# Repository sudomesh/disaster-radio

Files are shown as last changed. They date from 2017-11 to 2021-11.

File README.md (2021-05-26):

[disaster.radio](https://disaster.radio) is currently not actively developed and [seeks a new maintainer](https://github.com/sudomesh/disaster-radio/issues/110)

It is a work-in-progress long-range, low-bandwidth wireless disaster recovery mesh network powered by the sun. 

  

* [firmware/](./firmware) contains the main example code for ESP32 dev boards
* [src/](./src) contains the disaster radio library code used by the firmware and simulator
* [web/](./web) is the demo chat app served up by the disaster-radio
* [hardware/](./hardware) is the kicad board layout and schematic
* [enclosure/](./enclosure) are 3D models of the enclosure(s)
* [android app](https://github.com/beegee-tokyo/disaster-radio-android) source code for [DisasterRadio BLE Chatbox](https://play.google.com/store/apps/details?id=tk.giesecke.disaster_radio&hl=en_US) Android Application
* [mapping web app](https://github.com/sudomesh/disaster-radio-map) source code for mapping web-based appilcation

## Table of contents
- [Getting Started](#getting-started)
- [Layout and Flow](#layout-and-flow)
- [Hardware Connections](#hardware-connections)
- [Initial Setup with PlatformIO](#initial-setup-with-platformio)
    - [Building firmware](#building-firmware)
    - [Flashing firmware](#flashing-firmware)
        - [For dev boards](#for-dev-boards)
- [Building Web App](#building-web-app)
    - [Building and uploading SPIFFS image](#building-and-uploading-SPIFFS-image)
- [Testing Firmware](#testing-firmware) 
- [Adding Libraries](#adding-libraries)
- [Creating Binary for Release](#creating-binary-for-release)
- [License](#license)

# Getting Started
The quickest way to get started with disaster.radio is to buy a <a href="https://www.aliexpress.com/item/4000396836096.html" target="_blank">preinstalled device</a> or
* Download the [latest release](https://github.com/sudomesh/disaster-radio/releases)
* Unzip the `disaster-radio-0.X.X.zip` file
* Follow the included instructions for flashing it to your device

If you would rather test the latest, cutting-edge developments, you can compile the firmware yourself by cloning this repo and following the [initial setup](#initial-setup-with-platformio) instructions.

# Layout and Flow
The Disaster Radio firmware is made up of a single "server" and a number of "clients", as well as "middleware" that sits between the clients and server. These are a"server" and "clients" in the logical, software sense, not a literal, networking sense.
 
Here are the modules currently implemented with descriptions of their purpose:
- DisasterServer:  
    - DisasterRadio: the main "server" that takes messages from clients and sends them to other clients

- DisasterClient:  
    - LoRaClient: interfaces with LoRaLayer2  
    - WebSocketClient: WebSocket connections from the web app  
    - StreamClient: for Arduino Stream, currently used for serial console  
    - TCPClient: for a telnet-like server  
    - HistoryRecord: records messages to SD card (or bounded queue in memory)  
    - OLEDClient: displays messages on the screen (mostly for debugging purposes, but eventually I'd like to use this for a mobile Disaster Radio terminal of some kind)   
    - GPSClient: proof-of-concept, interfaces with a serial GPS module to beacon your current location periodically  

- DisasterMiddleware:  
    - WelcomeMessage: (very simple, in main.cpp) shows a welcome message to clients when they connect
    - HistoryReplay: shows history to clients when they connect
    - Console: implements a simple console with chat (similar to the web app) plus some /commands (I went with a more IRC-like syntax but you could easily implement a getopt version)
    
- DisasterHistory:
    - HistorySD: records history to SD card
    - HistoryMemory: records history to a bounded queue in memory (default limit 10 messages)

The server and clients communicate with each other using "datagrams" that include a destination address, a message type, and a message. Read more about the disaster radio networking stack on our wiki, https://github.com/sudomesh/disaster-radio/wiki/Layered-Model.

# Hardware Connections  

For supported development boards see the [Devices & Hardware](https://github.com/sudomesh/disaster-radio/wiki/Devices--&-Hardware) wiki page.  

The pinouts for supported boards can be found in [firmware/esp32/config.h](https://github.com/sudomesh/disaster-radio/blob/master/firmware/esp32/config.h).  

DIO0 sends an interrupt from the LoRa transceiver upon Tx/Rx Ready on the radio.   
Chip selects can be used to explicitly switch between the LoRa tranceiver and the SD card; however, the SD card should be enabled by default, as the LoRa interrupt appears to handle enabling the transceiver (note: this still needs to be thoroughly tested, what happens if you receive an interrupt while loading from the SD?).  

# Initial Setup with PlatformIO

```
pip install -U platformio
```

Edit `platformio.ini` to suit your needs. If you are flashing a ESP32 LILY TTGO board then you will probably not have to edit anything in `platformio.ini` but make sure `upload_port` is set to the correct device which may vary depending on your operating system and which other devices you have connected.

## Building firmware

To test that the firmware is compiling correctly without flashing it to a device, run
```
pio run
```

This will compile all libraries and main firmware files. The resulting binary is stored as `.pio/build/ttgo-lora32-v1/firmware.bin`

## Flashing firmware

### For dev boards

Connect your computer to the board using a usb cable,

In `platformio.ini` make sure `upload_port`, `upload_speed`, etc are correct for your device.

Then run:

```
pio run -t upload
```
 
By default, PlatformIO builds and flashes firmware for the LILY's ESP32 TTGO V2 dev board. If you would like to build for another supported board, select the corresponding build environment. For example to build and flash the firmware and file system for the ESP32 TTG0 V1 board, use the following, 

```
pio run -e ttgo-lora32-v1 -t upload -t uploadfs

```

## Developing firmware

Some useful hints for developing this firmware using platformio are included here,
* It may be a good idea to delete the libdeps folder prior to rebuilding, as old, out-dated libraries could case conflits. To do this, `rm -rf .pio/libdeps`.
* If you would like to make changes to a specific library, such as LoRaLayer2, you can clone the library into the `firmware/lib` folder that is created after running `pio run` and then comment it out or remove it from the `lib_deps` list in the `platformio.ini` file.

# Building Web App

First, build the web app using npm, instructions for can be found in [web/README.md](https://github.com/sudomesh/disaster-radio/tree/master/web#setup).

If you have trouble building the web app with npm, you can download a pre-built version of web app as part of the [latest release](https://github.com/sudomesh/disaster-radio/releases). Then, copy the files in `web/static/` from the zipped release to the `web/static/` directory in the cloned repo.

## Building and uploading SPIFFS image

Next, build the binary for the SPIFFS and upload it to your board.

To only build:

```
pio run -t buildfs
```

To build and upload:

```
pio run -t uploadfs
```

If using an SD card, copy the contents of `web/static/` to the root of a fat32 formatted SD card, then insert the SD card.

# Testing Firmware  
Once the firmware and SPIFFS image has been successfully flashed, you can test it by logging into the `disaster.radio <node-address>` wireless network and navigating to http://192.168.4.1 in a browser to access the demo chat app.  

You can also try connecting to the device via serial or telnet with commands like,  
```
pio device monitor
```
or
```
telnet 192.168.4.1
```

After pressing enter once, you should be greeted with a banner and presented with a prompt to enter a nick or send an anonymous message,
```
     ___              __                            ___    
 ___/ (_)__ ___ ____ / /____ ____      _______ ____/ (_)__ 
/ _  / (_-</ _ `(_-</ __/ -_) __/ _   / __/ _ `/ _  / / _ \
\_,_/_/___/\_,_/___/\__/\__/_/   (_) /_/  \_,_/\_,_/_/\___/
v1.0.0-rc.2
LoRa transceiver connected
Local address of your node is 1d69bd4c
Type '/join NICKNAME' to join the chat, or '/help' for more commands.
< > 
```

See [firmware/README.md](https://github.com/sudomesh/disaster-radio/tree/master/firmware) for more debugging information.

# Adding Libraries

If you're including new libraries in the firmware, for PlatformIO, you wil need to add them to `platformio.ini` under `lib_deps`.

# Creating Binary for Release

A full binary image can be created by reading the flash contents of a ESP32 that is flashed with the latest release of the firmware.
To do this, run the following command,
```
esptool.py -p /dev/ttyUSB0 -b 921600 read_flash 0 0x400000 esp_flash.bin
```

This can then be flashed to a new device like so,
```
esptool.py -p /dev/ttyUSB0 --baud 460800 write_flash 0x00000 esp_flash.bin
```

# License

* `firmware/`: Dual licensed under both GPLv3 and AGPLv3
* `web/`: AGPLv3

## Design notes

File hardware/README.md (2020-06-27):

# Hardware

The disaster.radio hardware is as open-as-possible. Currently, we have the schematic, BOM, and circuit board design for a development board that you can, theoretically, print yourself or order from a circuit board manufacturer of your choice. 

## Features
* ESP32-WROOM integrated WiFi + BLE microcontroller
* Dual LoRa modules
* Micro-SD card slot
* Micro-USB port for serial debugging
* Battery connection
* Battery charging module (currently using TPS6216)

## Developement
Our hardware was designed in KiCad, if you would like to edit the board deisgn or take a closer look at the schematics you can [download and install KiCad](https://kicad-pcb.org/download/) for your system.

After installing, open KiCad, choose `File > Open Project...`, navigate to where you cloned this repo, and select the file `hardware/board_esp32_v2/board_esp32_v2.pro`. You can now open and view the schematic and pcb design.

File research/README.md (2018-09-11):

research regarding disaster radio, lora modulation, and network stacks  

none of the material in this directory is licensed to sudomesh unless otherwise noted

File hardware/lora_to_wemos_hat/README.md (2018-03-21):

# lora-to-nodemcu-circuit

KiCad Circuit board for a Lora (RFM95) to the Wemo D1 Mini ESP8266 board connector for playing around with the two technologies. This board acts as a hat for the Wemo, and contains the lora chip, antenna and power circuits for powering the lora chip off of the 5v coming off of the Wemo's usb power.
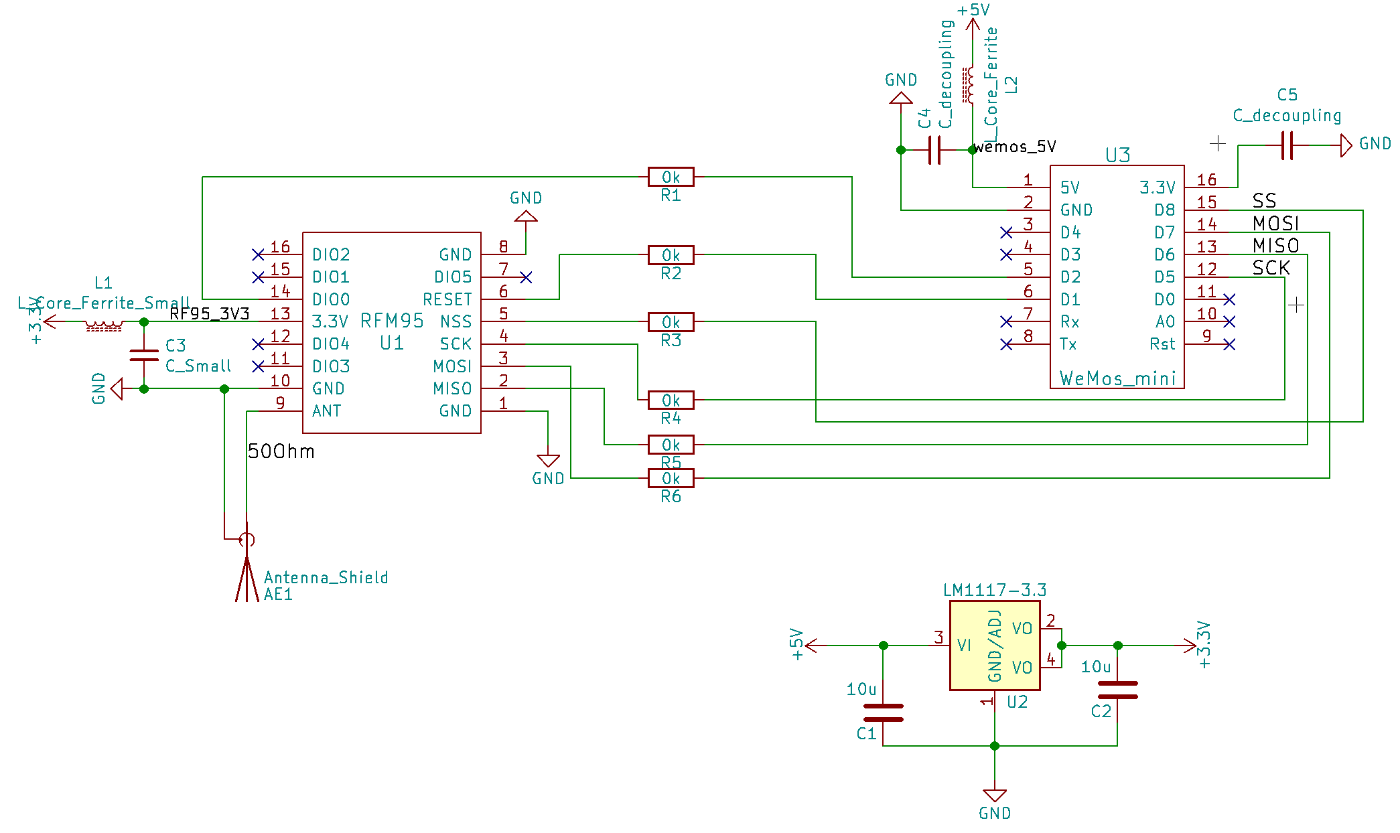
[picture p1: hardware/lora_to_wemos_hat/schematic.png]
schematic

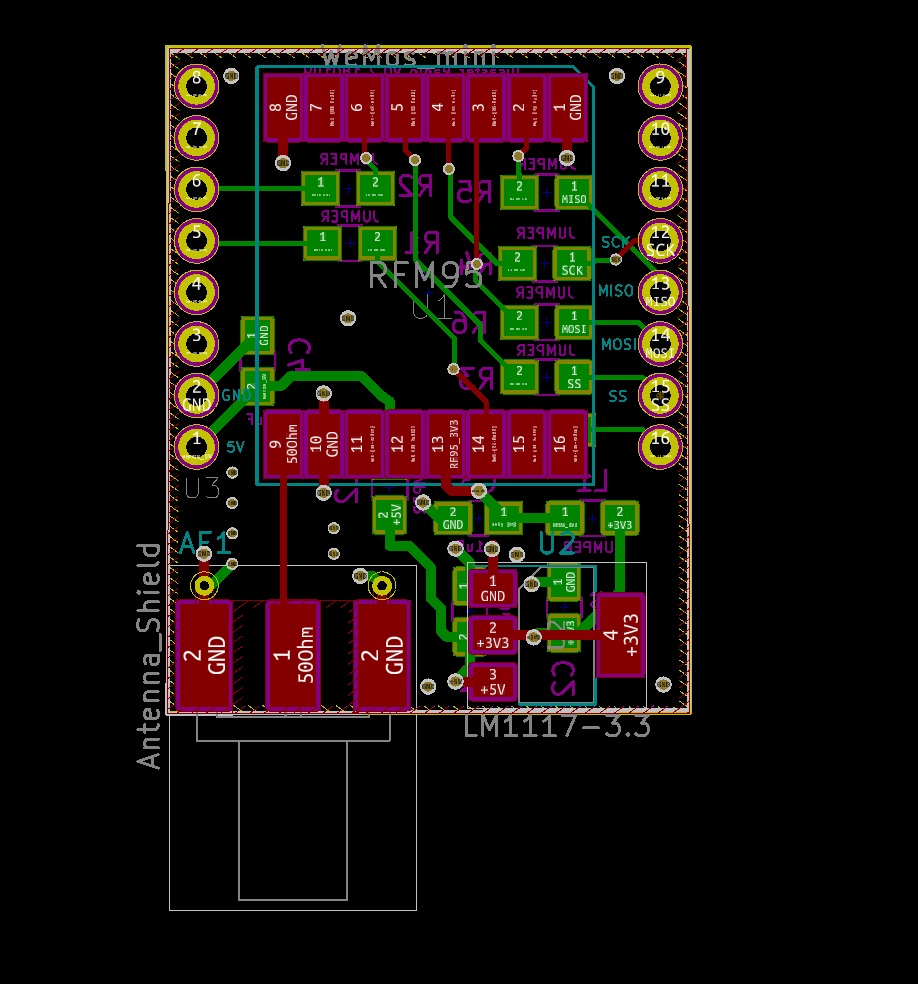
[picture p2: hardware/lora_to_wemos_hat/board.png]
board


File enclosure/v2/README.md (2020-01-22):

# Disaster Radio Enclosure v2

### The Challenge

We need a new design for the disaster radio enclosure. The main components that it needs to house/support are:

- a solar panel
- a PCB
- a battery
- an antenna

There is a nice video of the v0 enclosure on [this page](https://disaster.radio/updates/). Unfortunately, it had some problems:

- problem 1
- problem 2

We need two new designs:

1) one that can be produced in small quantities

2) one that can be mass-produced

### Budget

The project is mostly a labor of love, organized by volunteers, but we do have some budget. So far we've been paying two of our volunteers $35/hr to work on the firmware and PCB (i.e. well-below market rate).

### Photos

Photo of v0 enclosure

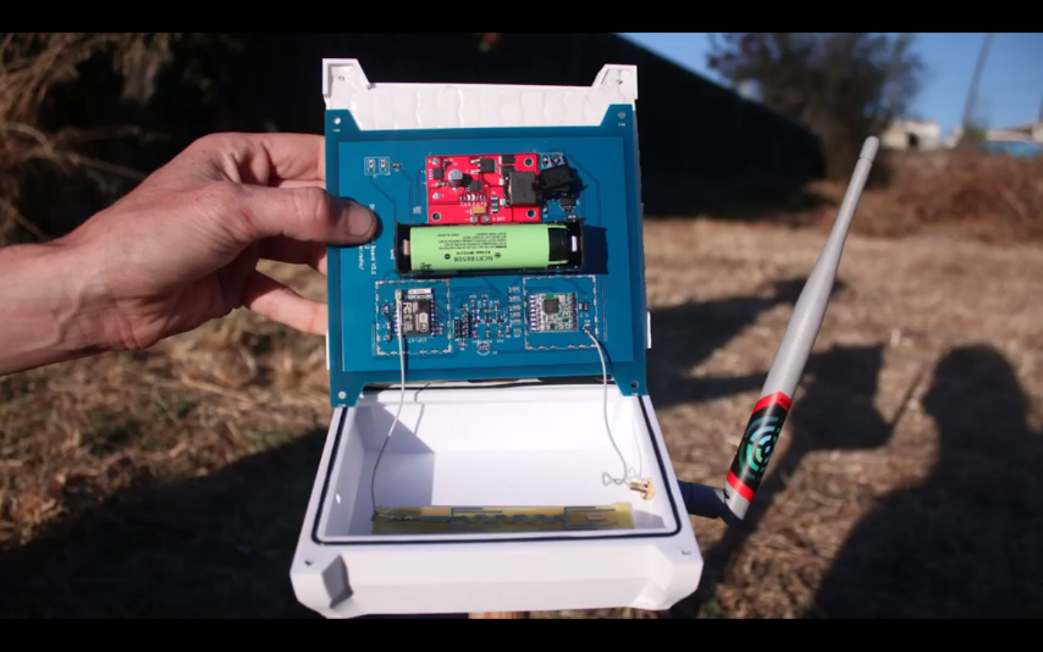
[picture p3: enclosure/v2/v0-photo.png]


Rendering of v0 enclosure

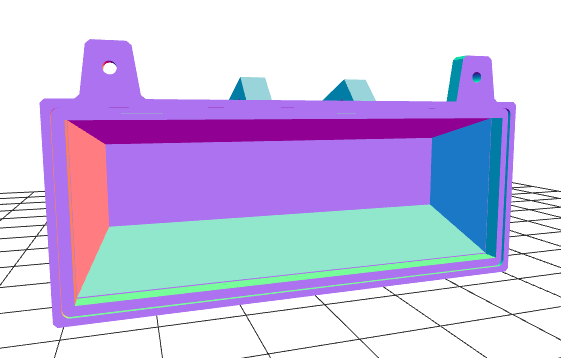
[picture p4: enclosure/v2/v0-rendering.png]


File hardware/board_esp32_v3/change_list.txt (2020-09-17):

@board_esp32_v32 changelist

--nothing yet

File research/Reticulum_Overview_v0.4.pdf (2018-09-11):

# Reticulum Overview

This paper will briefly describe the overall purpose and operating principles of Reticulum, a networking stack designed for reliable and secure communication over high-latency, low-bandwidth links. It should give you an overview of how the stack works, and an understanding of how to develop networked applications using Reticulum.

This document is not an exhaustive source of information on Reticulum, at least not yet. Currently, the best place to go for such information is the Python reference implementation of Reticulum. Both the reference implementation and this document may (and will) change rapidly in the current phase of development, but historical versions will always be available in the Git repositories.

After reading this document, you should be well-equipped to understand how a Reticulum network operates, what it can achieve, and how you can use it yourself. If you want to help out with the development, this is also the place to start, since it will also provide a pretty clear overview of the sentiments and the philosophy behind Reticulum.

## Motivation

The primary motivation for designing and implementing Reticulum has been the current lack of reliable, functional and secure minimal-infrastructure modes of digital communication. It is my belief that it is highly desirable to create a cheap and reliable way to set up a wide-range digital communication network that can securely allow exchange of information between people and machines, with no central point of authority, control, censorship or barrier to entry.

Almost all of the various networking stacks in wide use today share a common limitation, namely that they require large amounts of coordination to work. You can’t just plug in a bunch of ethernet cables to the same switch, or turn on a number of WiFi radios, and expect such a setup to provide a reliable platform for communication.

The designers of the Internet Protocol had the foresight to create a protocol that powers the modern Internet, and works brilliantly in world very different from when it was conceived. But networks using the traditional IP stack needs large amounts of coordination from the people involved, and without central actors in ultimate control of network segments, it is very easy for a single person to render the platform unusable for everyone else. These limitations are inherent to the design principles of IP, and during the design of IP, this was a very reasonable tradeoff indeed.

Reticulum aims to require as little coordination and trust as possible. In fact, the only “coordination” required is to know how to get connected to a Reticulum network. Since Reticulum is medium agnostic, this could be whatever is best suited to the situation. In some cases, this might be 1200 baud packet radio links over VHF frequencies, in other cases it might be a microwave network using off-the-shelf radios. At the time of release of this document, the recommended setup is using cheap LoRa radio modules with an open source firmware (see the chapter Reference System Setup), connected to a small computer like a Raspberry Pi. As an example, the default reference setup provides a channel capacity of 5.4 Kbps, and a usable direct node-to-node range of around 15 kilometers (indefinitely extendable by using multiple hops).

Reticulum Overview v0.3 - April 2018 | unsigned.io/reticulum | Page 1 of 13

## Goals

To be as widely usable and easy to implement as possible, the following goals have been used to guide the design of Reticulum:

- Fully useable as open source software stack
Reticulum must be implemented, and be able to run using only open source software. This is critical to ensuring availability, security and transparency of the system.
- Hardware layer agnosticism
Reticulum shall be fully hardware agnostic, and should be useable over a wide range physical networking layers, such as data radios, serial lines, modems, handheld transceivers, wired ethernet, wifi, or anything else that can carry a digital data stream. Hardware made for dedicated Reticulum use shall be as cheap as possible and use off-the-shelf components, so it can be easily replicated.
- Very low bandwidth requirements
Reticulum should be able to function reliably over links with a data capacity as low as 1,000 bps.
- Encryption by default
Reticulum must use encryption by default where possible and applicable.
- Unlicensed use
Reticulum shall be functional over physical communication mediums that do not require any form of license to use. Reticulum must be designed in a way, so it is usable over ISM radio frequency bands, and can provide functional long distance links in such conditions.
- Supplied software
Apart from the core networking stack and API, that allows any developer to build applications with Reticulum, a basic communication suite using Reticulum must be implemented and released at the same time as Reticulum itself. This shall serve both as a functional communication suite, and as an example and learning resource to others wishing to build applications with Reticulum.
- Ease of use
The reference implementation of Reticulum is written in Python, to make it very easy to use and understand. Any programmer with only basic experience should be able to use Reticulum in their own applications.
- Low cost
It shall be as cheap as possible to deploy a communication system based on Reticulum. This should be achieved by using cheap off-the-shelf hardware that potential users might already own. The cost of setting up a functioning node should be less than $100 even if all parts needs to be purchased.
Reticulum Overview v0.3 - April 2018 | unsigned.io/reticulum | Page 2 of 13

# Introduction & Basic Functionality

Reticulum is a networking stack suited for high-latency, low-bandwidth links. Reticulum is at it’s core message oriented, but can provide connection oriented sessions. It is suited for both local point-to-point or point-to-multipoint scenarios where alle nodes are within range of each other, as well as scenarios where packets need to be transported over multiple hops to reach the recipient.

Reticulum does away with the idea of addresses and ports known from IP, TCP and UDP. Instead Reticulum uses the singular concept of destinations. Any application using Reticulum as it’s networking stack will need to create one or more destinations to receive data, and know the destinations it needs to send data to.

Reticulum encrypts all data by default using public-key cryptography. Any message sent to a destination is encrypted with that destinations public key. Reticulum also offers symmetric key encryption for group-oriented communications, as well as unencrypted packets for broadcast purposes, or situations where you need the communication to be in plain text. The multi-hop transport, coordination, verification and reliability layers are fully autonomous and based on public key cryptography.

Reticulum can connect to a variety of interfaces such as radio modems, data radios and serial ports, and offers the possibility to easily tunnel Reticulum traffic over IP links such as the Internet or private IP networks.

## Destinations

To receive and send data with the Reticulum stack, an application needs to create one or more destinations. Reticulum uses three different basic destination types, and one special:

- Single
The single destination type defines a public-key encrypted destination. Any data sent to this destination will be encrypted with the destination’s public key, and will only be readable by the creator of the destination.
- Group
The group destination type defines a symmetrically encrypted destination. Data sent to this destination will be encrypted with a symmetric key, and will be readable by anyone in possession of the key. The group destination can be used just as well by only two peers, as it can by many.
- Plain
A plain destination type is unencrypted, and suited for traffic that should be broadcast to a number of users, or should be readable by anyone.
- Link
A link is a special destination type, that serves as an abstract channel between two single destinations, directly connected or over multiple hops. The link also offers reliability and more efficient encryption, and as such is useful even when nodes are directly connected.
Reticulum Overview v0.3 - April 2018 | unsigned.io/reticulum | Page 3 of 13

## Destination Naming

Destinations are created and named in an easy to understand dotted notation of aspects, and represented on the network as a hash of this value. The hash is a SHA-256 truncated to 80 bits. The top level aspect should always be the a unique identifier for the application using the destination. The next levels of aspects can be defined in any way by the creator of the application. For example, a destination for a messaging application could be made up of the application name and a username, and look like this:

name: simplemessenger.someuser hash: 2a7ddfab5213f916dea9

For the single destination, Reticulum will automatically append the associated public key as a destination aspect before hashing. This is done to ensure only the correct destination is reached, since anyone can listen to any destination name. Appending the public key ensures that a given packet is only directed at the destination that holds the corresponding private key to decrypt the packet. It is important to understand that anyone can use the destination name simplemessenger.myusername, but each person that does so will still have a different destination hash, because their public keys will differ. In actual use of single destination naming, it is advisable not to use any uniquely identifying features in aspect naming, though. In the simple messenger example, when using single destinations, we would instead use a destination naming scheme such as simplemessenger.user where appending the public key expands the destination into a uniquely identifying one.

To recap, the destination types should be used in the following situations:

- Single
When private communication between two endpoints is needed. Supports routing.
- Group
When private communication between two or more endpoints is needed. More efficient in data usage than single destinations. Supports routing indirectly, but must first be established through a single destination.
- Plain
When plain-text communication is desirable, for example when broadcasting information.

To communicate with a single destination, you need to know it’s public key. Any method for obtaining the public key is valid, but Reticulum includes a simple mechanism for making other nodes aware of your destinations public key, called the announce.

Note that this information could be shared and verified in many other ways, and that it is therefore not required to use the announce functionality, although it is by far the easiest, and should probably be used if you are not confident in how to verify public keys and signatures manually.

Reticulum Overview v0.3 - April 2018 | unsigned.io/reticulum | Page 4 of 13

## Public key announcements

An announce will send a special packet over any configured interfaces, containing all needed information about the destination hash and public key, and can also contain some additional, application specific data. The entire packet is signed by the sender to ensure authenticity. It is not required to use the announce functionality, but in many cases it will be the simplest way to share public keys on the network. As an example, an announce in a simple messenger application might contain the following information:

- The announcers destination hash
- The announcers public key
- Application specific data, in this case the users nickname and availability status
- A random blob, making each new announce unique
- A signature of the above information, verifying authenticity

With this information, any Reticulum node that receives it will be able to reconstruct an outgoing destination to securely communicate with that destination. You might have noticed that there is one piece of information lacking to reconstruct full knowledge of the announced destination, and that is the aspect names of the destination. These are intentionally left out to save bandwidth, since they will be implicit in almost all cases. If a destination name is not entirely implicit, information can be included in the application specific data part that will allow the receiver to infer the naming.

It is important to note that announcements will be forwarded throughout the network according to a certain pattern. This will be detailed later. Seeing how single destinations are always tied to a private/public key pair leads us to the next topic.

Reticulum Overview v0.3 - April 2018 | unsigned.io/reticulum | Page 5 of 13

## Identities

In Reticulum, an identity does not necessarily represent a personal identity, but is an abstraction that can represent any kind of verified entity. This could very well be a person, but it could also be the control interface of a machine, a program, robot, computer, sensor or something else entirely. In general, any kind of agent that can act, or be acted upon, or store or manipulate information, can be represented as an identity.

As we have seen, a single destination will always have an identity tied to it, but not plain or group destinations. Destinations and identities share a multilateral connection. You can create a destination, and if it is not connected to an identity upon creation, it will just create a new one to use automatically. This may be desirable in some situations, but often you will probably want to create the identity first, and then link it to created destinations.

Building upon the simple messenger example, we could use an identity to represent the user of the application. Destinations created will then be linked to this identity to allow communication to reach the user. In such a case it is of great importance to store the user’s identity securely and privately.

## Getting Further

The above functions and principles form the core of Reticulum, and would suffice to create functional networked applications in local clusters, for example over radio links where all interested nodes can hear each other. But to be truly useful, we need a way to go further. In the next chapter, two concepts that allow this will be introduced, paths and resources.

Reticulum Overview v0.3 - April 2018 | unsigned.io/reticulum | Page 6 of 13

# Transport

I have purposefully avoided the term routing until now, and will continue to do so, because the current methods of routing used in IP based networks are fundamentally incompatible for the link types that Reticulum was designed to handle. These routing methodologies assume trust at the physical layer. Since Reticulum is designed to run over open radio spectrum, no such trust exists. Furthermore, existing routing protocols like BGP or OSPF carry too much overhead to be practically useable over bandwidth-limited, high-latency links.

To overcome such challenges, Reticulum’s Transport system uses public-key cryptography to implement the concept of paths that allow discovery of how to get information to a certain destination, and resources that help alleviate congestion and make reliable communication more efficient and less bandwidth-hungry.

## Threading a Path

In networks with changing topology and trustless connectivity, nodes need a way to establish verified connectivity with each other. To do this, the following process is employed:

- First, the node that wishes to establish connectivity will send out a special packet, that traverses the network and locates the desired destination. Along the way, the nodes that forward the packet will take note of this link request.
- Second, if the destination accepts the link request, it will send back a packet that proves the authenticity of it’s identity (and the receipt of the link request) to the initiating node. All nodes that initially forwarded the packet will also be able to verify this proof, and thus accept the validity of the link throughout the network.
- When the validity of the link has been accepted by forwarding nodes, these nodes will remember the link, and it can subsequently be used by referring to a hash representing it.
- As a part of the link request, a key exchange takes place, that sets up an efficient symmetrically encrypted tunnel between the two nodes. As such, this mode of communication is preferred, even for situations when nodes can directly communicate, when the amount of data to be exchanged numbers in the tens of packets.
- When a link has been set up, it automatically provides message receipt functionality, so the sending node can obtain verified confirmation that the information reached the intended recipient.

In a moment, we will discuss the specifics of how this methodology is implemented, but let’s first recap what purposes this serves. We first ensure that the node answering our request is actually the one we want to communicate with, and not a malicious actor pretending to be so. At the same time we establish an efficient encrypted channel. The setup of this is relatively cheap in terms of bandwidth, so it can be used just for a short exchange, and then recreated as needed, which will also rotate encryption keys (keys can also be rotated over an existing path), but the link can also be kept

Reticulum Overview v0.3 - April 2018 | unsigned.io/reticulum | Page 7 of 13

alive for longer periods of time, if this is more suitable to the application. The amount of bandwidth used on keeping a link open is practically negligible. The procedure also inserts the link id, a hash calculated from the link request packet, into the memory of forwarding nodes, which means that the communicating nodes can thereafter reach each other simply by referring to this link id.

Step 1, pathfinding

The pathfinding method builds on the announce functionality discussed earlier. When an announce is sent out by a node, it will be forwarded by anyone node receiving it, but according to some specific rules:

- If this announce has already been received before, ignore it.
- Record into a table which node the announce was received from, and how many times in total it has been retransmitted to get here.
- If the announce has been retransmitted m+1 times, it will not be forwarded. By default, m is set to 18.
- The announce will be assigned a delay d = ch seconds, where c is a decay constant, by default 2, and h is the amount of times this packet has already been forwarded.
- The packet will be given a priority p = 1/d.
- If at least d seconds has passed since the announce was received, and no other packets with a priority higher than p are waiting in the queue (see Packet Prioritisation), and the channel is not utilized by other traffic, the announce will be forwarded.
- If no other nodes are heard retransmitting the announce with a greater hop count than when it left this node, transmitting it will be retried r times. By default, r is set to 2. Retries follow same rules as above, with the exception that it must wait for at least d = ch+1 + t seconds, ie., the amount of time it would take the next node to retransmit the packet. By default, t is set to 1.
- If a newer announce from the same destination arrives, while an identical one is already in the queue, the newest announce is discarded. If the newest announce contains different application specific data, it will replace the old announce, but will use d and p of the old announce.

Once an announce has reached a node in the network, any other node in direct contact with that node will be able to reach the destination the announce originated from, simply by sending a packet adressed to that destination. Any node with knowledge of the announce will be able to direct the packet towards the destination by looking up the next node with the shortest amount of hops to the destination. The specifics of this process is detailed in Path Calculation.

According to these rules and default constants, an announce will propagate throughout the network in a predictable way. In an example network utilising the default constants, and with an average link distance of Lavg = 15 kilometers, an announce will be able to propagate outwards to a radius of 180

Reticulum Overview v0.3 - April 2018 | unsigned.io/reticulum | Page 8 of 13

kilometers in 34 minutes, and a maximum announce radius of 270 kilometers in approximately 3 days. Methods for overcoming the distance limitation of m * Lavg will be introduced later in this chapter.

Step 2, link establishment

After seeing how the conditions for finding a path through the network are created, we will now explore how two nodes can establish reliable communications over multiple hops. The link in Reticulum terminology should not be viewed as a direct node-to-node link on the physical layer, but as an abstract channel, that can be open for any amount of time, and can span an arbitrary number of hops, where information will be exchanged between two nodes.

- When a node in the network wants to establish verified connectivity with another node, it will create a link request packet, and broadcast it.
- The link request packet contains the destination hash Hd, and an asymmetrically encrypted part containing the following data: The source hash Hs, a symmetric key Lk, a truncated hash of a random number Hr, and a signature S of the plaintext values of Hd, Hs, Lk and Hr.
- The broadcasted packet will be directed through the network according to the rules laid out previously.
- Any node that forwards the link request will store a link id in it’s link table, along with the amount of hops the packet had taken when received. The link id is a hash of the entire path request packet. If the path is not proven within some set amount of time, the entry will be dropped from the table again.
- When the destination receives the link request packet, it will decide whether to accept the request. If it is accepted, it will create a special packet called a proof. A proof is a simple construct, consisting of a truncated hash of the message that needs to be proven, and a signature (made by the destination’s private key) of this hash. This proof effectively verifies that the intended recipient got the packet, and also serves to verify the discovered path through the network. Since the proof hash matches the path id in the intermediary nodes’ path tables, the intermediary nodes can forward the proof all the way back to the source.
- When the source receives the proof, it will know unequivocally that a verified path has been established to the destination, and that information can now be exchanged reliably and securely.

It’s important to note that this methodology ensures that the source of the request does not need to reveal any identifying information. Only the intended destination will know “who called”, so to speak. This is a huge improvement to protocols like IP, where by design, you have to reveal your own address to communicate with anyone, unless you jump through a lot of hoops to hide it. Reticulum offers initiator anonymity by design.

When using links, Reticulum will automatically verify anything sent over the link, and also automates retransmissions if parts of a message was lost along the way. Due to the caching features

Reticulum Overview v0.3 - April 2018 | unsigned.io/reticulum | Page 9 of 13

of Reticulum, such a retransmission does not need to travel the entire length of an established path. If a packet is lost on the 8th hop of a 12 hop path, it can be fetched from the last hop that received it reliably.

## Crossing Continents

When a packet needs to travel farther than local network topology knowledge stretches, a system of geographical or topological hinting is used to direct the packet towards a network segment with direct knowledge of the intended destination. This functionality is currently left out of the protocol for simplicity of testing other parts, but will be activated in a near future release. For more information on when, refer to the roadmap on the website.

## Resourceful Memory

In traditional networks, large amounts of data is rapidly exchanged with very low latency. Links of several thousand kilometers will often only have round-trip latency in the tens of milliseconds, and as such, traditional protocols are often designed to not store any transmitted data at intermediary hops. If a transmission error occurs, the sending node will simply notice the lack of a packet acknowledgement, and retransmit the packet all the way, until it hears back from the receiver that it got the intended data.

In bandwidth-limited and high-latency conditions, such behaviour quickly causes congestion on the network, and communications that span many hops become exceedingly expensive in terms of bandwidth usage, due to the higher risk of some packets failing.

Reticulum alleviates this in part with it’s path discovery methodology, and in part by implementing resource caching at all nodes that can support it. Network operation can be made much more efficient by caching everything for a period of time, and given the availability of cheap memory and storage, this is a very welcome tradeoff. A gigabyte of memory can store millions of Reticulum packets, and since everything is encrypted by default, the storing poses very little privacy risk.

In a Reticulum network, any node that is able to do so, should cache as many packets as it’s
memory will allow for. When a packet is received, a timestamp and a hash of the packet is stored along with the full packet itself, and it will be kept in storage until the allocated cache storage is full, whereupon the packet that was last accessed in the cache will be deleted. If a packet is accessed from the cache, it’s timestamp will be updated to the current time, to ensure that packets that are used stay in the cache, and packets that are not used are dropped from memory.

Some packet types are stored in separate caching tables, that allow easier lookup for other nodes. For example, an announce is stored in a way, that allows other nodes to request the public key for a certain destination, and as such the network as a whole operates as a distributed key ledger.

For more details on how the caching works and is used, see the reference implementation source code.

Reticulum Overview v0.3 - April 2018 | unsigned.io/reticulum | Page 10 of 13

# Reference System Setup

This section will detail the recommended Reference System Setup for Reticulum. It is important to note that Reticulum is designed to be usable over more or less any medium that allows you to send and receive data in a digital form, and satisfies some very low minimum requirements. The communication channel must support at least half-duplex operation, and provide an average throughput of around 1000 bits per second, and supports a physical layer MTU of 500 bytes. The Reticulum software should be able to run on more or less any hardware that can provide a Python runtime environment.

That being said, the reference setup has been outlined to provide a common platform for anyone who wants to help in the development of Reticulum, and for everyone who wants to know a recommended setup to get started. A reference system consists of three parts:

- A channel access device
Or CAD, in short, provides access to the physical medium whereupon the communication takes place, for example a radio with an integrated modem. A setup with a separate modem connected to a radio would also be termed a “channel access device”.
- A host device
Some sort of computing device that can run the necessary software, communicates with the channel access device, and provides user interaction.
- A software stack
The software implementing the Reticulum protocol and applications using it.

The reference setup can be considered a relatively stable platform to develop on, and also to start building networks on. While details of the implementation might change at the current stage of development, it is the goal to maintain hardware compatibility for as long as entirely possible, and the current reference setup has been determined to provide a functional platform for many years into the future. The current Reference System Setup is as follows:

- Channel Access Device
A data radio consisting of a LoRa radio module, and a microcontroller with open source firmware, that can connect to host devices via USB. It operates in either the 430, 868 or 900 MHz frequency bands. More details on the exact parts and how to get/make one can be found on the website.
- Host device
Any computer device running Linux and Python. A Raspberry Pi with Raspbian is recommended.
- Software stack
The current Reference Implementation Release of Reticulum, running on a Debian based operating system.
Reticulum Overview v0.3 - April 2018 | unsigned.io/reticulum | Page 11 of 13

It is very important to note, that the reference channel access device does not use the LoRaWAN standard, but uses a custom MAC layer on top of the plain LoRa modulation! As such, you will need a plain LoRa radio module connected to an MCU with the correct Reticulum firmware. Full details on how to get or make such a device is available on the website.

With the current reference setup, it should be possible to get on a Reticulum network for around 70$ even if you have none of the hardware already.

Reticulum Overview v0.3 - April 2018 | unsigned.io/reticulum | Page 12 of 13

# Protocol Specifics

This chapter will detail protocol specific information that is essential to the implementation of Reticulum, but non critical in understanding how the protocol works on a general level. It should be treated more as a reference than as essential reading.

## Node Types

Currently Reticulum defines two node types, the Station and the Peer. A node is a station if it fixed in one place, and if it is intended to be kept online at all times. Otherwise the node is a peer. This distinction is made by the user configuring the node, and is used to determine what nodes on the network will help forward traffic, and what nodes rely on other nodes for connectivity.

## Packet Prioritisation

The packet prioritisation algorithms are subject to rapid change at the moment, and for now, they are not documented here. See the reference implementation for more info on how this functionality works.

## Path Calculation

The path calculation algorithms are subject to rapid change at the moment, and for now, they are not documented here. See the reference implementation for more info on how this functionality works.

## Binary Packet Format

The binary packet format is subject to rapid change at the moment, and for now, it is not documented here. See the reference implementation for the specific details on this topic.

Reticulum Overview v0.3 - April 2018 | unsigned.io/reticulum | Page 13 of 13

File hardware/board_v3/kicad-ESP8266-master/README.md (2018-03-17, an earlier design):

kicad-ESP8266 - a library for KiCAD
=====================================
This project has both schematic symbols, footprints, and 3d models for
ESP8266 based modules. It is a work-in-progress. Additions and
corrections are welcome. Enter a pull request or file an issue on
GitHub.

The present modules are:

  * ESP-01  - Note that there are two versions of this module available on
              open market. The schematic symbol is for the `v090` version
              which is probably the same as the `v080`. There is an older
              version that does not include any GPIO signals. The footprint
              is the same for all of the ESP-01 modules.

  * ESP-12  - This is includes an alias part, ESP-07v2, that is suitable
              for the 16 pin variant of the ESP-07. Note that there is a 14
              pin version of the ESP-07 that has different signals and
              pinout. The footprint for the ESP-12 (and ESP-07v2)
              elongated through-hole pads to match those modules.

  * ESP-201 - This is a 26 pin module with pins on 0.1 inch spacing. I
              could not find any official measurements for the pin
              locations so the footprint was created from empirical
              measurements on the unit I have.

  * ESP-12E - This is for the 22 pin variant of the ESP-12. ~~Though all the 
              esp-12 signals are in the same place on ESP-12E, pin numbers
              have changed.~~ As of 2016/12/06 the pin numbers on the
              ESP-12E have been changed to be compatible with the
              ESP-12. If you need the old pin numbers they are still
              available on the `oldNumbers` branch.

  * ESP-07v2 - ESP-07 that is pin compatible with the ESP-12.

  * ESP-13-WROOM-02

  * There is a footprint for the ESP-06, but no supporting
      schematic symbol.

There are 3d models for the ESP-07v2, ESP-13, ESP-12 and ESP-12E.

WARNINGS
---------
  1. The symbols, footprints, and 3d models have not been tested. They are
     based on published images and measurements on individual samples.

  2. The `.dcm` file contains HTML links to information on sites I used
     when creating this library, however I do not have any control over
     the sites themselves. Follow the links with caution.

  3. This library distributed in the hope that it will be useful,
     but __WITHOUT ANY WARRANTY; without even the implied warranty of__
     __MERCHANTABILITY or FITNESS FOR A PARTICULAR PURPOSE__.

Use
---
 1. Clone this archive to a convenient location on your computer. These are
    the commands I use on Linux to create a copy in
    `~/kicad/libraries/kicad-ESP8266`:

        mkdir -p ~/kicad/libraries/
        cd ~/kicad/libraries/
        git clone https://github.com/jdunmire/kicad-ESP8266

 2. Add `ESP8266.lib` to the Component Libraries:

        eeschema:Preferences->Component Libraries->Add

 3. Add `ESP8266.pretty` to the Footprint Libraries:

        pcbnew:Preferences->Footprint Libraries Wizard

 4. To make the 3d models usable, add the location from step #1 to list
    of configured paths as `ESPLIB`. Use a full path. Continuing with
    the example step #1:

        kicad:Preferences->Configure Paths->Add

            Name: ESPLIB
            Path: /home/<your_login_name>/kicad/libraries/kicad-ESP8266

3D Models
---------
The 3D models were built using [OpenSCAD](http://www.openscad.org/) and
then colored in [Wings3D](http://www.wings3d.com/) to produce the VRML
(`.wrl`) format for KiCAD. Wings3D requires a binary STEP format, but
OpenSCAD writes an ASCII version.
[meshconv](http://www.patrickmin.com/meshconv/) will convert the
ASCII format to a binary format.

Here is the workflow I used:

 1. Use OpenScad to build the model. Export the model as STL.
    * Build using F6
    * File->Export...->Export as STL...

 2. Use `meshconv` to translate the file to binary.

        $ meshconv -c stl <STL-FILE-FROM-OpenSCAD> -o <FILENAME>

 3. Now open Wings3d and import the the `FILENAME.stl` as a
 _StereoLithography Binary File (*.stl)_.

 4. Assign colors.

 5. Export as _VRML 2.0 File (*.wrl)_

 6. The 3D model probably needs to be scaled to match the footprint. Use
    the `kicad:Footprint Editor:Edit->Edit Properties->3D Settings`
    dialog. For the ESP-12, the `Shape Scale` X, Y, and Z values are
    0.393700.

This repository includes all the intermediate files:

  * `.scad` - OpenSCAD model
  * `.stl` - OpenSCAD STL
  * `_4wings.stl` - STL file converted by `meshconv`
  * `.wings` - Wings3D model
  * `.wrl` - VRML model for KiCAD

License
-------
Copyright 2015,2016 J.Dunmire

Contact: jedunmire PLUS kicad-ESP8266 AT gmail DOT com

This file is part of kicad-ESP8266. 

kicad-ESP8266 is licensed under the Creative Commons Attribution-ShareAlike
4.0 International License. To view a copy of this license visit
http://creativecommons.org/licenses/by-sa/4.0/.

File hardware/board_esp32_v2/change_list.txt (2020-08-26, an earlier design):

@board esp32_board HW changes

board_esp32 changes
flip around sd-card slot ***
increase usb and micro-sd bad length for hand soldering ***
find more common switch ***
maybe add atmega chip for optional development ???
fix lora (small) footprint ***
make E22-900M30S only connect to 3V3 or Vbatt NOT both! **
remove copper form underneath esp32 antenna ***
fix usb plus and minus reverse *** 

todo_200811

switching LORA1_DIO2 to IO26 and LORA1_RXEN to IO21 ****
connect LORAx_DIO1 pins instead of LORAx_DIO2 to ESP32 ***
	add solderbridge between the two LORAxDIO1 lines  ****
connect LORAx_DIO2 pins to LORAx_TXEN (for SetDio2AsRfSwitchCtrl)  ****
switch wroom module ****

-possible changes:
hook up SENSOR_VP/VN as inputs ***
remove or repurpose LORA leds, connect to dio2 and txen **

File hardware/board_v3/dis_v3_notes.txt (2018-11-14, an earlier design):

@disaster radio board v3 notes

@fixes

@todos

@notes

undervoltage lockout threshold is 3.1 to 4.4, minimum input voltage is 4.5V

mppt set voltage on CN3971 module, set by 
	Vmppt = 1.205 x (1 + R1 / R2) (according to module to silkscreen)
	note that (R3 is R1, R4 is R2) as specified in cn3791 datasheet
easy calculation with R2 = 10K
	R1 = ((Vmppt / 1.205) - 1) * 10K
	e.g for 6V,  Vmppt R1 = 39.8KOhms (closes common value is 39kohm)

current limit 
	Ich = 120mV / R5 (note R5 is Rcs in datasheet, it is the very big resistor)
	R5 = 0.04 Ohms
	Ich = 3A 
	this seems way, way to high

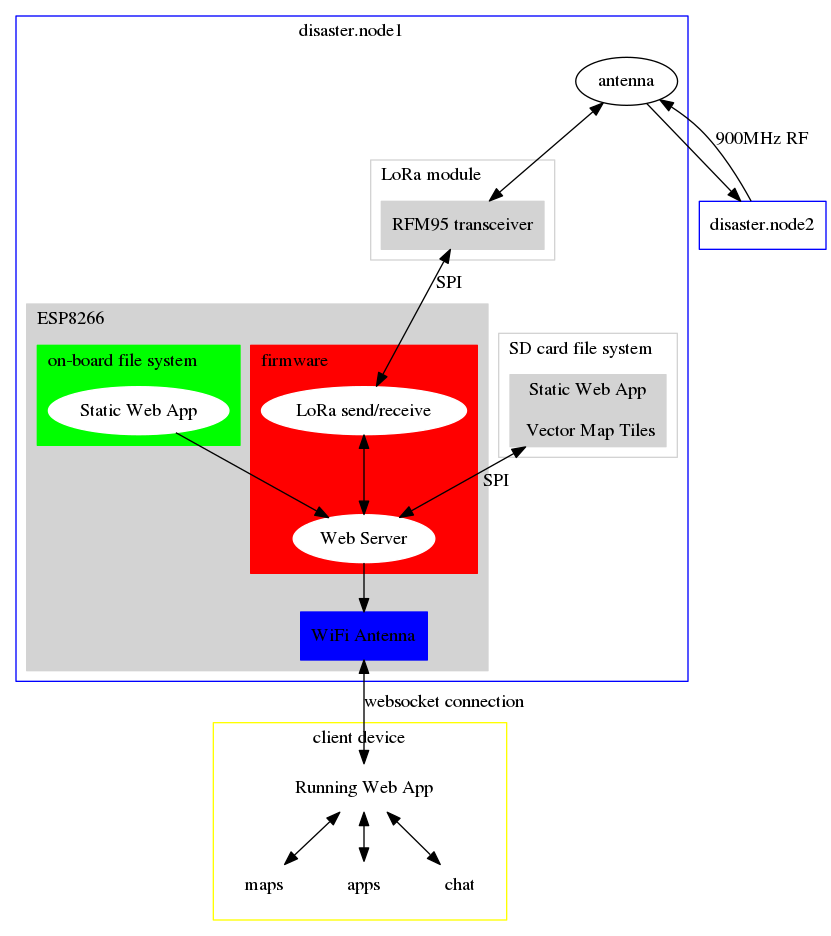
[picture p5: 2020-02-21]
diagram.png

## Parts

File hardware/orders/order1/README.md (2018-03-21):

This was a PCB only order from Seeed Fusion PCB.

The boards had a bug in the connections requiring manually adding wires to bypass the problem and had no decoupling capacitors for the voltage regulator.

Only visual inspection testing was requested and no impedance control was specified.

Total cost: ~$30 (including shipping)
Paid for by: juul

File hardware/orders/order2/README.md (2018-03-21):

This was a low volume PCB only order from OSH Park and due to what was probably an issue with KiCAD the mask was off by enough that soldering to some exposed pads caused them to be connected to the ground plane.

Total cost: ?
Paid for by: Fitz

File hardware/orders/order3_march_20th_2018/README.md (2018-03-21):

This was a PCB + assembly order from Seeed Fusion PCBA.

The `gerber` directory contains the gerbers exactly as ordered (other than the fact that they were zipped for upload) and the `.csv` is the BOM exactly as submitted.

The following parts were not assembled by Seeed:

* ESP8266
* RFM95
* SMA connector

It was ordered on March 20th 2018.

Only visual inspection testing was requested and no impedance control was specified.

Total cost: $207.21 (including shipping)
Paid for by: juul

PCBA Quantity - 50
PCB Dimensions - 33mm*26mm
Impedance Control - No
Surface Finish - HASL
Minimum Solder Mask Dam - 0.4mm↑
Copper Weight - 1oz.
Plated Half-holes / Castellated Holes - No
Minimum Drill Hole Size - 0.3mm
PCB Color - Blue
Base Material - FR-4 TG130
No. of Layers - 4 layers
PCB Quantity - 50
Blind or Buried Vias - No
PCB Thickness - 1.6
Trace Width / Spacing - 6/6 mil
No. of Different Designs - 1
Expedited Option - No

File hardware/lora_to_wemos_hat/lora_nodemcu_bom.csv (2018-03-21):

Id | Designator | Package | Quantity | Designation | Supplier and ref
1 | U3 | D1_mini_board | 1 | WeMos_mini
2 | C3,C5,C4 | C_0805_HandSoldering | 3 | 0.1uF
3 | L2,L1 | L_0805_HandSoldering | 2 | JUMPER
4 | AE1 | Molex_SMA_Jack_Edge_Mount | 1 | Antenna_Shield
5 | C1,C2 | C_0805_HandSoldering | 2 | 10uF
6 | R1,R2,R3,R4,R5,R6 | R_0805_HandSoldering | 6 | JUMPER
7 | U1 | RFM95 | 1 | RFM95
8 | U2 | SOT-223 | 1 | LM1117-3.3

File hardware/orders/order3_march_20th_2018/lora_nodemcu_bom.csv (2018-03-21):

Part/Designator | Manufacture Part Number/Seeed SKU | Quantity
C3,C5,C4 | 302010165 | 3 | 0.1uF
C1,C2 | 302010158 | 2 | 10uF
U2 | 310030097 | 1 | LM1117-3.3

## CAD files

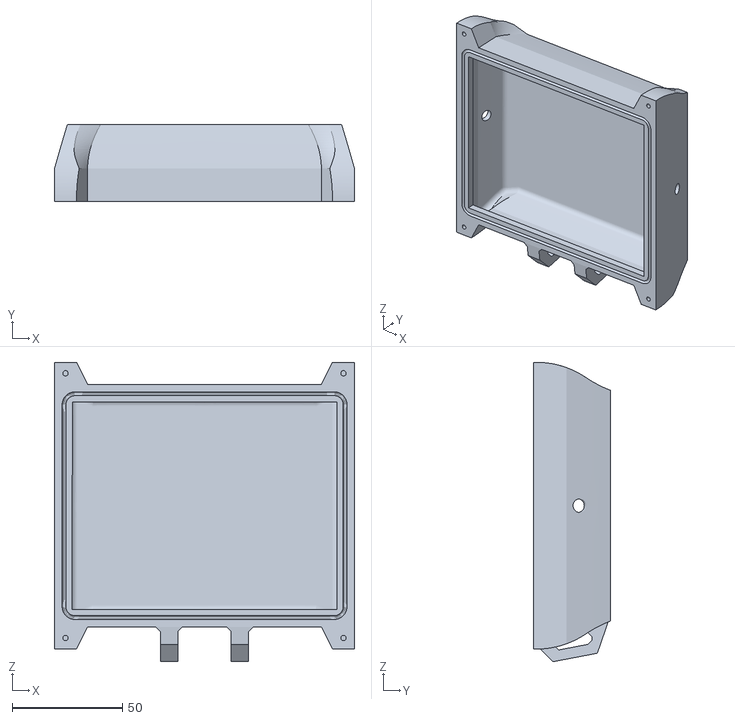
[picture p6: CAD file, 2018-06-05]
enclosure/d.r-a.stl
136.0 x 35.0 x 135.7

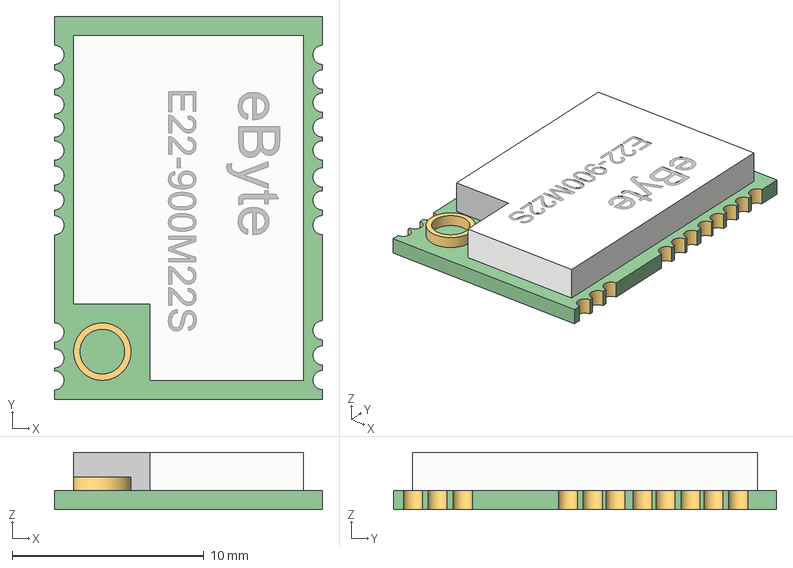
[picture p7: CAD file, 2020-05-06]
hardware/board_esp32_v3/3D/E22-900M22S v2.step
14.0 x 20.0 x 3.00 mm

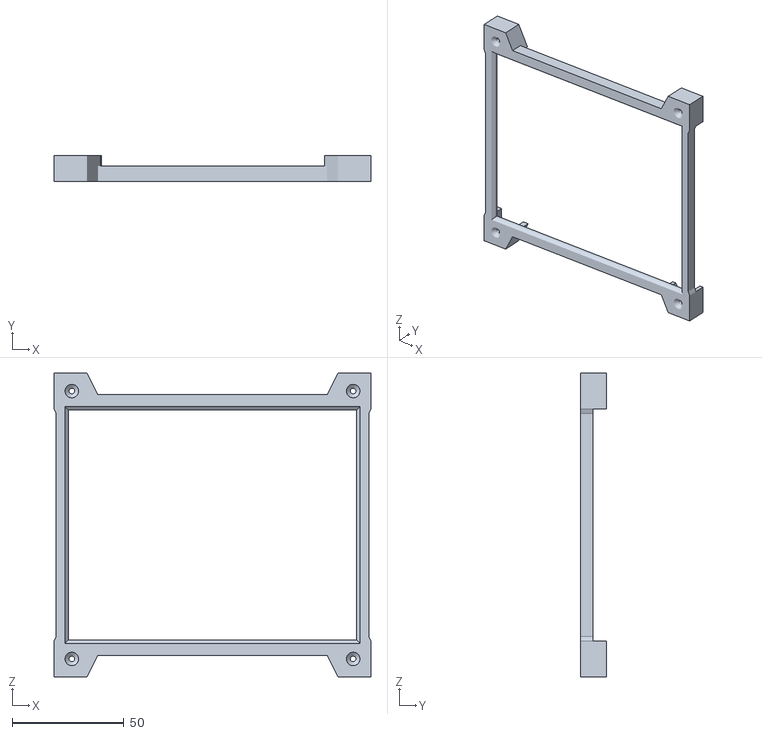
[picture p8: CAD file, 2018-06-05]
enclosure/d.r-b.stl
142.0 x 11.6 x 136.0

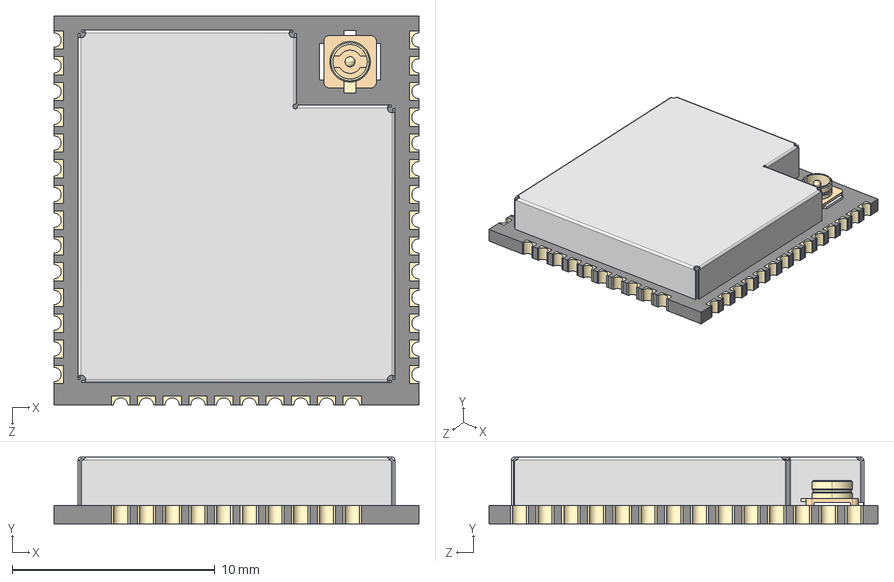
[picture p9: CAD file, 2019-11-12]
hardware/board_esp32_v3/3D/ESP32-WROOM-32U--3DModel-STEP-56544.STEP
18.0 x 3.30 x 19.2 mm

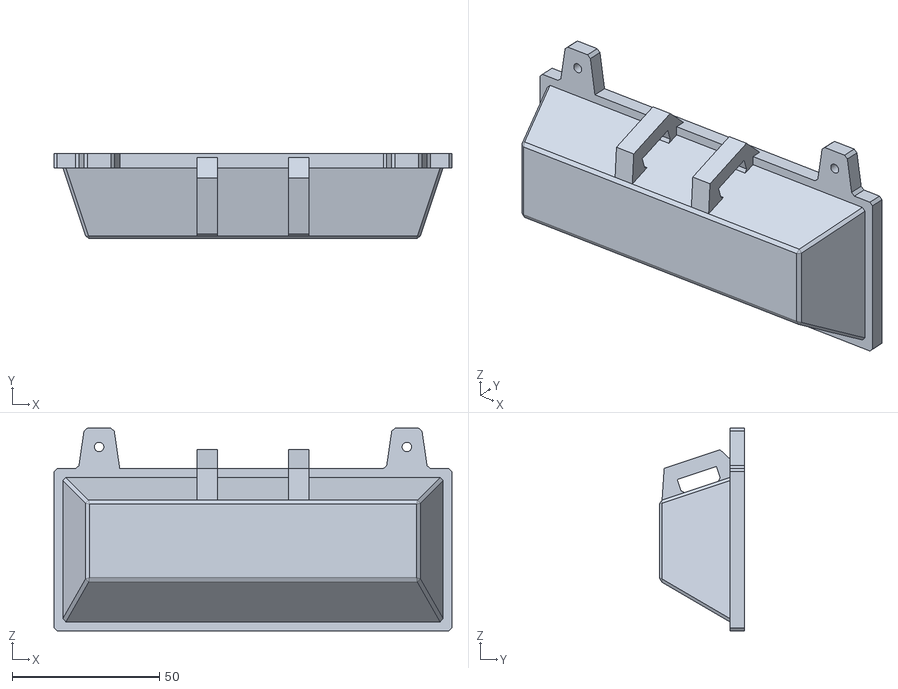
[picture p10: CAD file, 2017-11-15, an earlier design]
enclosure/old/disaster_radio_enclosure.stl
135.0 x 29.0 x 68.7

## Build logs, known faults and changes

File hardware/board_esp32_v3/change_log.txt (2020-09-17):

board_esp32 changelog

191216 - Fitz
 - Move components around layout
 
200505 - Fitz
 - Flipped SD Card
 - Switched LORA2_NSS from IO34 to IO33 (since IO34 input only), battery analog voltage detection is no IO34
 - increased pad length on USB and SD-CARD to make handsoldering easier
 - changed switch to more common part (I have a 1000 of em)
 - fixed E22-900M22S footprint
 - Defaulted E22-900M30S to 3v3 (previously it was connected to both Vbatt and 3v3 shorting both!)
 - removed copper from underneath ESP32 antenna
 - fixed USB+ and USB- data lines, they were reversed going into the FT231XS usb to serial IC
 - changed TPS62162 buck converter footprint to WSON, previous footprint was not in stock anywhere

200819 - Fitz
connect LORAx_DIO2 pin to LORAx_TXEN, and removed LORAx_TXEN connection to MCU
switched D5/D6 from LORAx_DIO1 to LORAx_DIO2
switching LORA1_DIO2 and LORA1_RXEN (IO26 and IO21)
connect LORAx_DIO1 pins instead of LORAx_DIO2 to ESP32 (IO17, IO26)
add non-connected solder bridge between LORAxDIO1s (as a GPIO conservation)
changed ESP32 from WROOM-32D to WROOM-32U (exernal antenna)
hook un-used ESP32 pins (including SENSOR_VP/VN) to test point

200831 - Fitz
Switch LORA2_DIO1 adn LORA1_RXEN (IO17 and IO27)
changed all test points to 1.0MM through holes
added pull down to Q2

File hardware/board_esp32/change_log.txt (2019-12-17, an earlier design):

board_esp32 changelog

191216
Fitz
 - Move components around layout

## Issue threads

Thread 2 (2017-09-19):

Breakout board breakout boards!

Juul, 2017-09-19:
We need a breakout board for our breakout board!

We're using the [Semtech SX1276](http://www.semtech.com/images/datasheet/sx1276_77_78_79.pdf) for LoRa, but using it directly requires a bunch of support components so we're instead using a module like:

* [DORJI DRF1276](http://www.dorji.com/docs/data/DRF1276G.pdf)
* [HopeRF RFM95(W)](http://www.hoperf.com/upload/rf/RFM95_96_97_98W.pdf): The W is only related to FCC/CE certification

They accomplish the same thing, are similarly priced and use the same footprint but the pinouts are unfortunately different. The RFM95 is the most popular module but the DORJI is a bit cheaper.

These modules have no antenna connector so we need to break them out further. Breaking out the antenna pins to an antenna connector requires impedance matching.  Here's [a really nice talk on doing impedance matching the easy way](https://www.youtube.com/watch?v=TnRn3Kn_aXg).

@nanomonkey is working on a breakout board that will include:

* Pads for soldering either RFM95(W) or DRF1276 LoRa module
* SMA edge connector with impedance matched connection to the LoRa module
* Pin header for mounting a ESP8266 WeMos d1 mini module
* 3.3v regulator capable of powering both ESP8266 and LoRa module from the WeMos USB port

We will order a bunch of them from Seeed Fusion as soon as the design is ready.

Juul, 2017-09-19:
[Here's a KiCAD project with an RFM95(W) breakout](https://github.com/FabLab-Luenen/RFM95W-Breakout). It's not exactly what we need (only two-layer, no impedance matching, wrong antenna connector), but we can copy the PCB footprint from this project.

Juul, 2017-10-24:
Fitz and nanomonkey finalized the design and ordered these on October 19th with express shipping.

Juul, 2018-03-21:
Version 2 has been ordered

Closed 2018-03-21.

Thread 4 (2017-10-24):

Test websocket send in LoRa onRecieve

paidforby, 2017-10-24:
Current firmware.ino has not been fully tested with hardware. If we have more prototypes, we need to see if the full LoRa send/receive exchange works with the websocket. The issue is on line 81 of [firmware.ino](https://github.com/sudomesh/disaster-radio/blob/master/firmware/firmware.ino) the `ws.binaryAll(incoming, incomingLength);` with the onRecieve callback may not be working correctly. The documentation for using this websocket server is fantastic, the answer should be in here somewhere, https://github.com/me-no-dev/ESPAsyncWebServer#methods-for-sending-data-to-a-socket-client

paidforby, 2017-11-15:
sendMessage function was written to take a string, but was being given a char array. Fixed in [recent commit](https://github.com/sudomesh/disaster-radio/commit/8690f6076b0b8a0d9fa5ed9566c9e940d3b80017). Still have not adequately tested websocket send triggered by LoRa recieve.  Message is being garbled on breadboarded prototype hardware, will retest with PCB prototype.

paidforby, 2018-01-23:
Other problems found with firmware's handling of messages. Web socket send and receive fulling working, fixed as of ccde3689baa7c08eb8a4e48aeda567ec0fbf8abb. Message garbling appears to be a hardware problem, opened separate issue (#6) to address this.

Closed 2018-01-23.

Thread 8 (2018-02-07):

Rotate WeMos (or move SMA connector)

morganrallen, 2018-02-07:
Presently, mounting inside any sort of enclosure is impractical due to the SMA connector and USB port being pointed in the same direction. This might also warrant a higher level discussion around antenna connectors. Maybe using u.FL is more flexible when considering enclosures?

samuk, 2020-02-13:
Is this resolved by plans for v5? https://github.com/sudomesh/disaster-radio/wiki/Board-v5-Plans

Can this ticket be closed?

morganrallen, 2020-02-13:
It's for the original board, so I'm going to guess it can.

Closed 2020-02-13.

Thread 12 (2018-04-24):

this is all hardware?

and09, 2018-04-24:
If I buy a powerbank and this
https://www.banggood.com/2Pcs-Wemos-TTGO-LORA-SX1278-ESP32-0_96-OLED-Module-16-Mt-Bytes-128-Mt-bit-433Mhz-For-Arduino-p-1270420.html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

This is all waht I need?
Is possible to connect esp to baofeng sound cable?

philippeowagner, 2018-09-04:
I ordered [this one](https://de.aliexpress.com/item/868-mhz-915-mhz-LoRa-ESP32-Oled-Wifi-SX1276-Modul-IOT-mit-Antenne-F-r-Arduino/32836246848.html) a few days ago. It was suggested suggested [on the mailing list](https://sudoroom.org/pipermail/disasterradio/2017-December/000032.html).

Juul, 2018-09-05:
We're porting the software to the ESP32 and the one Philippe linked is the
one I'm using for testing so it should work on it soon. Currently we're
still on the ESP8266 but we want to move to the ESP32 as soon as possible.

On Tue, Sep 4, 2018 at 1:28 PM, Philippe O. Wagner <notifications@github.com
> wrote:

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

philippeowagner, 2018-09-05:
The e-mail was a bit older... Lucky me that the model is still compatible.

samuk, 2019-11-16:
Grant has been making some progress with the code https://github.com/sudomesh/disaster-radio/pull/25#issuecomment-550434519

For these boards https://www.aliexpress.com/item/32915894264.html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,searchweb201602_7,searchweb201603_55

Closed 2020-02-13.

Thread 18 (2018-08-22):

Cannot exchange messages across two clients connected to same node

benhylau, 2018-08-22:
Got a pair of dev boards from dweb, but could not get them to talk to one another on the 192.16.8.1.4 chat. Build firmware and web app from `master` following the instructions here, got web app running again, but still cannot get two laptop clients connected to the chat to exchange messages. Each client sees their own view of the chat.

The software build toolchain is pretty solid though :)

paidforby, 2018-10-12:
Sorry, just noticed this issue. to clients on the same node do not see their eachother's messages because they are not getting pushed to the websocket. There does exist a hack to enable very similar functionality, if you enter `$' in the chat app after logging in, echoing will be toggled (or you can [flip this bit](https://github.com/sudomesh/disaster-radio/blob/master/firmware/firmware.ino#L63) in the firmware and recompile it). Then messages will be echo'd to the websocket, so the client who posts the message will appear to have sent two messages, but other clients on the node will only see the echo. Recent versions of firmware make this and other functionailty more visible by sending debugging output to the websocket, like [this](https://github.com/sudomesh/disaster-radio/blob/master/firmware/firmware.ino#L345), probably should add a line that tells you how to enable echo if it is off.

benhylau, 2018-10-13:
@stigtsp and I got two devices to talk to each other as of a week ago. They were behaving a little unpredictably at times, but they were also running different version of firmware. We will flash latest and try again. Thanks for the tip about echo.

paidforby, 2018-10-13:
Yes, I definitely recommend flashing off of latest, I'm sure there are still some bugs, currently working on a complete revamp of the firmware using our simulator, https://github.com/sudomesh/disaster-radio-simulator.

lewisxhe, 2019-12-03:
I also cannot exchange information between two nodes. I use esp32 as the node, as shown in the figure.
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

lewisxhe, 2019-12-03:
I have understood that I will try to adapt to TTGO Twatch

paidforby, 2019-12-04:
It looks like you are receiving the chat message. The debugging message "I am not the next hop, packet dropped" is a false alarm, the packet sent by the demo chat app is not a routed packet, it is a broadcast packet with a destination address of `FF:FF:FF:FF:FF:FF`. Since this doesn't match the receiving node's address and does not match any entry in it's routing table, from a routing perspective, it rightly drops the packet. As I write more of the routing logic for chat messages, I may change the handling of broadcast packets, but currently that is the way it works.

To debug the sending and receiving of chat messages, open the chat app of the receiving node and see if you are seeing the messages from the sending node. Based on your second comment, I'm guessing you figured that out.

samuk, 2020-02-13:
@lewisxhe did you get anywhere with the TTGO watch? Do you need further help or can this issue be closed?

lewisxhe, 2020-02-14:
I have no problem.@samuk

samuk, 2020-02-14:
OK thanks for letting me know. Did you get anywhere with the watch?

Would be good to add it to this page if you got it working https://github.com/sudomesh/disaster-radio/wiki/Devices--&-Hardware

lewisxhe, 2020-02-15:
Sorry, I did n’t finish this@samuk

Closed 2020-02-14.

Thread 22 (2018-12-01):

2 clients not talking

briangraphted, 2018-12-01:
Hi - Not sure this is the proper venue but here goes.

I have 2 huzzah esp8266's each with their own rfm95 lora running on the 915 frequency. I've been at this for a while (meaning trying to get these to talk) but have hit a dead end. Here's my bench top setup:
- 2 mac laptops, each with a usb/ftdi cord connecting directly to an esp8266 for power
- each esp8266 is connected (per the pin hook up guide) to the rfm95 lora
- each esp8266 is flashed (make flash and make flash_fs) with the firmware and the web app. NOTE: I do *not* have an SD card hooked up, nor a solar panel.
- on each laptop I open a serial terminal
- manually reset (push on board button) each esp8266 and watch the proper message in the serial monitor (example message below).
- on each laptop I connect to the appropriate esp8266 AP (2 laptops, 2 esp8266, 2 wifi access points). The access points read: disaster.radio 18fe34d45dd4 and disaster.radio 18fe34d40f15.
 - on each laptop I open http://disaster.local
 - on each laptop I put in a name (nick) like "node1" then "node2" (on the 2nd laptop)

Observations
The web app loads. The debug messages *say* the lora is initialized but I'm suspicious. I see the bootstrap routes being sent (i.e.: "Sending: 011018fe34d45dd4ffffffffffff2272) - meaning that ap one is broadcasting widely / to no specific address. But I never see a corresponding receive from "node2" either in the serial monitor nor the web app. I've tried to debug sendMessage on the websocket app but to no avail. ... I have this itch at the back of my mind that I'm missing something *super* basic like the proper URL in the browser or something.

Help would be appreciated!
-brian

<snip from serial monitor>
enabling SD card

Waiting for SD card to initialise...SD Card Not Found!
ok
The file exists!
Size=269
<!DOCTYPE html>
<html>
  <head>
    <title>Disaster Radio</title>
    <link rel="stylesheet" href="build/index.css">
  </head>
  <body>
    <h1>Disaster Radio</h1>
    
    <script src="build/bundle.js"></script>
  </body>
</html>

LoRa init succeeded.
local address: 18fe34d45dd4
add 1
aid 1
station: 44:2a:60:f3:45:96 join, AID = 1
transmitting routes

ttl: 1
length: 16
source: 18fe34d45dd4
destination: ffffffffffff
sequence: 00
type: r
data:
Sending: 011018fe34d45dd4ffffffffffff0072
routes transmittedtransmitting routes

paidforby, 2018-12-02:
Hi @briangraphted ! Cool you trying to get the disaster radio firmware working. I can't say I've tried running our firmware on the huzzah boards, how is the esp8266 is connected to the lora transceiver? On our hardware the pinouts are as follows,

NodeMCU/ESP8266 | LoRa Transceiver
----------------|--------
D1/GPIO5/OUT | RESET
D2/GPIO4/INT | DIO0
D5/GPIO14/SCK | SCK
D6/GPIO12/MISO | MISO
D7/GPIO13/MOSI | MOSI
D8/GPIO15/CS | NSS

My guess is that the DIO0 pin of the transceiver is wired to a different pin of the esp8266, this would allow lora to initialize, but prevent the onReceive interrupt from being triggered.

briangraphted, 2018-12-03:
Hi -
Thanks for the fast reply. No luck yet but still poking at it. I'll reply here when I've got it worked out.
thanks.

briangraphted, 2019-02-04:
Sorry for long delay. These pin connections work when hooking up a Wemos D1 Mini (esp8266) and a Adafruit RFM95W LoRa Radio Transceiver Breakout - 868 or 915 MHz

D1 - lora
GND - GND
3v3 - VIN
D8 - CS
D7 - MOSI
D6 - MISO
D5 - SCK
D1 - G0

Closed 2019-02-04.

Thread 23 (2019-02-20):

Help with gerber files & finding suppliers

krisradio, 2019-02-20:
o/ all,
I find this project a couple days ago and really want to put together my own disaster radio. Potentially bring the system to a few mutual aid organizations active in disaster response.

Honestly I'm pretty new to hardware so the gerber files alone are confusing me. If I want to buy some of the v4 boards, should I zip up all the files in hardware/board_v4? Or just the three files in /hardware/board_v4/gerber?

Second question, does anyone know a supplier that can ship all/most of the parts on the build list? Every link is to a different source. I've been trying to find one storefront with everything to save on shipping/complexity, but no luck so far. Would love to hear where y'all got your parts.

Thanks for reading,
Kris with a K

(p.s. sorry if an issue is the wrong way to ask this, but I couldn't find any general/personal contact details)

krisradio, 2019-02-22:
Hi all,
trying to put together a shopping list and I had a couple questions about the power supply.
The build list links to a pair of UltraFire 3.7V 3600mAh batteries (for $4, not sure where you'll ever find them at that price), but it seems to me that AA batteries would be harder to connect to the board than wired battery packs, like these [2500mAh](https://www.adafruit.com/product/328) or [4400 mAh](https://www.adafruit.com/product/354) packs from AdaFruit.
My question is, do either 2500 or 4400 mAh packs work for disaster.radio (with some tinkering presumably)?

Or do I need to get AA batteries, along with some spares & chargers [from amazon](https://www.amazon.com/6000mAh-Battery-Rechargeable-Batteries-Flashlight/dp/B07F29JZMR/)? If so, I need an AA battery enclosure too, right?

For the antenna it looks like [AdaFruit has a compatible option](https://www.adafruit.com/product/3340).

For the WeMos D1, looks like the same supplier linked for the LoRa chip has a [slightly older version](https://www.aliexpress.com/store/product/Mini-D1-Mini-NodeMcu-Lua-WIFI-ESP8266-based-on-the-ESP-12F-module-development-board/1795152_32817642418.html). Pinout looks the exact same so I think/hope that one will work.

For the solar panel, I'll probably just go with the [linked one](https://www.ebay.com/i/121104191012?chn=ps&dispItem=1), but if anyone knows how reliable that supplier is lmk (I can see some damage in these pics).

Also, I still have no idea what to do with these gerber files. For reference I'm an electrical engineering student now, but more of a computer science background. I'm just getting into this world of soldering, power supplies, etc etc. and would really appreciate a helping hand. I'm also an active volunteer in disaster response and really want to bring this project to a few organizations I work with.

In solidarity, Kris with a K

krisradio, 2019-02-23:
Hello again, just ran the numbers on ordering these custom .pcb's through seeed according to the order placed [March 20th, 2018](https://github.com/sudomesh/disaster-radio/tree/master/hardware/orders/order3_march_20th_2018). Unfortunately the cost for the minimum order size might be breaking my bank at $102.24. Honestly that's so far off from the $5 estimate that I'm a little annoyed this is billed as a $40 project.

On another note I was looking at options for the panel/batteries and saw this [adafruit guide](https://learn.adafruit.com/usb-dc-and-solar-lipoly-charger). Although that too would raise the price, the article says their lineup eliminates the need for a buck converter, so that would take one item off the list. Plus, the adafruit solar panels look a little more reliable/beefy than the ones linked in the build guide. Thoughts?

krisradio, 2019-03-22:
Been doing some more research into gerber files and comparing the march 20th order to the v4 files. Gerber is a thick format but I'm pretty sure the march20th order, with absolute drill coordinates plotted over (-6, -3) inches away from the origin, would be wildly off the 33x26mm size of the board.

Meanwhile, the v4 files have two drill layers but only one copper layer. So, both of these files are very confusing to me, and I'm not surprised PCB Way said they couldn't print them. Would love some guidance on this issue.

samuk, 2020-02-13:
Do you still need support with this? Or would one of these dev boards meet your needs?

https://github.com/sudomesh/disaster-radio/wiki/Devices--&-Hardware

samuk, 2020-02-28:
No response to this old issue

Closed 2020-02-28.

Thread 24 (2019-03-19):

Can I help organize a "v4" todo list?

seanomlor, 2019-03-19:
Hi, I just found this project and I'm super interested in setting this up in my community (currently Asheville, NC).

I noticed under [disaster.radio/build](https://disaster.radio/build):
> Our first prototypes had a few bugs and we're currently working on a fixed design.

And via the mailing list from [November 2018](https://sudoroom.org/pipermail/disasterradio/2018-November/000103.html):
> The new board is located in the repo here (https://github.com/sudomesh/disaster-radio/tree/master/hardware/board_v4)

Would it help to have an organized public todo list of all remaining tasks needed to get from wherever things are at now to a goal of, say:
  - New, fully-tested and functional ES32-based "v4" design
  - Updated [GitHub wiki](https://github.com/sudomesh/disaster-radio/wiki)
  - Updated [Learn/Build sections of website](https://github.com/sudomesh/disaster-radio-website)

If so, please let me know if I can help organize and/or maintain something like this.

krisradio, 2019-03-20:
Hey Somlor, good to see some interest in the project, I've been trying to build my own box but haven't gotten any feedback from the devteam so far. Keep us updated on your progress. I hope to have some prototypes within the next three months and I'm happy to help with documentation/todo any way I can.

samuk, 2019-06-18:
I'd love to see this project continue.

It looks like there has been some work done on the Esp32 branch
https://github.com/sudomesh/disaster-radio/tree/esp32

This looks like promising hardware with on-board SD
https://www.aliexpress.com/item/TTGO-LoRa32-V2-1-1-6-version-868-915Mhz-ESP32-LoRa-OLED-0-96-Inch-SD/32872537745.html

I'm waiting for a board, but can't currently get the Esp32 branch to compile.

krisradio, 2019-06-23:
That's an interesting piece of hardware @samuk. Seems like utilizing it over the WeMos dev board and current LoRa chipset would require almost completely refactoring the hardware at least, potentially software too. But it looks like a pretty nimble piece of hardware, if it could replace both those and reduce the construction time/cost, it could be worth it.

I'm still really intrigued by this project as well. Right now I am still confused by the lora_nodemcu.drl file in the [march 20th order](https://github.com/sudomesh/disaster-radio/tree/master/hardware/orders/order3_march_20th_2018). The drill holes are not aligned to the pins, the board, anything.

I am switching gears towards trying my hand at running [althea firmware](https://github.com/althea-net/althea-firmware) on commodity routers. If I can get a little experience with that I might be able to install althea on disaster radio by the time of the next release. Then I could spin up a mesh net with fully decentralized, p2p, real-world incentives. A lofty goal but I'm not the only one dreaming of it.

samuk, 2019-06-23:
I'm very interested in getting the software adapted for this off the shelf hardware. I think if people can just order a $17 device off Aliexpress it's going to appeal to a greater number of people.

 I lack the skills to do it personally, but I can try and get other people excited about the idea.

krisradio, 2019-06-26:
Yeah it has the LoRa, battery, and storage, but does it have a processor architecture/speed compatible with disaster.radio or another mesh networking protocol? That's the question I can't find an answer to on the store listing.

paidforby, 2019-11-05:
FYI https://github.com/sudomesh/disaster-radio/pull/25
I'm revisiting parts of this project. I can't speak much to the hardware development. I am mostly interested in getting firmware and routing protocol working on the ESP32 TTGO board suggested by @samuk so that other people can possibly work on hardware prototypes and real-world deployments.

I will create check list on the [Github wiki homepage](https://github.com/sudomesh/disaster-radio/wiki) so y'all can keep track of my progress, or others can add their goals/progress.

Closed 2020-02-13.

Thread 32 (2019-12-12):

Compilation issues

matthewrwright, 2019-12-12:
Not sure whether to raise this as a disaster-radio issue or a LoRaLayer2 issue - apologies if I've pushed it in the wrong place.

On make:

`In file included from ./firmware/esp32_ttgo/console.cpp:2:0:
./libs/LoRaLayer2/src/LoRaLayer2.h: In member function 'void consoleClass::lr(char (*)[8])':
./libs/LoRaLayer2/src/LoRaLayer2.h:74:10: error: 'void LL2Class::printRoutingTable()' is private
     void printRoutingTable();
          ^
./firmware/esp32_ttgo/console.cpp:21:31: error: within this context
         LL2.printRoutingTable();
                               ^
make: *** [Makefile:262: /tmp/mkESP/main_ttgo-lora32-v1/console.cpp.o] Error 1
`

Resolved by moving the definition in libs/LoRaLayer2/src/LoRaLayer2.h from private to public.

paidforby, 2019-12-24:
Good catch! This really an issue with [LoRaLayer2](https://github.com/sudomesh/LoRaLayer2), this is an OK place to inquire about it though. Looks like I made some local changes that library that I never pushed to the repo. I pushed those changes [here](https://github.com/sudomesh/LoRaLayer2/commit/5b59547f400cdeccef7acacc9833f2f4502b8d46) and updated `fetch_deps` to checkout the latest. Make sure you always pull the latest LoRaLayer2, since I'm actively making changes to that repo. Likewise, I'll make sure to always push any necessary updates to the libraries being used.

Closed 2019-12-24.

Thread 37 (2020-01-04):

Support for legacy esp8266 WeMos dev boards

dwhall, 2020-01-04:
firmware/esp8266_wemos/routing.cpp:631
packet_received() returns a pointer to a local variable.

dwhall, 2020-01-04:
Sorry for the noise.

paidforby, 2020-01-05:
No noise. This actually brings up an important issue. The esp8266 code needs to be synced with the latest developments. I haven't touched that code in almost a year and have switched to developing on the esp32. We should either get that esp8266 code actually working, or we should stop claiming to support it. Thanks for bringing this up. I'm going to rename and reopen this issue.

samuk, 2020-05-13:
@paidforby Is this still on your to-do? Does it make sense to spend energy on it? Suggest just dropping support for esp8266 unless there's a compelling reason?

paidforby, 2020-05-13:
It does not. Pretty much everyone has appeared to move on to the ESP32. I'm considering ways to restructure the firmware folder in a more sensible way. When I do that, I'll remove the stale ESP8266 folder to avoid confusion.

Closed 2020-05-13.

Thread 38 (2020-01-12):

Routing table error after long uptime or 3+ nodes

2E0PGS, 2020-01-12:
Great firmware, I just successfully range tested two modules with impressive results on the 868MHz band.

A few improvement ideas

* Can we get some kind of status page. I wasn't sure if the other node was connected or in range. The only was I knew was getting a friend to ping me messages back and forth on the web chat while I walked around outside.
* Can we drive OLED display that's present on most premade compatible boards from China. Even if it's some simple status and IP address to show it's working.

Cheers

samuk, 2020-01-12:
Yes both good ideas, the status has been discussed below

https://github.com/sudomesh/disaster-radio/issues/35

Writing scrolling last-sent messages to the OLED has been mentioned on the mailing list.

paidforby, 2020-01-14:
@samuk is correct, both of these issues have been on my mind.

For what it is worth, the latest firmware (which I will release as 0.1.1 soon) includes a console interface accessed through serial that allows you to print the routing table by typing `lr -r`, see the [testing firmware section](https://github.com/sudomesh/disaster-radio/#testing-firmware) of the readme, to see the current abilities of the console interface. The routing table will show "connected" nodes along with the "quality" of the connection in the form the metric.

I'm planning on figuring out a way to display the routing table in the web app.

paidforby, 2020-01-16:
@2E0PGS checkout new "Active Nodes" list feature mentioned in the related issue, https://github.com/sudomesh/disaster-radio/issues/35#issuecomment-574992472

Should be working if you build (both the firmware and the web app) from latest, or I will be compiling a pre-built binary for 0.1.1 soon.

No progress on utilizing the OLED screen yet.

2E0PGS, 2020-01-19:
ok cool thanks!

2E0PGS, 2020-01-25:
Sorry it took me a while to try v0.1.1 just flashed it on my two boards. Working great!
I can now see the hops and metric.

I presume node `000000000000` is the local node's address? hops 00 and metric 00

2E0PGS, 2020-01-26:
It looks like there maybe a bug with the beacon length when the device is left on for a long time.

## 2020-01-25 17:20:31
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

## 2020-01-26 00:46:40
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

I didn't change any settings in GQRX.

The only changes I can think of maybe room temperature, laptop warming up, LoRa warming up, and HackRF warming up.

Version 0.1.1 from the binary release.

I had two nodes running there. Oddly enough unplugging and replugging didn't reset it.

However back this morning with a cold room and cold devices (switch off over night) they're back to how it was in the first screenshot.

2E0PGS, 2020-01-26:
I will try and replicate it by artificially heating up my board. Or leaving one on and one off and compare after hours.

2E0PGS, 2020-01-26:
No sudden changes from artificially heating my SDR or my LoRa board. I am using TTGO.

I will try leaving one running for now. Then I can turn the other on later and compare.

2E0PGS, 2020-01-26:
The only code references I see are these two: https://github.com/search?q=org%3Asudomesh+beaconInterval&type=Code

2E0PGS, 2020-01-26:
Or the glitch relates to the route message getting longer. Android phone on the WiFi slowing it down?

2E0PGS, 2020-01-26:
# I did some testing today. Here are the results.

During all of this testing GQRX was not modified settings wise. I am running two v0.1.1 firmware on TTGO boards from prebuilt binaries.

Ignore the extra harmonics this is due to one board being powered via a grounded mains to 5v PSU and the second via battery power bank. The second lagging signal is the power bank TTGO we shall call this node 2.

## 2020-01-26 17:28:28 "Receiver Options"
This is the beginning of the test and I show a few setting windows.
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

## 2020-01-26 17:28:38 "FFT Settings"
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

## 2020-01-26 17:28:42 "Input controls"
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

## 2020-01-26 22:03:16
Several hours into testing I notice a increase in the signal TX length.
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

## 2020-01-26 22:33:48
I take power cycle one of the boards to see if this changes it's TX length. It makes no change.
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

## 2020-01-26 22:35:50
I decide to try power cycle both boards to see if the issue is related to packets exchanged between the two, maybe routing information. This resolves the problem.
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

2E0PGS, 2020-01-27:
Running one node on it's own for hours with no neighbours didn't have this behavior. This makes me think it's route message related.

samuk, 2020-01-27:
Interesting stuff, wonder if it's worth testing with the latest code? Realise not that much has changed, but might be worth verifying it's still an issue?

paidforby, 2020-01-28:
Highly likely that there may be an unknown error with the routing message logic that only appears after a long uptime. My guess is that a byte gets shifted somewhere and starts filling the routing table with false routes. This would explain why it doesn't go away after only one node is restarted, because the node that was kept on immediately shares those false routes with the rebooted node. However, when both are rebooted, their routing tables are reset and their little network "forgets" about the false routes.

Note: this is just my theory, I would need to do some actual testing and write some debugging code to demonstrate that this is happening.

tlrobinson, 2020-01-28:
I don’t know if this is related, but I was seeing an issue where the
routing table exploded (dozens of new entries per minute) if I had 3+ nodes
running. I’ll try to reproduce it.

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

2E0PGS, 2020-02-13:
Ref the hypothesis, this sounds about right to me. I suspect it's filling up and this causes a knock on effect of a longer TX length as the message is longer.

samuk, 2020-05-13:
Would you be up for trying to replicate your error with the latest routing? Hoping this bug has just gone away: https://github.com/sudomesh/disaster-radio/issues/57#issuecomment-628040381

paidforby, 2020-05-14:
Yes, it would be good to test if this bug is resolved on the [1.0.0-rc.2](https://github.com/sudomesh/disaster-radio/tree/1.0.0-rc.2 ) branch, which is using the latest updates to LoRaLayer2, which has switched to a more dynamic source routing (DSR) style and no longer requires that sharing of routing tables via routing table packets.

paidforby, 2020-09-21:
Closing this issue and merging it with #81 since there is more activity on that thread and these seem closely (if not directly) related issues.

Closed 2020-09-21.

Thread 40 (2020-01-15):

heltec_wifi_lora_32_V2 support

matthewrwright, 2020-01-15:
Hi - trying to compile for the heltec_wifi_lora_32_V2 board using platformio - compilation succeeds but I'm getting a lot of warnings about pins being overridden in code.

```

In file included from .pio/libdeps/heltec_wifi_lora_32_V2/LoRaLayer2/src/Layer1_LoRa.cpp:2:0:
.pio/libdeps/heltec_wifi_lora_32_V2/LoRaLayer2/src/Layer1.h:25:0: warning: "LORA_DEFAULT_RESET_PIN" redefined
 #define LORA_DEFAULT_RESET_PIN     23
 ^
In file included from .pio/libdeps/heltec_wifi_lora_32_V2/LoRaLayer2/src/Layer1_LoRa.cpp:1:0:
.pio/libdeps/heltec_wifi_lora_32_V2/LoRa_ID1167/src/LoRa.h:20:0: note: this is the location of the previous definition
 #define LORA_DEFAULT_RESET_PIN     9
 ^

```
Unsure if this is the source of my problem, but I get a warning that my LoRa radio isn't connected when I launch the serial console.

```
v0.1.0
WARNING: LoRa tranceiver not found!
Local address of your node is a4cf1202ad5c

Sending: 0110a4cf1202ad5cffffffffffff0172
```

Any clues gratefully accepted!

paidforby, 2020-01-15:
Interesting. It looks like there is an unintentional conflict between a constants in the LoRaLayer2 and LoRa libraries. I haven't seen this issue when compiling with makeEspArduino for the LILY TTGO dev board. I'll change the names of the constants so there is no conflict.

However, I'm not sure that is your issue. I haven't been developing with the Heltec dev board, so I'm not sure what pins it has connected to its LoRa transceiver. Maybe there are examples or documentation the would provide hints. Once you figure out what pins it uses, you can manually set the pins by adding the following line in the `setup()` function of `main.ino` before calling `Layer1.init()`,
```
Layer1.setPins(int cs, int reset, int dio);
```
Good luck! Let me know what pins work for that board so we can document it somewhere.

paidforby, 2020-01-15:
Didn't mean to close issue. But I did update LoRaLayer2 with a partial fix. I renamed the pin constants, so there should no longer be a conflict if you pull the latest commit of LL2. I'll update platformio config to pull the latest.

matthewrwright, 2020-01-15:
Thanks! Pulled the latest commit and set the pins as-per the pinout diagram but no joy

https://github.com/Heltec-Aaron-Lee/WiFi_Kit_series/blob/master/PinoutDiagram/WIFI_LoRa_32_V2.pdf

I'll keep plugging away and see if I can get it running.

paidforby, 2020-01-16:
Hmmm, I know there's some unreliable documentation out there for ESP32 pinouts. Maybe that diagram doesn't show the correct pinout? Or it could be disguising something, like maybe the OLED chip select needs to be pulled low? Wish I could be of more help.

I did find that Heltec has a whole repository of [source code and example code](https://github.com/HelTecAutomation/Heltec_ESP32). It actually looks like they have their own port of sandeep's arduino-LoRa,

https://github.com/HelTecAutomation/Heltec_ESP32/blob/master/src/lora/LoRa.h#L7

It's not clear what the difference is outside of a simplified header file. Perhaps there are some clues in that directory that will solve your problem. At the very least, you could try flashing some of their [LoRa code examples](https://github.com/HelTecAutomation/Heltec_ESP32/tree/master/examples/LoRa) to confirm that your board is working.

matthewrwright, 2020-01-19:
Thanks for the pointer - their sample OLED_LoRa_Sender works when compiled with Arduino, so now to find the differences!

matthewrwright, 2020-01-20:
I'm at a bit of a loss as to what's happening - I've even tried changing the code to use the Heltec version of the library. I haven't checked the code for pin reuse - I'm wondering if the calls to initialise the SDCard which this board doesn't have are setting a pin. Will look into it more over the next couple of days.
I know you have a lot to look into, so appreciate your time on this.

matthewrwright, 2020-01-24:
Happy to report that the code from PR #44 works with additions to platformio.ini

```
[env:heltec]
platform = espressif32
board = heltec_wifi_lora_32_V2
framework = arduino
upload_port = /dev/ttyUSB0
monitor_port = /dev/ttyUSB0
monitor_speed = 115200
build_flags =
        -DHELTEC

```
and config.h

```
#ifdef HELTEC
#define LORA_IRQ DIO0
#define LORA_IO1 DIO1
#define LORA_IO2 DIO2
#define LORA_SCK SCK
#define LORA_MISO MISO
#define LORA_MOSI MOSI
#define LORA_RST RST_LoRa
#define LORA_CS SS
#define OLED_SDA SDA_OLED
#define OLED_SCL SCL_OLED
#define OLED_RST RST_OLED
#define OLED_WIDTH 128
#define OLED_HEIGHT 64
#endif
```

As it looks like #44 is going to be merged can we add a definition for Heltec boards to config.h afterwards? Happy to make a PR for changes afterwards or for you to make the changes after the refactor.

paidforby, 2020-01-24:
Very nice. That is great to hear. I can just add the lines you provided after merging the refactor, if that is OK with you. I have a few other boards to test, so I'd like to think about the best way to include all of them.

matthewrwright, 2020-01-24:
Perfect - thanks! Those pin definitions came from the paxcounter repo mentioned in the thread of #44 so certainly worth a look there for experimental support for various boards which can be confirmed as/when people test them.

matthewrwright, 2020-01-29:
Now #44 is merged, it looks like my changes to platformio.ini and config.h both work fine for the heltec. Now to get some range testing in!

paidforby, 2020-01-30:
Added your suggestions in this commit https://github.com/sudomesh/disaster-radio/commit/be1d6ff6c41a050ff14465e169ac644bb99e8a32 you'll have to confirm that I copied everything correctly and that it still works for you. (p.s. I also changed the name of the firmware directory to be more general since we now support more that just TTGO boards!)

Closed 2020-01-30.

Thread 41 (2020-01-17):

Clock speed/ Sleep Mode

samuk, 2020-01-17:
I'm looking to put up some 'infrastructure' nodes in high places. These nodes will be solar and so power is important.

On the TTGO boards I measure around 160mW to peaks of 250mW.

It seems that these 'infrastructure' nodes do not need all the functionality of the webserver and Wifi.

So we could create a branch that;

* Does not use Wifi
* Does not include a webserver
* Runs at a [lower clock speed](https://github.com/espressif/arduino-esp32/blob/master/cores/esp32/esp32-hal-cpu.h#L38)?

Juul, 2020-01-17:
Do the TTGO boards connect the receive interrupt pin from the LoRa module? If so, you could get even lower by putting the ESP32 into a sleep mode and only waking up when a packet is received.

I've been working on getting very low power on an Atmega chip recently and would be interested in playing around with this.

You might also want to run the ESP32 at lower voltage, though I'm not sure it can go that low.

matthewrwright, 2020-01-17:
Interesting idea - I live in a valley almost, so it would certainly be worthwhile to mount a couple up high on the hills to extend coverage. Having something with a reasonable battery life would cut the need for a large solar panel and could report it's voltage to the mesh when it got low and someone could change the battery out.

samuk, 2020-01-24:
Edited the title as Wifi/ Bluetooth being discussed on this ticket herehttps://github.com/sudomesh/disaster-radio/issues/45

samuk, 2020-02-08:
I had a play with the clock speed, reducing to 80Mhz seems to have no adverse effects. I tested in BT mode. This reduces the power consumption to ~70mA, with peaks of ~120mA on broadcast.

I just added
```
setCpuFrequencyMhz(80); //Set CPU clock to 80MHz fo example
getCpuFrequencyMhz(); //Get CPU clock
```
To line 424 of main.ino

samuk, 2020-02-12:
https://github.com/sudomesh/disaster-radio/pull/54#pullrequestreview-356251424

Closed 2020-02-12.

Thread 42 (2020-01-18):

Support FCC/ CE marked board

samuk, 2020-01-18:
I'm looking to get a few nodes placed on buildings. It may be helpful if the boards proposed have CE markings in Europe.

This board is based on ESP32 and has an SX1276 so getting it working may not be too difficult?

https://pycom.io/product/lopy4/

It also appears to have a LoRa interrupt on [Pin23 ](https://docs.pycom.io/gitbook/assets/specsheets/Pycom_002_Specsheets_LoPy_v2.pdf) So the Powersaving referenced [here ](https://github.com/sudomesh/disaster-radio/issues/41#issuecomment-575591440)may be possible

paidforby, 2020-01-18:
Nice find. It's a little expensive, especially when you add all the additional pieces. Looks like a nice board. I ordered one. I will try to get it working once it arrives.

samuk, 2020-01-18:
Great! I spotted the Paxcounter project supports a bunch of boards. Not sure if the pin definitions are useful: https://github.com/cyberman54/ESP32-Paxcounter/tree/master/src/hal

Could these files just be copied over to support the same range of boards?

paidforby, 2020-01-19:
Hmmm, that's cool, they have some sort of HAL (hardware abstraction layer) design. I don't think it would be as simple as copying and pasting these header files, because it's not clear to me how the pin definitions are being used and I do not think they are using the arduino-LoRa library, which has some built-in HAL that might conflict with their code. It does look it will be helpful while investigating other boards. Thanks!

samuk, 2020-01-19:
I thought it might not be as simple as that..

Did you get the GPS addon shield? https://pycom.io/product/pytrack/

samuk, 2020-01-21:
These look interesting too: https://pycom.io/product/pygo1/

I mentioned Disaster radio on the Pycom forum and their [developer seemed interested](https://forum.pycom.io/topic/5605/would-this-mesh-network-run-on-lopy/3)

paidforby, 2020-03-07:
So I have successfully flashed our firmware to a LoPy4. It took a little bit of doing because the LoPy4 does not have an on-board circuit that switches it in to bootloader mode. I found some useful instructions on how to program it [here](https://www.thethingsnetwork.org/labs/story/program-your-lopy-from-the-arduino-ide-using-lmic). Since I didn't have the expansion board and the Pysense board doesn't provide breakouts for the pins, I ended programing it with a a USB-to-UART adapter, I'd recommend following the USB UART Adapter wiring guide shown on [this page](https://docs.pycom.io/gettingstarted/connection/lopy4/).

I still need to figure out the proper pinout for the LoRa transceiver. It should work by default because the pins are defined in the arduino-esp32 library [here](https://github.com/espressif/arduino-esp32/blob/master/variants/lopy4/pins_arduino.h), but it doesn't seem to be working. I'll post to this issue once I sort out pin definitions.

samuk, 2020-05-13:
@paidforby Any progress on this one?

paidforby, 2020-05-13:
Negative, the LoPy4 has been sitting in my closet for months. I think I've been discouraged because of the complicated flashing process, idk why they didn't just put a flashing circuit on their board like everyone else. I'll take another crack at it before June 1.

paidforby, 2020-05-14:
I'm having some trouble getting this working even with a very simple example. I opened an issue here https://github.com/sandeepmistry/arduino-LoRa/issues/364. Maybe someone else has had success, or maybe there's a reason it won't work.

samuk, 2020-05-14:
Annoying. I'll cross post into the Pycom forum if that's OK.. I'll need CE certified hardware for my installs which is why I'm keen on it..

paidforby, 2020-05-14:
I got it working! They were able to solve my issue. I just need to add `SPI.begin(LORA_SCK, LORA_MISO, LORA_MOSI, LORA_CS);` before calling `LoRa.begin()`. I've got it working with our firmware as well, just need to do a little testing.

Weird that we haven't come across this problem before with other boards, but I guess, they default SPI settings for the LoPy4 are not set to the LORA SPI pins?

I'll push a commint to resolve this issue soon.

paidforby, 2020-05-14:
Interestingly, I had to make `SPI.begin` only be called on LoPy4 as it appears to break the transmitting of packets on the TTGO.

Anyway, the LoPy4 (an FCC and CE marked board) will be supported as of version 1.0.0-rc.2. If you come across other FCC/CE boards that you would like supported, open a new issue.

samuk, 2020-05-14:
Great news :) Thanks..

samuk, 2020-05-14:
If you have a multimeter and spare USB cable lying around I'd be interested in the real-world power consumption of this board running Disaster Radio in Bluetooth mode..

paidforby, 2020-05-15:
Can do. I'll take a look at the power consumption when I get a chance, might not happen for a week or two.

h-c-c, 2021-11-19:
Great work folks.  Did you ever use the LoPy4 with the Pycom expansion board?  I can't seem to get the SD card to mount.

samuk, 2021-11-22:
Afraid I haven't. It may be worth digging in https://github.com/cyberman54/ESP32-Paxcounter code, I think Disaster Radio reused their HAL layer & they support the SD.

Closed 2020-05-14.

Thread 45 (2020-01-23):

Support for Bluetooth LE

samuk, 2020-01-23:
It would be interesting to me to have an Android app that could communicate with Disaster Radio nodes using Bluetooth LE and could:

* Send and receive messages using an interface similar to the current chat interface
* Switch Wifi on and off via Bluetooth

This App.apk could be distributed locally from the SD card over the Wifi

In the future when the OLED works to read messages, it might be interesting to use a [mini bluetooth keyboard](https://shop.pimoroni.com/products/mini-bluetooth-keyboard-black) to enter messages [directly to the device](https://gist.github.com/sabas1080/93115fb66e09c9b40e5857a19f3e7787) with no phone involved. I don't know if this is feasible, or should influence design decisions now, but I thought I'd mention it.

Presumably, you could only have one Bluetooth 'mode' working at any one time?

beegee-tokyo, 2020-01-24:
I just had a look into the current active branch and into the pull request https://github.com/sudomesh/disaster-radio/pull/44

In the current active branch it will be difficult to add the BLE functionality as everything is somehow mixed into the main code. But with the pull request #44 it should be straight forward to write a BleClient module and use it instead of the Telnet/Websocket client.

Regarding BLE and WiFi active at the same time, that will most likely not work. I got both working (with some additional functionality) only on a ESP32 Wrover module with additional 4MB PSRAM. A ESP32 Wroom modules do not have enough RAM to run both + the main application.

Therefor dynamically switching between BLE and WiFi will be not an easy task.

For the start I would make the selection of BLE or WiFi static (compiler option ???) to be able to implement a BLE client module and test it.

Once it works the next step would be to select the client with a **```setupClient(uint8_t clientType)```** function. The clientType could be stored in a configuration file (or ESP32 Preferences).

Basically replace
```cpp
  setupWiFi();
  setupMDNS();
  setupSD();
  setupSPIFFS();
  setupHTTPSever();

  setupTelnet();
  setupWebSocket();
```

With a function like
```cpp
#define WiFiClient 0
#define BleClient 1

  Preferences preferences;
  preferences.begin("Settings", false);
  uint8_t clientType = preferences.getShort("c_type", 0); // defaults to WiFi if preference is not set

  setupClient(clientType);
```
And then initialize the requested client within setupClient().

samuk, 2020-01-24:
>For the start I would make the selection of BLE or WiFi static (compiler option ???)

Thanks for your thoughts and input on this, it seems like a sensible approach.

If I understand correctly, It could be possible to switch the Wifi off/ BlueTooth on from within the Wifi/web interface. And to witch the Bluetooth off/ wifi on from the Android/BlueTooth interface. Either action would trigger a reboot?

I can see that some kind of credential/ password system would be nice for changing the mode, otherwise, my carefully calibrated Bluetooth solar node could be turned to Wifi by a third party and battery run down.

beegee-tokyo, 2020-02-04:
@samuk @paidforby

Good news.
I have setup 2 LoRa nodes. One is a Sparkfun 1ch gateway with a RFM95 module using the BLE client and the second one is a custom ESP32 Wrover board with an Semtech SX1262 transceiver using the WebSocket client.
BLE client is implemented and working. I am using BLE UART at the moment, so I can test easily from an Android BLE Terminal program.

I am seeing all messages sent from one node to the other node on the BLE terminal and I can send messages to the other node as well with e.g. **`00c|Hello from BLE`**.

Before I dig into the Android application, a few questions:
**1)** (Most important) Is there a better specification for the data packages than [Websocket](https://github.com/sudomesh/disaster-radio#websocket)? I cannot find a clear explanation of how the packages (beside of the chat and map messages) are looking like? I see binary data arriving, which I guess is the mesh information, but I have no idea about the format. To show Mesh information in the Android app and maybe users that have joined, I need to know the exact format of all packages.
**2)** On the web application running on the ESP32, I can see messages, join the network and send messages, but the **`Active Nodes | Hops | Metric`** is never updated. Is that the current status or am I doing something wrong?
**3)** On the Android app I will as a first step implement something similar to the web application. Just a list box with the messages, an input box for sending messages and a list of **`Active Nodes | Hops | Metric`**. Would that be a good start? When sending messages, it seems the messages go to all connected nodes right now. How is a specific recipient selected?

rhodey, 2020-02-04:
hi all, I have been watching this project from afar for awhile now and I am not sure that bluetooth is the correct frequency to use for a "disaster". also if this is only a radio for disaster it wouldn't make sense to try and use it for other things. when disaster comes the first people on the scene are "first responders" but I like to think of them as lifeguards sometimes.

the Earth is different all over, I don't believe one single frequency will ever cover the entire planet, and I worry that it is a bad idea to attempt this.

I have a handful of ideas about which frequencies would be best for lifeguard.fm and additionally which protocols & modulation scheme but I believe the topic requires further study. I'd be happy to compare notes some time :)

rhodey, 2020-02-04:
think about the sharks in the ocean, they use the electromagnetic spectrum, if you muddy up their senses you might get bit!

beegee-tokyo, 2020-02-04:
@rhodey
You are misunderstanding what this issue is about.

This is not an approach to replace the LoRa for the communication between nodes.

It is an approach to have an alternative to the WiFi connection between the LoRa node and the phone (where you type your messages) by using a BLE connection. BLE is using way less energy, so the batteries of the phone and the LoRa node can last longer.

rhodey, 2020-02-04:
I don’t claim to know any of the knitty gritty details, but I do see that you’re trying to make use of the electromagnetic spectrum & y’all seem to be moving too fast to be honest.

the animals did not split up the audio spectrum in one day or one year, slowly over time everyone found a place for themselves.

Humans have no idea where they belong in the electromagnetic spectrum because often we think we got here first. false.

I have thought carefully about this for a number of years and I still do not have all the answers, but they continue to reveal themselves in time.

take care,
— rhodey

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

paidforby, 2020-02-05:
@beegee-tokyo sounds like you are making good progress! To address your questions,
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
samuk, 2020-02-10:
Great stuff! Exciting to hear about progress with a map.

A further feature request would be to add some (optional) notification sounds, so If I lose BT connection I get a beep, if someone @mentions my nick I get a beep. No idea how hard that is to do?

beegee-tokyo, 2020-02-11:
Sounds are no big problem I think. It's just some effort to make them user-configurable, but for a start I can stick to the default notification sound of the Android system (which is different on each phone/manufacturer).

beegee-tokyo, 2020-02-11:
Done.

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

The coordinates are sent every 1 minute if the node is connected to the Android phone via BLE.
The WiFi node you see in the picture is a fake location.
Switching between chat window and map window is done by a button. While viewing the map, the chat window is still updated with incoming messages.
For the moment there is an additional button to share the location, but that might not be necessary in the future.

Sounds are done as well. If someone sends a message with @<YOUR_NICK_NAME>, a notification sound will be played.
If the BLE connection to the node is broken, an alarm sound is played.
The sounds used are the default notification and alarm sounds setup on your phone.

Need to do some clean-up and then I will update the repo and release a new version on Google Play.

beegee-tokyo, 2020-02-11:
Oh, and there are more thing I need to add.
I am using [MapBox](mapbox.com), same as the [disaster-radio-map](https://github.com/sudomesh/disaster-radio-map) web app I think..
Mapbox is free for a limited number of map updates per day only, after that they charge me. So I cannot just spread my access token with the app. The user needs to get his own access token and enter it in the app.
On top of that, I need to add the option to download maps to be able to use the map without internet connection.

samuk, 2020-02-11:
Might be interesting to use this map base layer at some point. https://wiki.openstreetmap.org/wiki/Humanitarian_map_style

beegee-tokyo, 2020-02-11:
Good idea, I forgot about OpenStreetMap.

Will check tomorrow.

beegee-tokyo, 2020-02-15:
Rolled out new version with map functionality and sound notification.

The sound notification uses the default notification sound of the phone for messages that start with **`@>>myName<<`** where **`>>myName<<`** is the name you joined the channel with.
If the BLE connection to the LoRa node is lost the default alarm sound of the phone is played.
**`TODO`** add settings to make the sounds user configurable.

The map functionality works only with nodes that use the BLE client at the moment as the GPSClient is not implemented yet. As the location message format is not finally defined yet I assumed it is as
**`04m|<user>{"pos":[48.75608,2.302038]}`**

The maps view is based on [OpenStreetMap osmdroid API](https://github.com/osmdroid/osmdroid). By default the app will load the required maps online based on usage. To use an offline map, you have to create a map that is compatible with OSM. You can use e.g. [Mobile Atlas Creator (MOBAC)](https://mobac.sourceforge.io/) and create a map covering the region you need. At the moment only one map is supported. Read the [osmdroid Wiki](https://github.com/osmdroid/osmdroid/wiki/Offline-Map-Tiles) which map formats are supported, how to create a map and where to store it on your phone. The Wiki says to put the maps into **`/sdcard/osmdroid/`**. If you have a phone without SD card just put it into **`/osmdroid`** into the phone folder you see when opening the phone on your PC. On my Samsung Galaxy J2 Core the Windows path looks like
**`Computer\SM-J260Y\Phone\osmdroid.`**
On my Huawei M5 tablet the path looks like
**`Computer\ThisIsMine\Internal storage\osmdroid.`**
A sample map for Philippines, Metro Manila, Sucat road can be found in the maps folder. As DisasterRadio is designed to communicate in cases where none of the usual communication means are available, it is recommended that you create a map of your region in advance and save it on your phone.

samuk, 2020-02-15:
Nice, love the new map stuff, very cool.

Using the latest from Play store I did get an error when first trying to connect to the node which crashed the app. It was resolved once I installed the OSMdroid app and saved a map to the /storage/emulated path.

beegee-tokyo, 2020-02-15:
@samuk, good finding. I need to check this. The app should not depend on OSMdroid installed.

samuk, 2020-02-22:
@beegee-tokyo The latest version works for me. Thanks for your work on this, I'll close this ticket now as it's been merged into master.

The switching function between BT/ Wifi would be nice to have at some point, but I think this feature request is complete.

Closed 2020-02-22.

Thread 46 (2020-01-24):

Make the Pins to Connect to LoRa Variables

candrist, 2020-01-24:
In order to support multiple boards and versions, can we make the pins assigned to the LoRa variables that we can assign?

I am looking at ESP32 Boards.

paidforby, 2020-01-25:
Yes, this has been supported since this pull request to LoRaLayer2, https://github.com/sudomesh/LoRaLayer2/pull/1

Just call, `Layer1.setPins(int cs, int reset, int dio);` before `Layer1.initi();`.

We are currently working on expanding support for a number of boards by adapting Paxcounter's HAL (Hardware Abstraction Layer), https://github.com/cyberman54/ESP32-Paxcounter/tree/master/src/hal

If you see your board in that list, then it should be supported soon. Keep an eye out for an 0.1.2 release which may include that expanded support.

candrist, 2020-01-25:
Where would I set MISO, MOSI, and SCK?

paidforby, 2020-01-25:
I have never had to specific MISP, MOSI, and SCK. Perhaps I've always used a board for which the defaults work. Someone else had luck with the syntax like this,

```
#define LORA_SCK SCK
#define LORA_MISO MISO
#define LORA_MOSI MOSI
```
However, they were using the refactored code that is located in PR https://github.com/sudomesh/disaster-radio/pull/44

See https://github.com/sudomesh/disaster-radio/issues/40#issuecomment-578245399 for their complete solution.

morganrallen, 2020-01-25:
I haven't looked at this code in a a while but if the underlying LoRa class object is exposed you should be able to call `setSPI`
See https://github.com/sandeepmistry/arduino-LoRa/blob/master/API.md#set-spi-interface

paidforby, 2020-01-25:
Thanks @morganrallen `LoRa.setSPI()` should be accessible. Just make sure you call it before `Layer1.init()` is called (since that calls `LoRa.begin()`) I'm not sure what you will need to pass into `setSPI` for your board, but it should be of the type `SPIClass`.

candrist, 2020-01-29:
Thanks. I was able to get it flashed and working.

Closed 2020-01-29.

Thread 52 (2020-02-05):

10% duty cycle for EU

samuk, 2020-02-05:
It looks like if we set 869.4-869.65 MHz  we get 10% Duty cycle and 500mW (the best option)

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

Image from page 11 of this document https://www.ofcom.org.uk/__data/assets/pdf_file/0025/38095/final_report.pdf

Would it be feasible to implement a 10% duty cycle? Some kind of buffer that broadcasts messages after a few seconds delay?

Assuming a message takes 1 second. Where a node received two messages within ten seconds, one would be routed immediately and the second after a ten-second delay?

This may be a useful reference: https://www.thethingsnetwork.org/docs/lorawan/duty-cycle.html

tlrobinson, 2020-02-05:
Yeah, this would be good. I think `LoRaLayer2` should enforce the duty cycle, since it also sends routing messages the `disaster-radio` code doesn’t know about.

We’d want a way for “clients” to receive an ack from `LoRaLayer2` (`WebSocketClient` currently immediately sends returns an ack without feedback from LoRa) so we can show that the message is delayed, and also probably avoid broadcasting to other local clients until it’s ack’d (or at least display that it’s pending transmission)

samuk, 2020-02-06:
Thanks, if we did end up with some kind of buffer system it might be interesting to add some logic;

Only broadcast message if at least x entries in the routing table.

It would add some rudimentary store and forward capability, eventually, you'd run out of memory and have to drop messages but might be interesting.

X could be user-configurable and maybe default to two connected nodes?

matthewrwright, 2020-02-06:
My only concern here would be if you're in a situation where you have simplex communication. It may be that I'm running a better antenna or higher effective TX power and the other side can hear me, but I can't hear them possibly?

dmth, 2020-03-18:
Just for reference: This document describes the legal situation in Germany, 10% Duty Cycle seems to be ok for 869.4-869.65 MHz.

https://www.bundesnetzagentur.de/SharedDocs/Downloads/DE/Sachgebiete/Telekommunikation/Unternehmen_Institutionen/Frequenzen/Allgemeinzuteilungen/2018_05_SRD_pdf

paidforby, 2020-04-10:
I'm looking at working on this.

My thinking is,

Add a duty cycle setting to LoRaLayer2. Initially, for simplicity, I will assume a transmit time of 1s for every packet. Then given a desired duty cycle, LL2 would calculate an interval and only transmit a message once that interval has expired. So at a 10% duty cycle, you could transmit every 10s for a total of 6s on air per 60s.

Eventually, we would want LL2 to actually calculate the airtime for the packet (or there may be an easy way to detect airtime with sandeep's arduino-LoRa?). This would complicate the interval calculation and I would need to think more about how to actually use the airtime information.

I already have a buffer in the LL2 code, so I code just expand that (I also think it needs to be rewritten as a FIFO buffer) and perhaps `LL2.sendToLayer2()` could return your messages place in the buffer?

Alternatively, there is @tlrobinson suggestion that the buffering could happen in the Layer3 LoRaClient code. This would possibly make more sense if we implement the actual airtime calculation instead of just using the interval workaround. Then a node could keep track of how long it has been on air for the last 60s (or 30s or 10s?) and once it exceeds the specified duty cycle, start returning a wait error to the Layer3 code.

However, I would be concerned that this solution would result in a node transmitting in "one blast" everything in its buffer and then having to wait for some timeout to transmit again.

>We’d want a way for “clients” to receive an ack from LoRaLayer2 (WebSocketClient currently >immediately sends returns an ack without feedback from LoRa)

I do agree with @tlrobinson that this ack'ing needs to be refactored. I will looking into passing an ack from Layer1 up to the Layer3 clients, should be relatively straightforward. It may be useful to have a standard for Layer3 clients sending acks to each other?

>My only concern here would be if you're in a situation where you have simplex communication. It >may be that I'm running a better antenna or higher effective TX power and the other side can hear >me, but I can't hear them possibly?

@matthewrwright this is a valid concern and there is no good way to account for it. The "acking" that we are talking about is internal to the firmware. There is no plan to implement acking within the LoRaLayer2 protocol, specifically because of duty cycle concerns and the simplex situation you identified. Obviously, someone could implement acking at a higher layer, if they wanted to deal with the duty cycle and simplex possibility.

Juul, 2020-04-10:
In case you all hadn't seen here is the airtime calculation algorithm [implemented in a google spreadsheet](https://docs.google.com/spreadsheets/d/1voGAtQAjC1qBmaVuP1ApNKs1ekgUjavHuVQIXyYSvNc/edit#gid=0).

paidforby, 2020-04-15:
@Juul thanks for the reminder about that spreadsheet, I've implemented these same calculation in C with this commit, https://github.com/sudomesh/LoRaLayer2/commit/e41dd1a8c366e1fa8731f95ebfe8624811ec2f65.

I was thinking more about how to use this calculation. I think it makes sense to calculate this once a packet is transmitted and then use it as the basis for the next interval.

For example, given default radio settings, a duty cycle of 10%, and a payload of 17 bytes. You would calculate airtime to be 114.688ms. Then calculate the time until you can transmit another packet like so, 114.688/.1 = 1146.88ms or 1.4688s. The interval would then be set to 1147ms. Then another packet of any size could be sent. i believe this will always keep the instantaneous airtime to the required 10% (or whatever set the duty cycle to). The bigger the packet the longer you wait to send the next packet and so on.

This has the draw back that it is more difficult (would have to inspect the entire buffer) for a Layer3 client to find out how long before it's message is sent. The easiest option is for the client to know what place in the buffer it has. Additionally, I need to work out how to return the necessary variables from `Layer.transmit()` because I need the length of the transmitted packet and the sequence number of the transmitted packet (or some identifier so Layer3 can know that it's packet has been sent).

@geeksville is working on a merge that will introduce async Layer1 functions, see https://github.com/sudomesh/LoRaLayer2/issues/10#issuecomment-613650821 so I may wait until that work is complete to return to figure out some of these issues.

paidforby, 2020-04-15:
I have successfully implemented a duty cycle option in LoRaLayer2. There are still something outstanding TODOs and considerations.

* How to deal with the routing interval? What if you choose a short routing interval and a low duty cycle (long duty interval). Then the transmit buffer would eventually be filled with just routing packets. Maybe the routing interval should be a function of the duty cycle?

* How to deal with a full transmit buffer? Currently all the fifo buffers hold 16 packet. If I try transmitting 17 messages at the same time, what happens to that 17th packet? Should Layer1 produce an error? Should Layer2 handle the retry? Should it be held in the L3toL2 buffer? Should the error propagate all the way to Layer3? If so, what does Layer3 do with that error message?

* I need expose duty cycle as an option in the console and add it to the `settings.cpp`. And allow for the ability to turn of the duty cycle?

geeksville, 2020-04-16:
btw: One way of solving the routing interval is to move to the other dominant mesh algorithm.  It seems like disaster.radio is based (inspired?) by AODV?  Which is a bit more optimal in lots of ways.  But you might want to look into DSR algorithm?  They are not as optimal, but a) no need to share routing tables.

paidforby, 2020-04-17:
disaster.radio's routing protocol was largely inspired by the babel routing protocol, which I suppose was inspired by both DSDV and AODV. That just what I was most familiar with at the time I began writing LL2. I'm going to look into the DSR alogrithm, I hadn't really consider it.

samuk, 2020-05-21:
> Then the transmit buffer would eventually be filled with just routing packets.

Is this duty cycle stuff affected by the change to reactive routing https://github.com/sudomesh/disaster-radio/issues/57#issuecomment-628040381

paidforby, 2020-05-21:
No, the duty cycle still applies. The way I wrote the duty cycle, it just cares about the length of any transmission, not the contents of the transmission. Of course, not sending routing table packets will help avoid using up airtime and therefore make the duty cycle easier to observe. I think, once I expose the duty cycle in config.h and/or the console interface, we can close this issue. The other outstanding todos are more or less outside the scope of this issue.

Closed 2020-08-21.

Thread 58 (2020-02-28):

Tidy up hardware support

samuk, 2020-02-28:
It would be good to tidy up
https://github.com/sudomesh/disaster-radio/blob/master/firmware/esp32/config.h

To properly support  at least the boards listed here:
https://github.com/sudomesh/disaster-radio/wiki/Devices--&-Hardware

I think the pin definitions needed can be found in these files:
https://github.com/cyberman54/ESP32-Paxcounter/tree/master/src/hal

paulo060507, 2020-02-28:
Good

paidforby, 2020-03-06:
As mentioned in #33 I have tested with the TTGO T-Beam V07 and I would consider that board to now be fully-supported. There's still some work to be done on actual implementation of the GPS client.

I believe that the T-Beam referenced in the `config.h` file is the V10, not V07 because it has pins for the OLED screen which is only on V10. I'm also unsure why the LoRa pin definitions are commented out. We should make a point of differentiating between the V07 and V10.

I have a LoPy4 that I am hoping to test soon. After that, I only know of anecdotal claims for the Heltec V2, Sparkfun 1 channel, and TTGO V1. I'm not sure the status of development on the latest DisasterRadio board.

paulo060507, 2020-03-10:
ok i'm new here but i will be following and i find this question of the oled display very interesting i believe that really only in the last version

marcidy, 2020-06-27:
FYI, #74 included an update to config.h for heltec-v2.

https://github.com/sudomesh/disaster-radio/blob/78dac9bc4edb161b691666e628e756f4a3710925/firmware/config.h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

Not clear if that closes this issue.

paidforby, 2020-06-27:
I just made some edits to the wiki that bring it up to date. I think we can close this issue unless @samuk has an objection.

It should also be noted here that most of the pin definitions needed for LoRa and OLED related stuff are defined here https://github.com/espressif/arduino-esp32/tree/master/variants. Which is why the T-Beam pins are commented out and the TTGO-v2 pins are not included in our config.h.

samuk, 2020-06-30:
Great. This ticket was for someone who volunteered to do some hardware support stuff. They never materialised to do any work, so happy to close now.

marcidy, 2020-06-30:
If you've got more hardware issues, I can take a look.
I can also offer to test on the heltec-v2 boards when mine aren't occupied
with work.
I attempted to launch SSB using Patchwork but the AppImage doesn't work for
me and promptly decided to do something else than deal with it.  If that's
the best place to keep abreast of discussion I'll figure it out.  If you
post more tickets tagged with help-wanted and/or hardware I'll look at
those directly.

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

paidforby, 2020-07-01:
Cool, that's good to know. This is probably the best place to stay in the loop on firmware related stuff. I'm not that active on SSB, though I've also been meaning to get back into it. (I always run into problems like that with SSB too and get discouraged quickly).

Closed 2020-06-27.

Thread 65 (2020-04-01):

Remove Serial.prints from Console.cpp

paidforby, 2020-04-01:
After progress in https://github.com/sudomesh/disaster-radio/issues/48#issuecomment-607319579, there are still some outstanding TODOs in `middleware/Console.cpp`. Most notably, the use of Serial.print statements (except in the `DEBUG_OUT` conditions?) need to be removed and replaced with the Console `print` function. This way the console will not be specific to the Arduino serial interface and could use any Stream.

Part of the challenge is that LoRaLayer2 has some print functions built-in for convenience sake. So we need to decide on a good way of adapting these functions.

paidforby, 2020-04-01:
@beegee-tokyo made a good suggestion on how to refactor the routing table print out here, https://github.com/sudomesh/disaster-radio/issues/48#issuecomment-591276758, might just need to be synced with the updates to the console.

paidforby, 2020-04-01:
Also, there is a closely related issue with the telnet client. Whenever a `%s` is included in a `sprintf()` that is then sent to the telnet client, a CR-LF (carriage return, line feed) is printed at the end of the string. For example, once a username is entered, the `printPrompt` function returns,
```
<username
>
```
 This only happens in the telnet client, not the serial client. I have yet to find a solution.

Perhaps it makes sense to write our own `printf` style function for the Console printing? There is a decent example of generally how to do this here, https://arduino.stackexchange.com/questions/176/how-do-i-print-multiple-variables-in-a-string.

paidforby, 2020-04-08:
I've removed the remaining non-debug Serial.printf statements in two ways.
1. I added a utility function that converts byte arrays into hexidecimal char arrays to print, see [utils.cpp](https://github.com/sudomesh/disaster-radio/blob/1.0.0-rc.1/firmware/esp32/utils/utils.cpp)
2. I created a `getRoutingTable` function in LoRaLayer2 that writes to a char array what was previously just printed to Serial, see [here](https://github.com/sudomesh/LoRaLayer2/blob/master/src/LoRaLayer2.cpp#L219)

It's possible that I will adjust the `getRoutingTable` to write the table to a char array of some standard format, such as JSON. This will depend heavily on how I refactor the websocket client to parse for and display the routing table.

I'm going to considered this issue solved, an further revisions to the console can be discussed in a new issue.

paidforby, 2020-04-08:
Also, regarding the username printing over telnet, I discovered that the issue was trailing CR-LFs that were being added upon entering the username through telnet. To deal with this at added a string tokenization right when the console receives the username [here](https://github.com/sudomesh/disaster-radio/blob/1.0.0-rc.1/firmware/esp32/middleware/Console.cpp#L95), which removes those trialing CR-LFs. The console now works well both through serial and telnet.

Closed 2020-04-08.

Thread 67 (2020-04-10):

Better documentation for solar node and hardware

jooray, 2020-04-10:
Being a software guy that does not understand hardware very well yet, I would like a written set of recommendations for building a solar node (I believe dev board is covered by https://www.aliexpress.com/item/4000396836096.html ).

I would like to suggest an enhancement to https://github.com/sudomesh/disaster-radio/wiki/Devices--&-Hardware section Complete Solar nodes.

I would like a description of each component and how it relates to other components. What parameters to look for and what are the alternatives.

The wishlist from Aliexpress is nice, but it misses a type and quantities.

For example:
 - Waterproof box: https://www.aliexpress.com/item/4000429348282.html?spm=0.8937489.0.0.47902e0e5UYCHn - no longer available. I found https://www.aliexpress.com/item/4000442364567.html as an alternative. Will it be large enough? 4-8mm or 9-12mm? (I guess 4-8mm should be enough given the size of the cable, but what about the antenna?)

 - Cable: https://www.aliexpress.com/item/33053500652.html?spm=0.8937489.0.0.67042e0esfbOd8 - 2 cores? 3 cores? 4 cores?

 - Solar panel: https://www.aliexpress.com/item/4000031921317.html?spm=0.8937489.0.0.19bd2e0emPN0dl - the description mentions 20W, but the store does not ship this to my country. What parameters and  connectors are needed? For example, would this work as an alternative? https://www.aliexpress.com/item/32847502994.html Parameters seem to be similar, but I don't know about the connectors (I am fine with soldering, but I don't know what are the standard connectors or if I should solder).

- Batteries - https://www.aliexpress.com/item/32693860069.html?spm=0.8937489.0.0.67042e0euw6kKt I need four pieces, right?

- Controller - https://www.tindie.com/products/xorbit/lifepo4weredsolar1/ - default charge - what should I use? Thermistor - yes or no?

What I suggest is describing each component, how many pieces and people could submit alternatives (stores) available locally.

People could also send component kits, I would happily pay for that.

(I am a part of local city community that would like to deploy this city-wide and play with the project. There are a few 3D printing gurus, more than a few software developers, but we would really like some guidance in the hardware part).

samuk, 2020-04-10:
Hi Juraj that page is largely my fault

> I would like a description of each component and how it relates to other components. What
> parameters to look for and what are the alternatives.

Yeah fair enough, i'll try an improve that page. There's a bit more here:
https://hackaday.io/project/170069-disaster-radio-lora-mesh

> * Waterproof box:

I've just re-added a box that's in stock. The 8mm gland should work.

> * Cable: https://www.aliexpress.com/item/33053500652.html?spm=0.8937489.0.0.67042e0esfbOd8 - 2
> cores?

2 core, you just get a positive and a negative from a solar panel.

> * Solar panel: https://www.aliexpress.com/item/4000031921317.html?spm=0.8937489.0.0.19bd2e0emPN0dl
> - the description mentions 20W, but the store does not ship this to my country. What parameters and
> connectors are needed? For example, would this work as an alternative?

You just need two bare ends of wire, to attach to the screw terminals on the solar controller. (Assuming you ask for the screw terminals pre-soldered by Xorbit, he charges a couple of dollars for this)

> https://www.aliexpress.com/item/32847502994.html Parameters seem to be similar, but I don't know
> about the connectors (I am fine with soldering, but I don't know what are the standard connectors
> or if I should solder).

That will work for a bit, the plastic covering degrades fairly rapidly on those flexible panels which is why I specified the glass panel which _should_ last a bit longer before it fails.

> * Batteries - https://www.aliexpress.com/item/32693860069.html?spm=0.8937489.0.0.67042e0euw6kKt I
> need four pieces, right?

Probably. If you live on the equator one or two may work. In the Arctic you may need 10+.

I've specced this for 1hour of sunlight/ day which is what we get in January in midwinter in the UK.

> * Controller - https://www.tindie.com/products/xorbit/lifepo4weredsolar1 - default charge - what
> should I use?

It depends what panel you add, if you use the 20w then the 2.1A will be fine. If you use a 10w panel you should get away with the 0.5A

>Thermistor - yes or no?

Yes, get the one he recommends

> What I suggest is describing each component, how many pieces and people could submit alternatives
> (stores) available locally.

Yeah fair enough. It needs more work and testing.

Thanks

Sam

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

samuk, 2020-04-10:
I've made some changes to this page https://github.com/sudomesh/disaster-radio/wiki/Devices--&-Hardware

And the Aliexpress wishlist, which I think addresses these concerns, please re-open the ticket if not.

jooray, 2020-04-12:
Thank you, this description is amazing.

Closed 2020-04-10.

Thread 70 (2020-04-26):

LoStik + Linux application?

paidforby, 2020-04-26:
While the updating the simulator i got the idea that it might be worth it to write a real linux application that could interface with a real disaster radio network, not just a simulated network.

As it stands, I've ported almost the entire disaster radio firmware to generic C++. You can see that the [simulator firmware](https://github.com/sudomesh/disaster-radio-simulator/tree/master/routers),  is now very similar to the [esp32 firmware](https://github.com/sudomesh/disaster-radio/tree/master/firmware/esp32). They are so similar that I may eventually merge the two.

So the main challenge would be to find a LoRa transceiver that has good Linux support and to write another Layer1 interface for it.

I came across the LoStik, https://www.crowdsupply.com/ronoth/lostik and was curious if anyone has experience with it or has other recommendations for a LoRa-to-USB device, such as this one, https://www.tindie.com/products/allankliu/low-cost-lora-usb-dongle-with-stm32/.

samuk, 2020-04-27:
I'm sure @tlrobinson got a Lostik working? I can't find the ticket now though?

Bovril1a, 2020-04-29:
Re the Lostik it "relatively" easily allows for setting up TCP/IP connectivity via PPP

https://github.com/jgoerzen/lorapipe/blob/master/doc/lorapipe.1.md

I managed after some support from jgoerzen to set two Raspberry Pi's (3B+ and 4) up and ran (dial up speed) SSH and even opened an *incredibly* slow VNC session between them.. 8-) Even robust enough to run a short WireGuard VPN session between the two.

If we can set up the same sort of USB, plug and play (ish) functionality in the LORA32's and T-Beams, could add substantially to ease of porting messaging and other functionality

samuk, 2020-05-06:
@paidforby Here's the config @tlrobinson used: https://github.com/sudomesh/disaster-radio/issues/50

paidforby, 2020-05-06:
Good catch. Some how that issue escaped my awareness. I should be able to adapt the example in that issue, or at least use its documentation, to get the LoStik working with the simulator code as an initial step toward a Linux application. Thanks.

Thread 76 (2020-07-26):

Two devices can not be synchronized message

LuckyFishGeek, 2020-07-26:
I was a rookie, according to the contents inside the readme, I built two devices, but after wifi connection respectively, the two devices can synchronize messages, help me
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

LuckyFishGeek, 2020-07-26:
It has been resolved

Closed 2020-07-26.

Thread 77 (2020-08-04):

device restart when input any command from serial port

yuchangyuan, 2020-08-04:
Device will restart after input any command.

firmware revision: 44cf2dfc75a68d6309bbc8a20345a3e2ef2dee47
hardware: TTGOv2

below is log for  `platformio device monitor` with `/help` command:

```
--- Available filters and text transformations: colorize, debug, default, direct, esp32_exception_decoder, hexlify, log2file, nocontrol, printable, send_on_enter, time
--- More details at http://bit.ly/pio-monitor-filters
--- Miniterm on /dev/ttyUSB0  115200,8,N,1 ---
--- Quit: Ctrl+C | Menu: Ctrl+T | Help: Ctrl+T followed by Ctrl+H ---

     ___              __                            ___
 ___/ (_)__ ___ ____ / /____ ____      _______ ____/ (_)__
/ _  / (_-</ _ `(_-</ __/ -_) __/ _   / __/ _ `/ _  / / _ \
\_,_/_/___/\_,_/___/\__/\__/_/   (_) /_/  \_,_/\_,_/_/\___/
v1.0.0-rc.2
Local address of your node is ���?h��?8xV��V�����?4␒��␐
Type '/join NICKNAME' to join the chat, or '/help' for more commands.
< > /help
Commands: /help /join /nick /raw /lora /set /restart

Stack smashing protect failure!

abort() was called at PC 0x400f8d93 on core 1

Backtrace: 0x400929ec:0x3ffd1e50 0x40092c1d:0x3ffd1e70 0x400f8d93:0x3ffd1e90 0x400d659a:0x3ffd1eb0 0x400d65cb:0x3ffd2100 0x400d65fb:0x3ffd2120 0x400d4062:0x3ffd2240 0x402106d3:0x3ffd2480 0x402106d3:0x3ffd24a0 0x402106d3:0x3ffd24c0 0x400d670a:0x3ffd24e0 0x400d32c9:0x3ffd2500 0x400f5141:0x3ffd2520 0x4008f101:0x3ffd2540

Rebooting...
ets Jun  8 2016 00:22:57

rst:0xc (SW_CPU_RESET),boot:0x13 (SPI_FAST_FLASH_BOOT)
configsip: 188777542, SPIWP:0xee
clk_drv:0x00,q_drv:0x00,d_drv:0x00,cs0_drv:0x00,hd_drv:0x00,wp_drv:0x00
mode:DIO, clock div:2
load:0x3fff0018,len:4
load:0x3fff001c,len:1044
load:0x40078000,len:8896
load:0x40080400,len:5828
entry 0x400806ac
Got username n2
Got IF setting BLE
* Initializing SD card...
[E][sd_diskio.cpp:739] sdcard_mount(): f_mount failed 0x(3)
 --> SD card not found
* Initializing SPIFFS...
E (547) SPIFFS: mount failed, -10025
[E][SPIFFS.cpp:72] begin(): Mounting SPIFFS failed! Error: -1
-* Initializing serial...
* Initializing BLE...
* Initializing LoRa...
 --> Layer1 init succeeded
 --> LL2 init succeeded
 --> LL2 node address: 918c1b8c
* Initializing display...
WelcomeMessage username: >n2<

00c|Welcome to DISASTER RADIO >n2<< >
00c|WARNING: SD card not found, functionality may be limited< >
```

paidforby, 2020-08-07:
Weird, I thought I tested this. I may have introduced a bug in 9d137b4f5f8d88131f2c0b4dd2e638cf73cfec5a. Or in another commit when I was making changes to make the console shared between the dev board and the simulator. I'll look into this when I get a chance.

deafboy, 2020-08-10:
I had to revert even further, to commit fbf2187da4e0e6828c11929be720f3ab243bdd40, to avoid this problem.

paidforby, 2020-08-11:
Hmm, maybe it's more likely that this commit https://github.com/sudomesh/disaster-radio/commit/43075131149f1456c2364c3cf8fbb5121cefae65 which updated LoRaLayer2 caused this bug? Or maybe try updating to the latest commit of LoRaLayer2 (https://github.com/sudomesh/LoRaLayer2/commit/b071e53ceb6d2530fa2de28019165fd7534a378f), not sure where I left off there, but it's possible I neglected to update the commit in platformio.ini.

rawesomeawesome, 2020-08-14:
I've managed to compile the platform myself, having to remove tinygps to make it work for whatever reason, but i'm now facing this issue. The only reason i was unable to use the precompiled bin which didn't do this, is that the frequency was set wrong for my boards, which are cheaper 433mhz models

paidforby, 2020-08-16:
I found the cause of this bug. The culprit is the following line in [src/middleware/Console.cpp](https://github.com/sudomesh/disaster-radio/blob/master/firmware/src/middleware/Console.cpp#L51),

```
memset(response.message, 0, DATAGRAM_MESSAGE);
```

Looks like I forgot to update the `DATAGRAM_MESSAGE` constant to match with the updates to LoRaLayer2. This was causing a buffer overflow during this memset and triggering a stack smashing failure. The quick solution is to update `DATAGRAM_MESSAGE` to be the correct number (i.e. 238). The right solution is to move this constant in to `LoRaLayer2.h` and use that instead, since that is where all routing protocol related changes are made.

Sorry about this problem, I've previously struggled with how to architecture this project. That `DATAGRAM_MESSAGE` constant is a leftover from when I defined the datagram struct in the Disaster Radio code and not in LoRaLayer2.

I'll push a commit shortly that will make the quick fix. I still need to test the right solution of moving DATAGRAM_MESSAGE to LoRaLayer2.h to make sure it doesn't have any unintended side effects.

paidforby, 2020-08-16:
I should also point out that I was only memsetting the `message` portion of the `response` datagram, which is wrong and would cause a buffer overflow, because the `DATAGRAM_MESSAGE` constant represents the total length of the datagram (i.e. header+message). Anyway, I'll fix that also, by memsetting the whole datagram.

Closed 2020-08-16.

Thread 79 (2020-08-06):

build firmware for ttgo-lora32-v2 failed on guix 1.1.0

wxie2017, 2020-08-06:
wxie@guix ~/work/disaster-radio/firmware$ ~/.local/bin/pio run --verbose
Processing ttgo-lora32-v2 (board: ttgo-lora32-v1; build_flags: -DTTGO_LORA_V2, -DARDUINO_LORA, -DHAS_OLED, -I./src; platform: https://github.com/platformio/platform-espressif32.git; framework: arduino; upload_port: /dev/ttyUSB0; monitor_port: /dev/ttyUSB0; monitor_speed: 115200; board_build.partitions: custompart.csv; lib_deps: AsyncTCP, ESP Async WebServer@1.2.3, LoRa@0.7.2, https://github.com/jgromes/RadioLib#3682c6c9215891e3afb7672f1235fde1c3bd75fd, https://github.com/sudomesh/LoRaLayer2#1e2204ebaa7f81b8d06853fedb92ab0ddc9b9414, https://github.com/paidforby/AsyncSDServer#13375c6be978cb34180378ecf4042a3a4a1f5eab, ESP8266 and ESP32 OLED driver for SSD1306 displays, TinyGPSPlus@1.0.2, ArduinoJson)
--------------------------------------------------------------------------------------------------------------------------------------------
CONFIGURATION: https://docs.platformio.org/page/boards/espressif32/ttgo-lora32-v1.html
PLATFORM: Espressif 32 1.12.4 #08ef4bf (git+https://github.com/platformio/platform-espressif32.git) > TTGO LoRa32-OLED V1
HARDWARE: ESP32 240MHz, 320KB RAM, 4MB Flash
DEBUG: Current (esp-prog) External (esp-prog, iot-bus-jtag, jlink, minimodule, olimex-arm-usb-ocd, olimex-arm-usb-ocd-h, olimex-arm-usb-tiny-h, olimex-jtag-tiny, tumpa)
PACKAGES:
 - framework-arduinoespressif32 3.10004.200129 (1.0.4)
 - tool-esptoolpy 1.20600.0 (2.6.0)
 - toolchain-xtensa32 2.50200.80 (5.2.0)
xtensa-esp32-elf-g++ -o "/home/wxie/work/disaster-radio/firmware/main.ino.cpp" -x c++ -fpreprocessed -dD -E "/tmp/tmpr09_spwu"
sh: /home/wxie/.platformio/packages/toolchain-xtensa32/bin/xtensa-esp32-elf-g++: Datei oder Verzeichnis nicht gefunden
*** Error 127
AssertionError: :
  File "/home/wxie/.local/lib/python3.8/site-packages/platformio/builder/main.py", line 168:
    env.SConscript("$BUILD_SCRIPT")
  File "/home/wxie/.platformio/packages/tool-scons/script/../engine/SCons/Script/SConscript.py", line 597:
    return _SConscript(self.fs, *files, **subst_kw)
  File "/home/wxie/.platformio/packages/tool-scons/script/../engine/SCons/Script/SConscript.py", line 286:
    exec(compile(scriptdata, scriptname, 'exec'), call_stack[-1].globals)
  File "/home/wxie/.platformio/platforms/espressif32/builder/main.py", line 223:
    target_elf = env.BuildProgram()
  File "/home/wxie/.platformio/packages/tool-scons/script/../engine/SCons/Environment.py", line 219:
    return self.method(*nargs, **kwargs)
  File "/home/wxie/.local/lib/python3.8/site-packages/platformio/builder/tools/platformio.py", line 61:
    env.ProcessProgramDeps()
  File "/home/wxie/.platformio/packages/tool-scons/script/../engine/SCons/Environment.py", line 219:
    return self.method(*nargs, **kwargs)
  File "/home/wxie/.local/lib/python3.8/site-packages/platformio/builder/tools/platformio.py", line 118:
    env.BuildFrameworks(env.get("PIOFRAMEWORK"))
  File "/home/wxie/.platformio/packages/tool-scons/script/../engine/SCons/Environment.py", line 219:
    return self.method(*nargs, **kwargs)
  File "/home/wxie/.local/lib/python3.8/site-packages/platformio/builder/tools/platformio.py", line 327:
    env.ConvertInoToCpp()
  File "/home/wxie/.platformio/packages/tool-scons/script/../engine/SCons/Environment.py", line 219:
    return self.method(*nargs, **kwargs)
  File "/home/wxie/.local/lib/python3.8/site-packages/platformio/builder/tools/piomisc.py", line 240:
    out_file = c.convert(ino_nodes)
  File "/home/wxie/.local/lib/python3.8/site-packages/platformio/builder/tools/piomisc.py", line 94:
    return self.process(contents)
  File "/home/wxie/.local/lib/python3.8/site-packages/platformio/builder/tools/piomisc.py", line 115:
    assert self._gcc_preprocess(contents, out_file)
======================================================== [FAILED] Took 0.66 seconds ========================================================

Environment        Status    Duration
-----------------  --------  ------------
ttgo-lora32-v1     IGNORED
ttgo-lora32-v2     FAILED    00:00:00.661
ttgo-lora32-tbeam  IGNORED
heltec-v2          IGNORED
sparkfun-lora      IGNORED
lopy4              IGNORED
================================================== 1 failed, 0 succeeded in 00:00:00.661 ==================================================

What's the problem?

paidforby, 2020-08-07:
I'm now sure what the error is here, looks like it's not finding the file `/home/wxie/.platformio/packages/toolchain-xtensa32/bin/xtensa-esp32-elf-g++`? This must be a problem with your build environment because my tests in travisCI pass, https://travis-ci.org/github/sudomesh/disaster-radio. Maybe make sure platformio is up to date (or maybe downgrade it)? I am using `PlatformIO, version 4.3.5a1`, you can find this by running `pio --version`.

Maybe try using the stable version of espressif32 by changing line 23 in platformio.ini to,
```
platform = espressif32
```

If this doesn't work, maybe figure out how to install the xtensa toolchain manually. This should be done automatically by platformio, but it seems like yours is not being installed properly (or it is installed in the wrong location?),

wxie2017, 2020-08-09:
Thanks.
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
paidforby, 2020-08-16:
@wxie2017 you are on older version of platformio (PlatformIO, version 4.3.4). Would you mind updating to the dev branch by running the following,
```
pio upgrade --dev
pio update
```
And see if that makes a difference. Everything else about your environment looks that same. You could also try @rawesomeawesome suggestion of removing all references to TinyGPS.

paidforby, 2020-08-16:
@rawesomeawesome you are not pulling tagged version of TinyGPS, which means you are mostly likely using the latest commit, that is probably why it isn't working. Try pulling the version `1.0.2` (https://github.com/mikalhart/TinyGPSPlus/releases/tag/v1.0.2) by putting `@1.0.2` after the library, like in my [platformio.ini](https://github.com/sudomesh/disaster-radio/blob/master/firmware/platformio.ini#L40).

paidforby, 2020-08-16:
@wxie2017 I downgraded my platformio to 4.3.4 and had no problems compiling. Is there anyway you can try compiling in a clean environment (like a VM)? I've never used guix, I'm mostly on Ubuntu 18.04.

wxie2017, 2020-08-18:
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

The upgrade failed:

wxie@guix ~/work/disaster-radio/firmware$ ~/.local/bin/pio upgrade --dev
Please wait while upgrading PlatformIO ...
Error: ['/gnu/store/11l2qmzfgsp7k345mv6x1vn64q8330kw-python-wrapper-3.8.2/bin/python', '-m', 'pip', '--no-cache-dir', 'install', '--upgrade', '/home/wxie/.platformio/.cache/piocoredevelop.zip']

Traceback (most recent call last):
  File "/gnu/store/09a5iq080g9b641jyl363dr5jkkvnhcn-python-3.8.2/lib/python3.8/runpy.py", line 193, in _run_module_as_main
    return _run_code(code, main_globals, None,
  File "/gnu/store/09a5iq080g9b641jyl363dr5jkkvnhcn-python-3.8.2/lib/python3.8/runpy.py", line 86, in _run_code
    exec(code, run_globals)
  File "/home/wxie/.guix-profile/lib/python3.8/site-packages/pip/__main__.py", line 16, in <module>
    from pip._internal import main as _main  # isort:skip # noqa
  File "/home/wxie/.guix-profile/lib/python3.8/site-packages/pip/_internal/__init__.py", line 40, in <module>
    from pip._internal.cli.autocompletion import autocomplete
  File "/home/wxie/.guix-profile/lib/python3.8/site-packages/pip/_internal/cli/autocompletion.py", line 8, in <module>
    from pip._internal.cli.main_parser import create_main_parser
  File "/home/wxie/.guix-profile/lib/python3.8/site-packages/pip/_internal/cli/main_parser.py", line 11, in <module>
    from pip._internal.commands import (
  File "/home/wxie/.guix-profile/lib/python3.8/site-packages/pip/_internal/commands/__init__.py", line 6, in <module>
    from pip._internal.commands.completion import CompletionCommand
  File "/home/wxie/.guix-profile/lib/python3.8/site-packages/pip/_internal/commands/completion.py", line 6, in <module>
    from pip._internal.cli.base_command import Command
  File "/home/wxie/.guix-profile/lib/python3.8/site-packages/pip/_internal/cli/base_command.py", line 26, in <module>
    from pip._internal.index import PackageFinder
ImportError: cannot import name 'PackageFinder' from 'pip._internal.index' (/home/wxie/.guix-profile/lib/python3.8/site-packages/pip/_internal/index/__init__.py)

* Upgrade using `pip install -U platformio`
* Try different installation/upgrading steps:
  https://docs.platformio.org/page/installation.html

wxie2017, 2020-08-18:
> @wxie2017 I downgraded my platformio to 4.3.4 and had no problems compiling. Is there anyway you can try compiling in a clean environment (like a VM)? I've never used guix, I'm mostly on Ubuntu 18.04.

That's sad news.

I will try from Debian GNU.

wxie2017, 2020-08-27:
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

firmware build on Debian Buster is ok.
Building .pio/build/ttgo-lora32-v2/firmware.bin
Advanced Memory Usage is available via "PlatformIO Home > Project Inspect"
RAM:   [==        ]  20.5% (used 67156 bytes from 327680 bytes)
Flash: [========= ]  86.4% (used 1755417 bytes from 2031616 bytes)
esptool.py v2.6
========================== [SUCCESS] Took 192.09 seconds ==========================

Environment        Status    Duration
-----------------  --------  ------------
ttgo-lora32-v1     IGNORED
ttgo-lora32-v2     SUCCESS   00:03:12.088
ttgo-lora32-tbeam  IGNORED
heltec-v2          IGNORED
sparkfun-lora      IGNORED
lopy4              IGNORED
=========================== 1 succeeded in 00:03:12.088 ===========================

paidforby, 2020-08-28:
Cool stuff. That's good to know it can be built on Debian. i was pretty sure I used to build it on debian, but that was a few years ago, so it's good to have that confirmed.

I'm gonna close this issue and label it as "wontfix". Unless you plan on revisiting the guix build sometime soon?

Closed 2020-08-28.

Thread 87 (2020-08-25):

beacon period does not survive reboot

deafboy, 2020-08-25:
beacon period setting is not persistent.

paidforby, 2020-08-26:
Hmmm, this is a very odd problem. Everything looks right in the code,

What board are you using? I'm using a TTGO-Tbeam v7. The setting seems to be persisting for me, though the GPS antenna is a little unreliable (especially after I pull power, but less so after `/restart` or pressing the reset button). My guess is that you are seeing a "false negative", that is, if the GPS does not successfully retrieve a lat-long value, then nothing is ever printed to the console, so it would look like the beaconPeriod setting did not persist (if say you changed it from 0 to 10000).

I'll add some more printing to the console that should help debug your setup. (And soon will also add a setting to toggle GPS debug printing to the console)

Let me know is your issue persists :p after I make my commit

deafboy, 2020-08-26:
ttgo-lora32-v1 and ttgo-lora32-v2. Both without GPS capability. Maybe I misunderstood and it's not supposed to work without GPS ? :)
d1601d9 did not help

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

paidforby, 2020-08-26:
Oh, you are talking about the routing table message broadcast/beacon interval, not the GPS becaon period. Very confusing. I knew I should have made those commands more distinct. Yes, that should definitely work without GPS. It looks like it is being stored in the memory, see line after reboot that reads, `Got interval setting 60000`. Maybe it isn't getting passed to the LL2 client correctly, or maybe the `/get config` print out is just wrong. Have you confirmed that two nodes do not automatically get routes to one another after `/set interval VAL` and `/restart`? Use `/lora` to check the routing table.

I'll take a closer look at this tonight.`

paidforby, 2020-08-27:
Found the problem, a stray default config in LoRaClient.cpp that was always resetting the interval right after it was set in main.ino. Sorry about that.

Also, be on the watch for a name change to that "interval" command so we can avoid future confusion with other intervals. (probably will change it to something like "routing" or "ll2" so it's more specific and could be expanded to accept other LL2 setting.)

Closed 2020-08-27.

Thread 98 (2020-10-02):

Wifi client fails to connect

grisu48, 2020-10-02:
Hey there, I really love this project :-)

I was playing around with my LILY TTGO v2 development board, which connects to my home WiFi. For that I created a `firmware/secrets.h` file according to [this old commit](https://github.com/sudomesh/disaster-radio/blob/d0f8319c65a614a6425ec29401cd43f7e6818a5b/firmware/esp32/secrets.h)

    #define WIFI_SSID "MyAwesomeHomeWifi"
    #define WIFI_PASSWORD "NotGonnaTellYou"

In almost all cases when booting the node, it fails to connect to the Wifi. However after hitting the reset button if connects. This happened in all observed cases, and always after a power-cut.
I had to let the node boot (where it failed to connect to the Wifi) and hit the reset button. Only after that it connected successfully. Before it was in all observed cases entering the AP mode, because the connection failed.

grisu48, 2020-10-11:
Fixed in PR #97

Closed 2020-10-11.

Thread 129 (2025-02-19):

Hardware list on Ali Express

mattcallaway, 2025-02-19:
Hello, I am writing to ask for the list of parts from the https://disaster.radio/learn/hardware/ site. I get an error from Ali Express: "It looks like the name of your wish list contains some sensitive language, e.g. a swear word. Please change it." Please address this, we need community-powered, distributed networking now more than ever. I, and I'm sure many other people, want to get involved and this is a road bump that may discourage some folks. I'm sure I can find hardware, but maybe some will not look any further.

samuk, 2025-02-19:
Firstly: Disaster Radio is no longer actively maintained. The advise
is to look at https://meshtastic.org/

I set the Aliexpress list up

https://www.aliexpress.com/p/wish-manage/share.html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

Many of the parts on it are discontinued now, but you could get an
idea of the solar setup. I used LifPO4 as it gets below 0c where I am,
if this is not the case for you Lipo would be cheaper

I was using https://www.tindie.com/products/silicognition/lifepo4weredsolar1/

Using NRF52 rather than ESP32 would mean you need a much smaller solar setup.

I like these for repeaters:
https://store.rakwireless.com/products/wisblock-meshtastic-starter-kit

And these for portable:
https://www.seeedstudio.com/SenseCAP-Card-Tracker-T1000-E-for-Meshtastic-p-5913.html

Thanks

Sam

Quoting Matt Callaway ***@***.***>:

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

Juul, 2025-02-19:
Hi! I just wanted to chime in and mention that I think the spiritual descendant of this project is maybe [tinySSB](https://github.com/ssbc/tinySSB) rather than meshtastic. I would also put out a small warning to anyone looking at meshtastic to learn about the organization(s) behind it and what's currently going on with trademark ownership and planned enforcement.

mattcallaway, 2025-02-19:
Thank you so much for getting back to me. I will check out this new project
immediately! Have a fantastic day and week.

*Matthew Callaway*
<http://matthewcallaway.com>707.335.6262

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

greghall-au, 2025-02-19:
You might also look at https://github.com/markqvist
'The cryptography-based networking stack for building unstoppable networks
with LoRa, Packet Radio, WiFi and everything in between.'
A very elegant system. Not quite as Plug'nPlay as Meshtastic, but more
versatile and unlikely to suffer the scalability problem of <100 nodes.
-

On Thu, 20 Feb 2025 at 08:31, Matt Callaway ***@***.***>
wrote:

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

--
Greg Hall
VK2GTH
0265 504 481
0428 850 144
-

mattcallaway, 2025-02-21:
Thanks, I'll check it out!  I'm really impressed that you all are so
responsive. I am going to weigh the options and embark on a project with my
sister-in-law who lives 800 miles away. It will be a coding/hardware
project we're going to do with my niece who's only 5 years old! Start them
young. I'm hoping there are stations between us so we can keep in touch
over radio. You're helping a family be closer and helping a young techie
get a taste for this tech. You all rock!

*Matthew Callaway*
<http://matthewcallaway.com>707.335.6262

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

samuk, 2025-02-21:
I think it's very unlikely that there will be existing stations all the way across that distance.

You'll have to deploy your own solar powered repeaters along the route. You might (or might not) find there are Meshtastic relays along the way to help you. I
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

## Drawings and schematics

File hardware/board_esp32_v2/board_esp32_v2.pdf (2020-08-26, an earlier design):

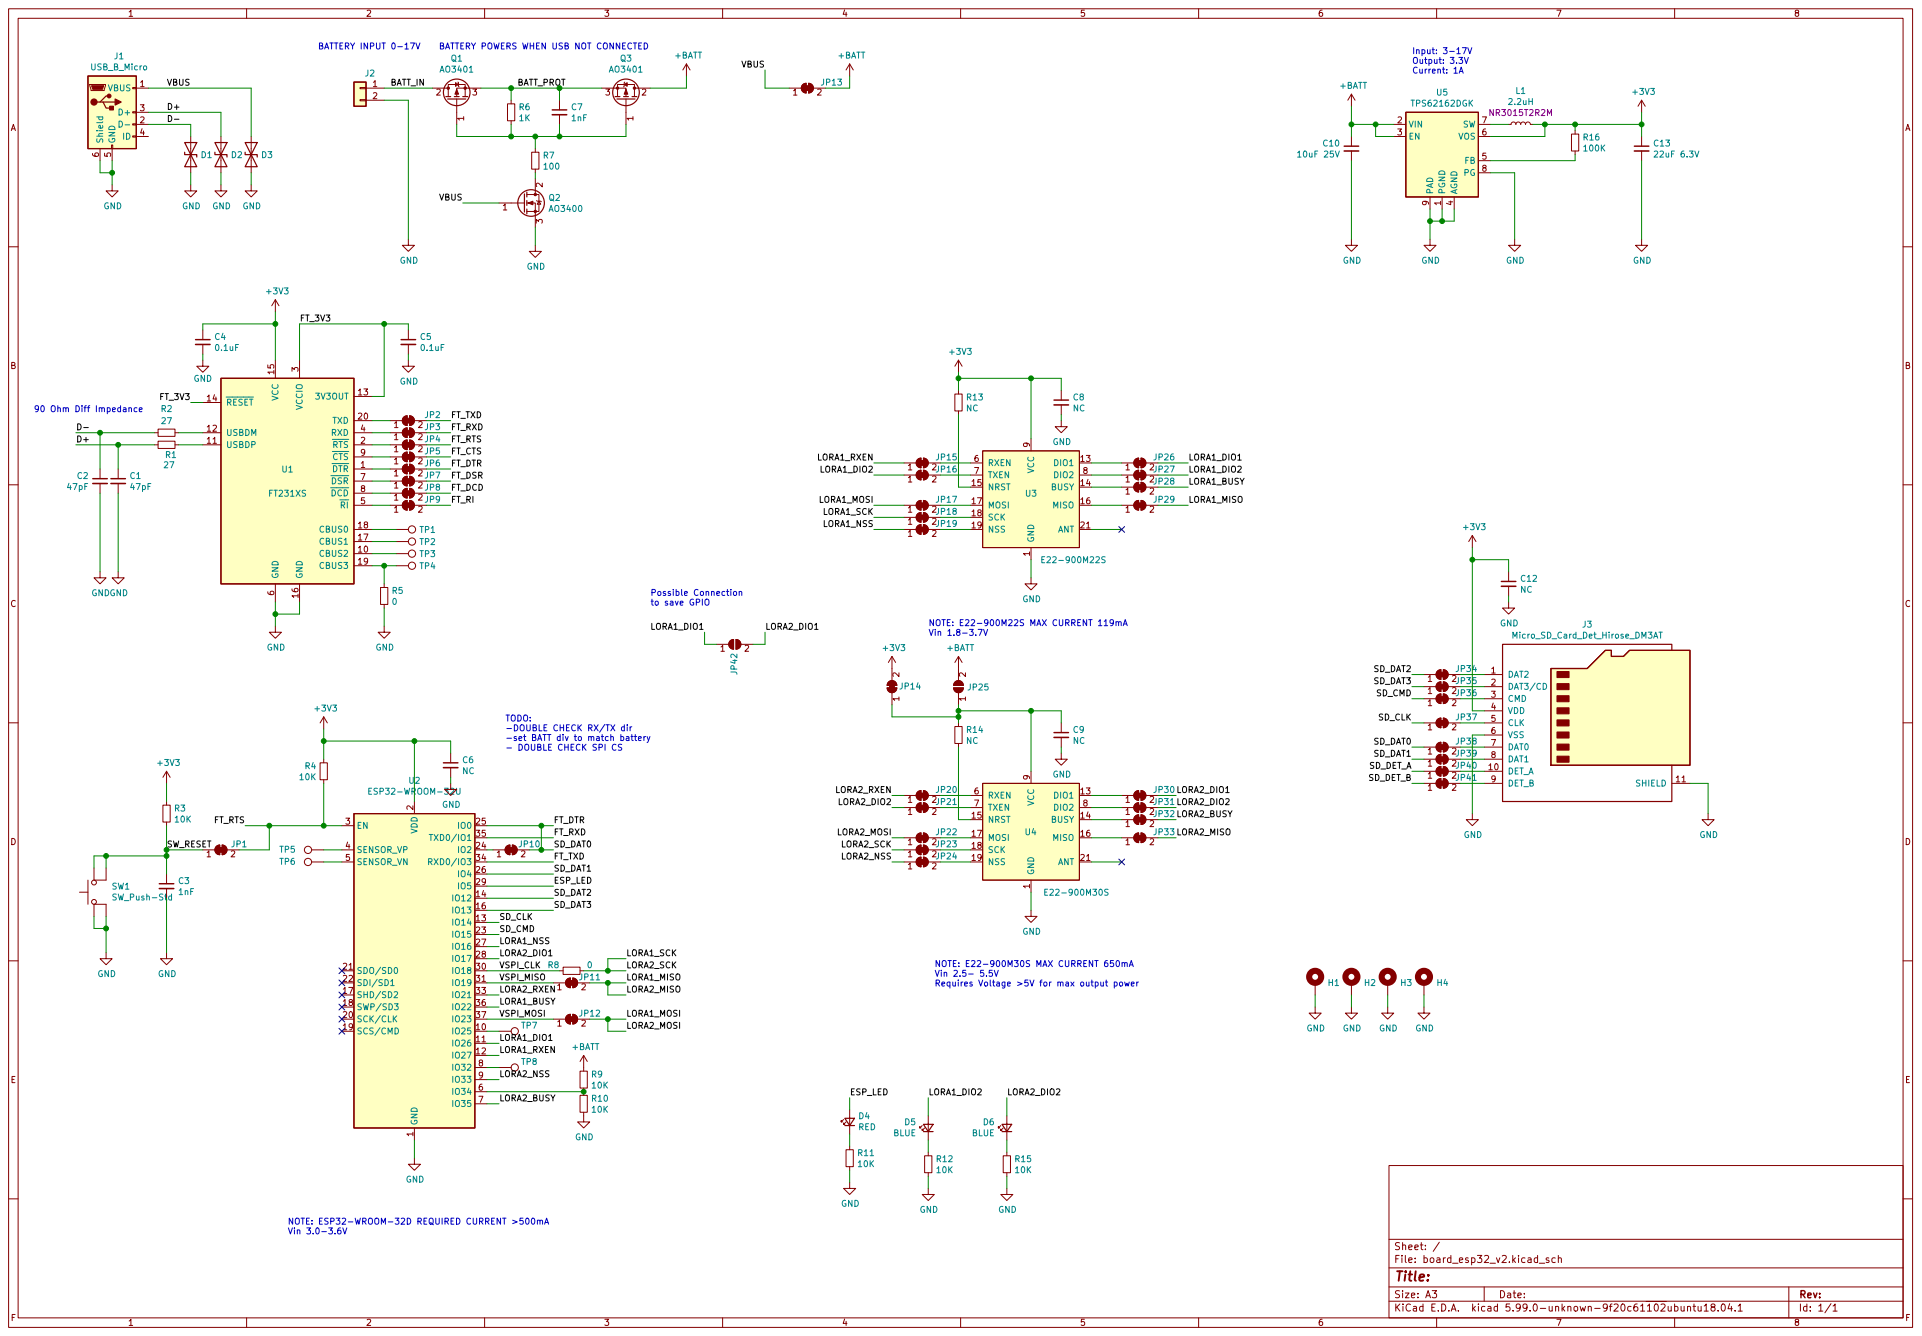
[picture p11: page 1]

BATT_PROT BATTERY POWERS WHEN USB NOT CONNECTED

4 FB 5 VOS 6 SW 7 PG 8 PAD

6 DSR 7 DCD 8 CTS 9 U1 FT231XS C8 NC

1 DIO1 13 BUSY 14 NRST 15 MISO 16 MOSI 17 SCK 18 NSS 19 ANT 21 RXEN 6 TXEN 7 DIO2 VCC 8

JP35
JP36

Vin 2.5- 5.5V Requires Voltage >5V for max output power TODO: -DOUBLE CHECK RX/TX dir

- DOUBLE CHECK SPI CS NOTE: ESP32-WROOM-32D REQUIRED CURRENT >500mA

-set BATT div to match battery

JP40
JP41

2 SCK/CLK 20 SDO/SD0 21 SDI/SD1 22

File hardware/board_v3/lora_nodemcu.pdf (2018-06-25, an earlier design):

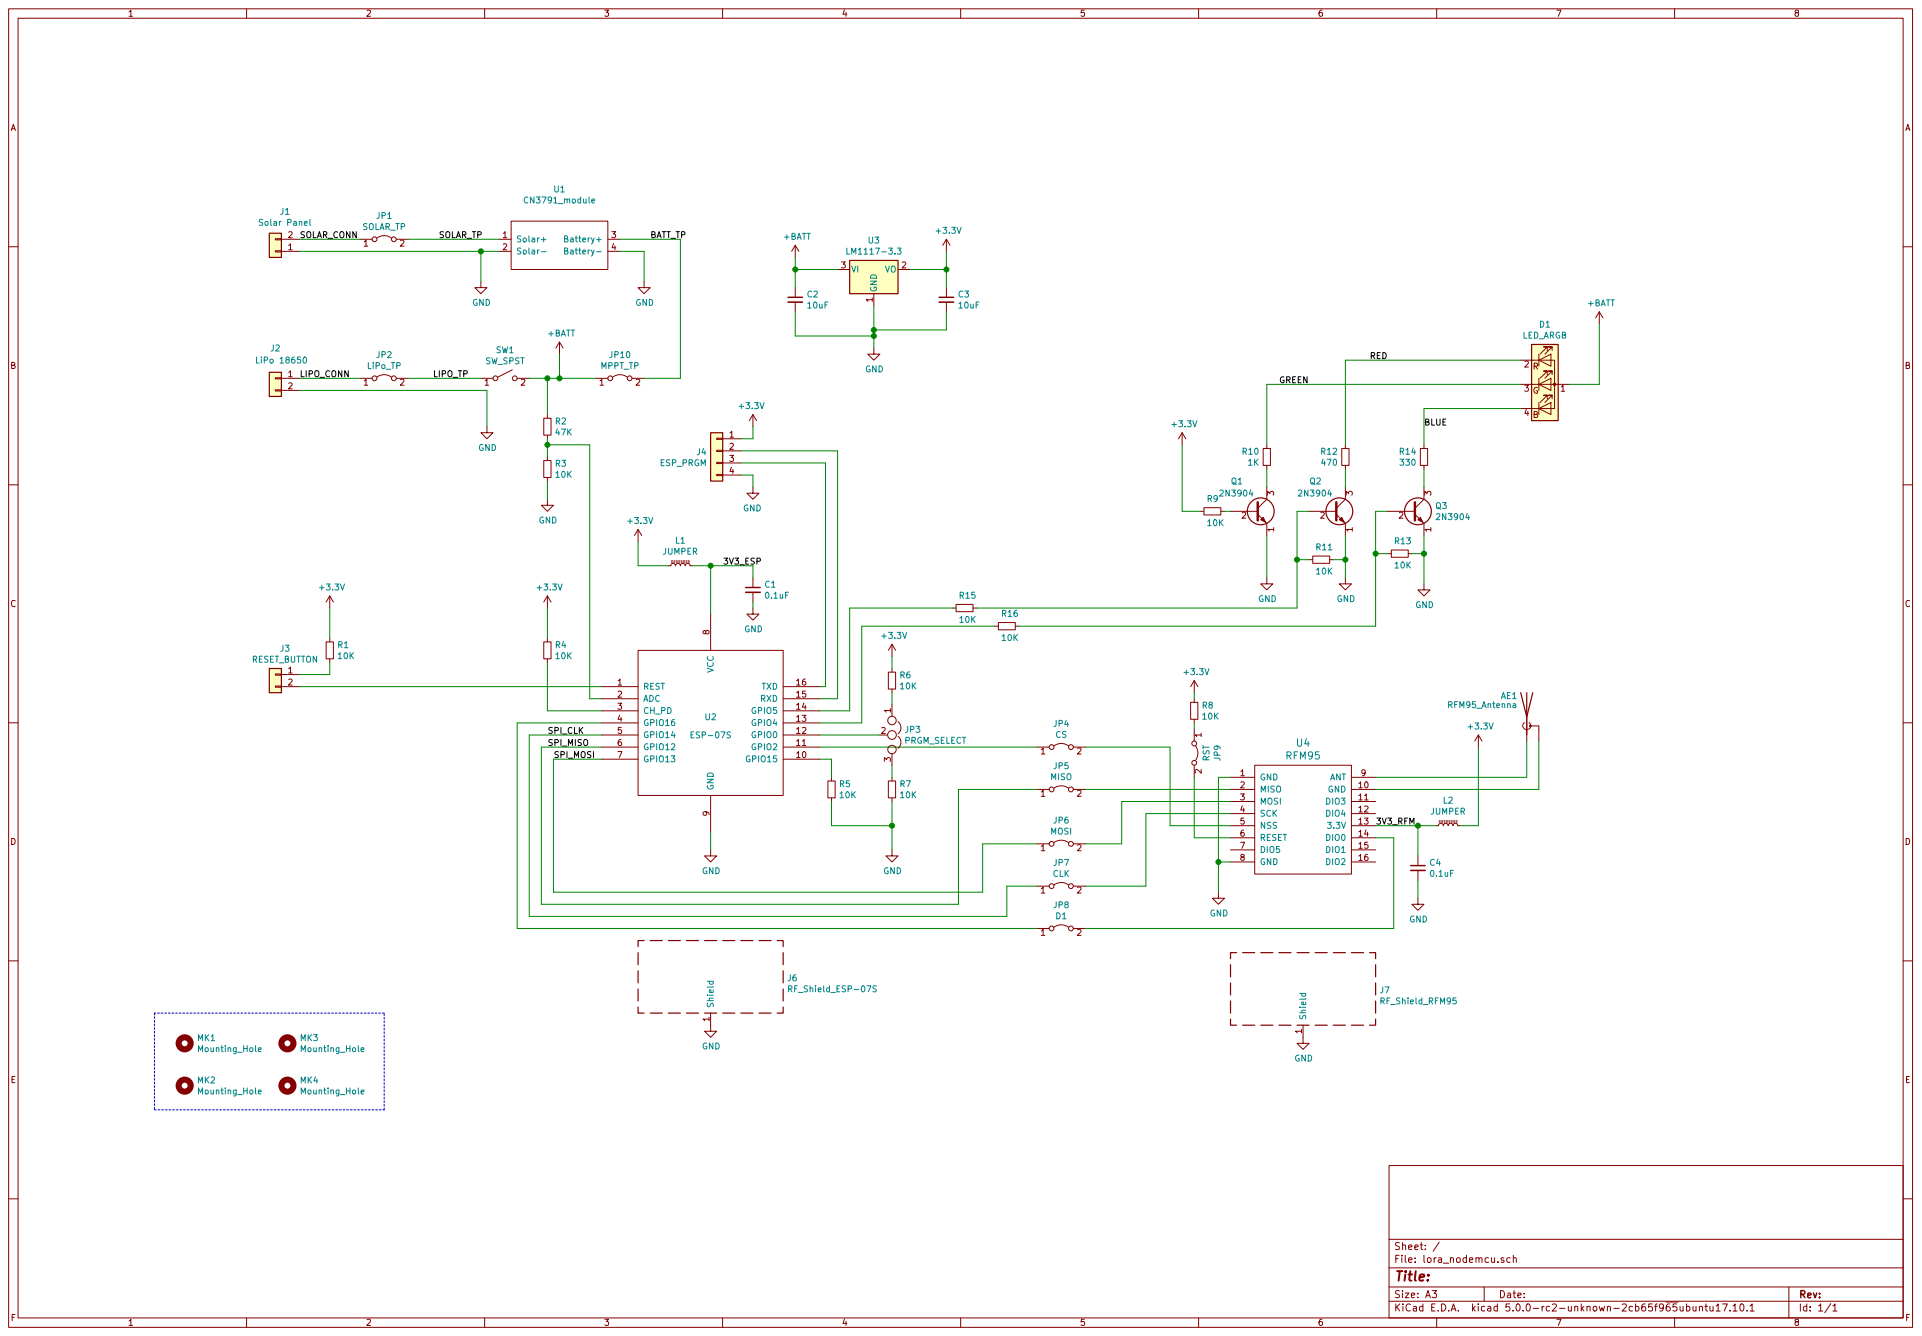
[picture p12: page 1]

9 GPIO15 10 GPIO2 11 GPIO0 12 GPIO4 13 GPIO5 14 RXD 15 TXD 16 U2 ESP-07S Shield

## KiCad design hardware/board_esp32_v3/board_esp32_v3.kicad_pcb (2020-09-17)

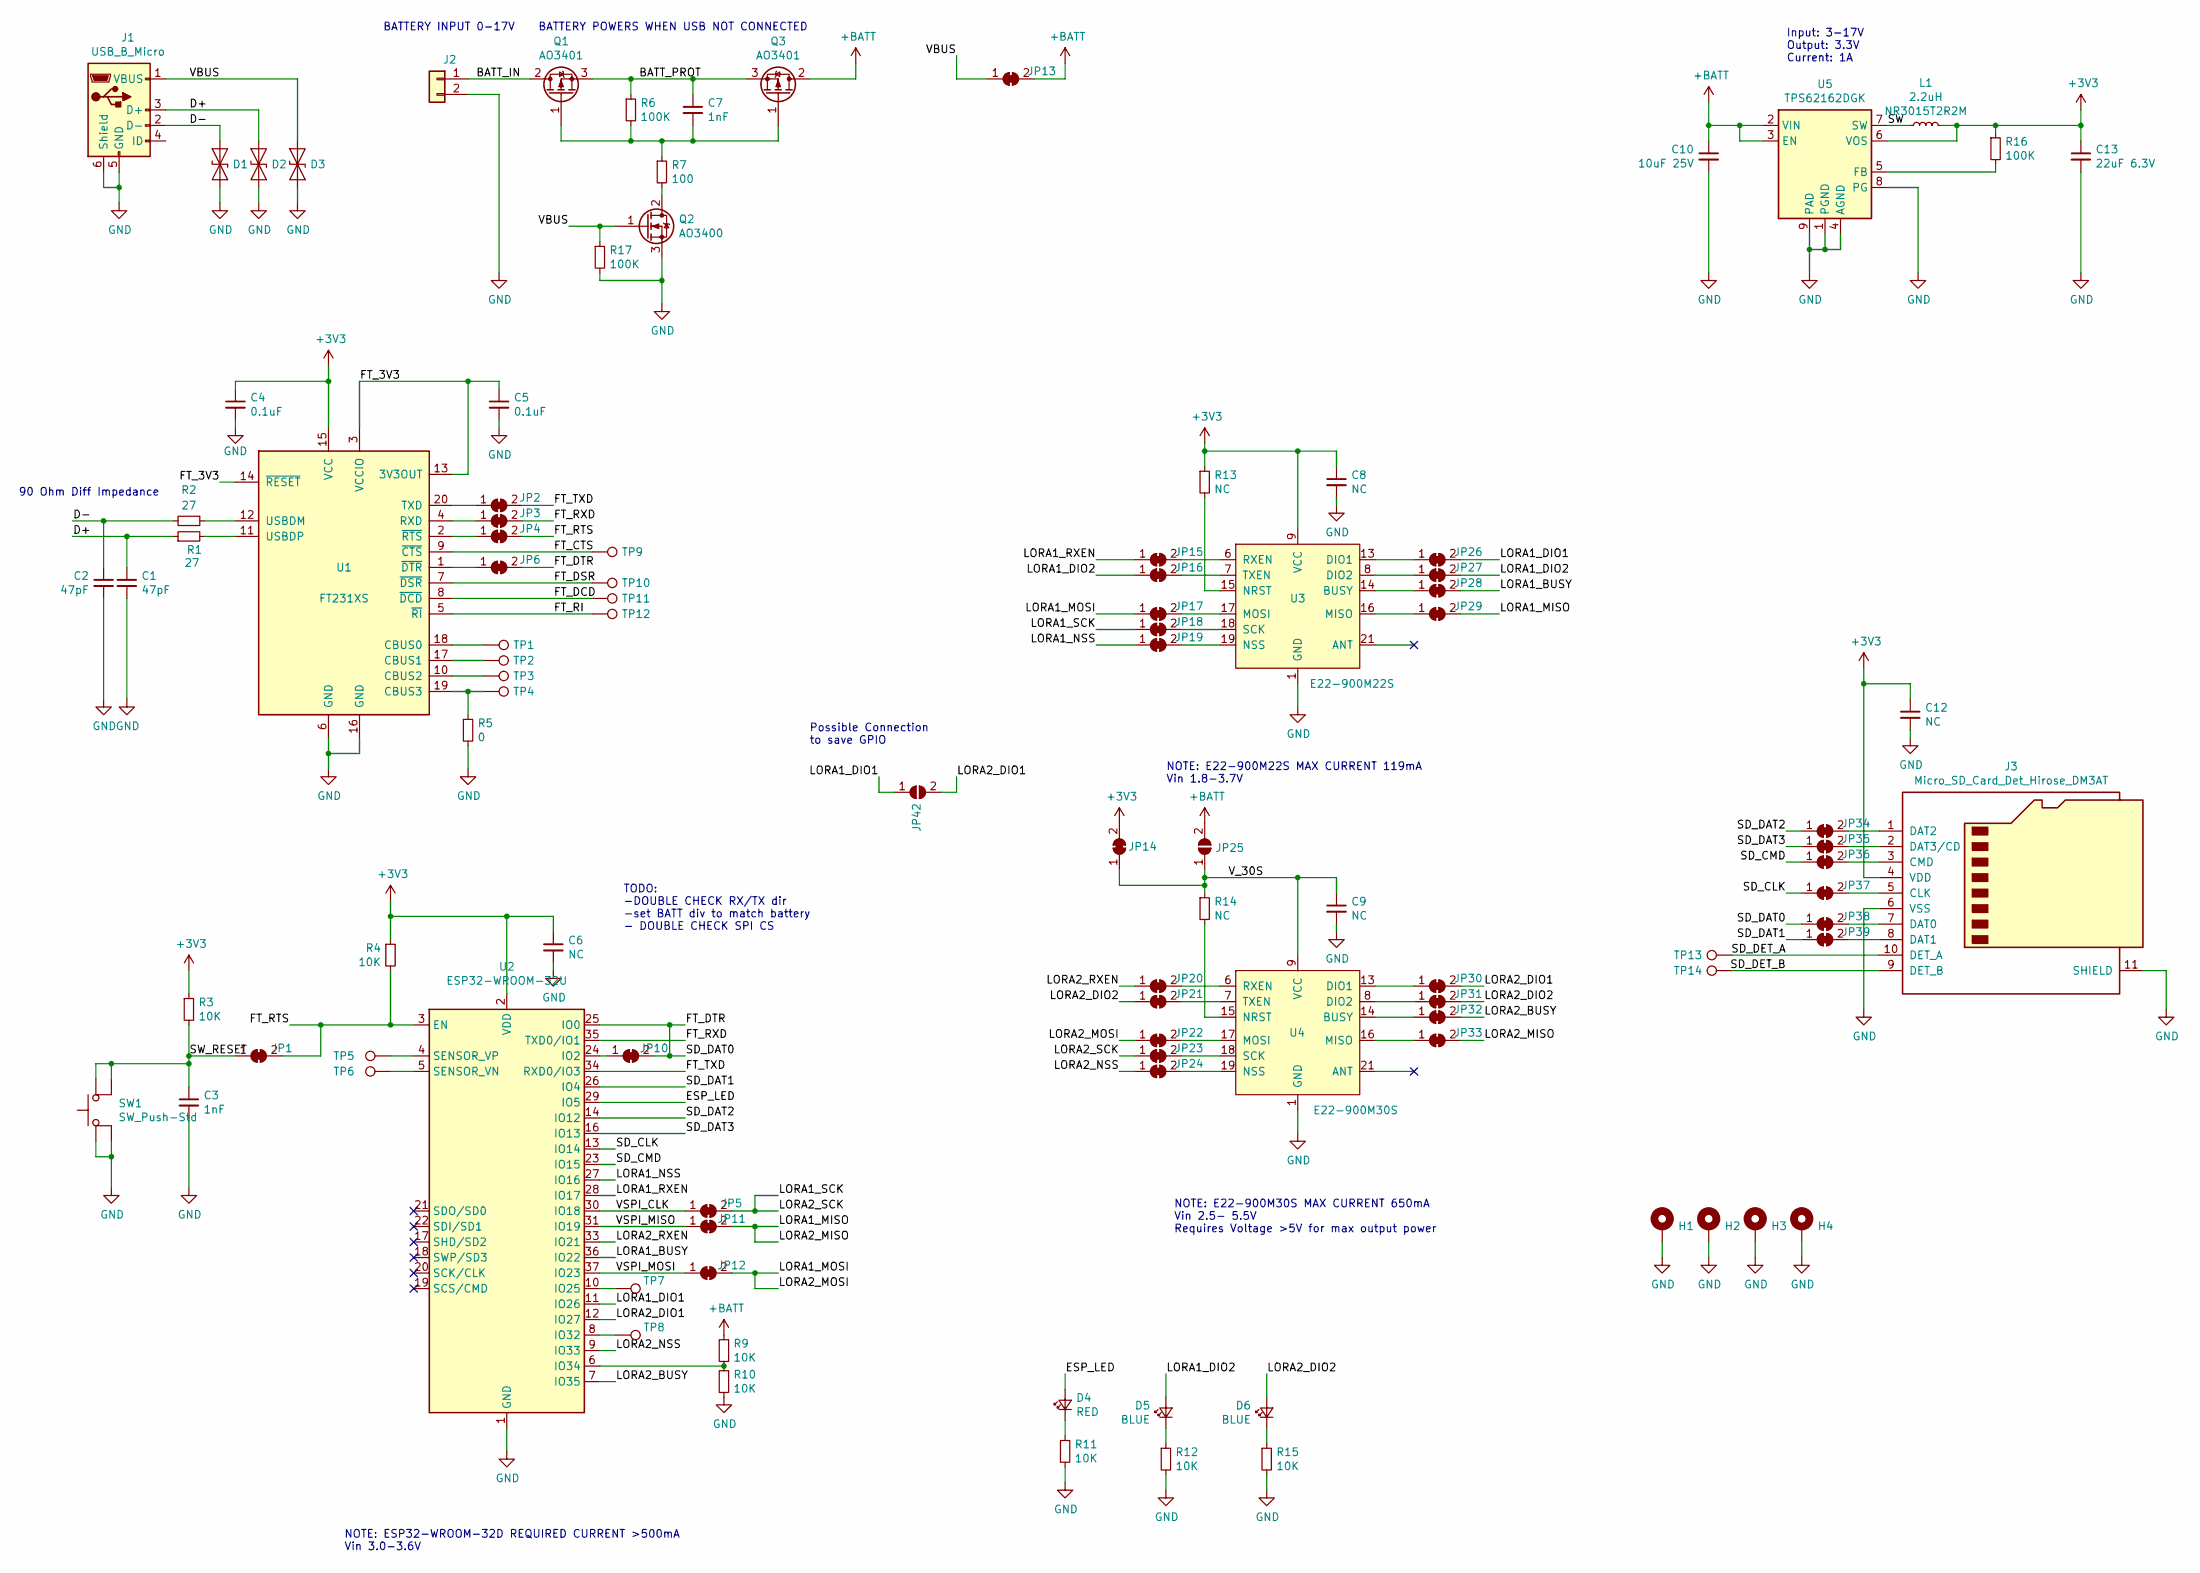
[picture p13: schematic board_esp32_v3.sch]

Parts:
C1, C2: 47pF; C_0402_1005Metric
C3, C7: 1nF; C_0402_1005Metric
C4, C5: 0.1uF; C_0402_1005Metric
C6, C8, C9, C12: NC; C_0402_1005Metric
C10: 10uF 25V; C_0805_2012Metric
C13: 22uF 6.3V; C_0805_2012Metric
D1, D2, D3: TPD1E10B06; D_0402_1005Metric
D4: RED; LED_0603_1608Metric
D5, D6: BLUE; LED_0603_1608Metric
H1, H2, H3, H4: MountingHole_Pad; MountingHole_2.2mm_M2_ISO7380_Pad
J1: USB_B_Micro; USB_Micro-B_GCT_USB3076-30-A_handsolder
J2: Conn_01x02; PinHeader_1x02_P2.54mm_Vertical
J3: Micro_SD_Card_Det_Hirose_DM3AT; microSD_HC_Hirose_DM3D-SF
JP1, JP2, JP3, JP4, JP5, JP6, JP10, JP11, JP12, JP13, JP14, JP15, JP16, JP17, JP18, JP19, JP20, JP21, JP22, JP23, JP24, JP26, JP27, JP28, JP29, JP30, JP31, JP32, JP33, JP34, JP35, JP36, JP37, JP38, JP39: SolderJumper_2_Bridged; SolderJumper-2_P1.3mm_Bridged_RoundedPad1.0x1.5mm
JP25, JP42: SolderJumper_2_Open; SolderJumper-2_P1.3mm_Open_RoundedPad1.0x1.5mm
L1: 2.2uH; L_Taiyo-Yuden_NR-30xx_HandSoldering; MPN NR3015T2R2M
Q1, Q3: AO3401; SOT-23
Q2: AO3400; SOT-23
R1, R2: 27; R_0402_1005Metric
R3, R4, R9, R10, R11, R12, R15: 10K; R_0402_1005Metric
R5: 0; R_0402_1005Metric
R6, R16, R17: 100K; R_0402_1005Metric
R7: 100; R_0402_1005Metric
R13, R14: NC; R_0402_1005Metric
SW1: SW_Push-Std; SW_PUSH_6mm
TP1, TP2, TP3, TP4, TP9, TP10, TP11, TP12, TP13, TP14: TestPoint; TestPoint_Pad_D1.0mm
TP5, TP6, TP7, TP8: TP_HOLE; TestPoint_Pad_D1.0mm
U1: FT231XS; SSOP-20_3.9x8.7mm_P0.635mm
U2: ESP32-WROOM-32U
U3: E22-900M22S; E22_900T22S
U4: E22-900M30S
U5: TPS62162DGK; TPS62162DSGT

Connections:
+3V3: C4.1, C6.1, C8.1, C12.1, C13.1, J3.4 (VDD), JP14.2 (B), L1.2, R3.1, R4.1, R13.1, R16.1, U1.15 (VCC), U2.2 (VDD), U3.9 (VCC), U5.6 (VOS)
+BATT: C10.1, JP13.2 (B), JP25.2 (B), Q3.2 (D), R9.1, U5.2 (VIN), U5.3 (EN)
/BATT_IN: J2.1, Q1.2 (D)
/BATT_PROT: C7.1, Q1.3 (S), Q3.3 (S), R6.1
/D+: C1.1, D2.1 (A1), J1.3 (D+), R1.1
/D-: C2.1, D1.1 (A1), J1.2 (D-), R2.2
/ESP_LED: D4.2 (A), U2.29 (IO5)
/FT_3V3: C5.1, U1.3 (VCCIO), U1.13 (3V3OUT), U1.14 (~RESET)
/FT_CTS: TP9.1, U1.9 (~CTS)
/FT_DCD: TP11.1, U1.8 (~DCD)
/FT_DSR: TP10.1, U1.7 (~DSR)
/FT_DTR: JP6.2 (B), JP10.2 (B), JP38.1 (A), U2.25 (IO0)
/FT_RI: TP12.1, U1.5 (~RI)
/FT_RTS: JP1.2 (B), JP4.2 (B), R4.2, U2.3 (EN)
/FT_RXD: JP3.2 (B), U2.35 (TXD0/IO1)
/FT_TXD: JP2.2 (B), U2.34 (RXD0/IO3)
/LORA1_BUSY: JP28.2 (B), U2.36 (IO22)
/LORA1_DIO1: JP26.2 (B), JP42.1 (A), U2.11 (IO26)
/LORA1_DIO2: D5.2 (A), JP16.1 (A), JP27.2 (B)
/LORA1_MISO: JP11.2 (B), JP29.2 (B), JP33.2 (B)
/LORA1_MOSI: JP12.2 (B), JP17.1 (A), JP22.1 (A)
/LORA1_NSS: JP19.1 (A), U2.27 (IO16)
/LORA1_RXEN: JP15.1 (A), U2.28 (IO17)
/LORA1_SCK: JP5.2 (B), JP18.1 (A), JP23.1 (A)
/LORA2_BUSY: JP32.2 (B), U2.7 (IO35)
/LORA2_DIO1: JP30.2 (B), JP42.2 (B), U2.12 (IO27)
/LORA2_DIO2: D6.2 (A), JP21.1 (A), JP31.2 (B)
/LORA2_NSS: JP24.1 (A), U2.9 (IO33)
/LORA2_RXEN: JP20.1 (A), U2.33 (IO21)
/SD_CLK: JP37.1 (A), U2.13 (IO14)
/SD_CMD: JP36.1 (A), U2.23 (IO15)
/SD_DAT1: JP39.1 (A), U2.26 (IO4)
/SD_DAT2: JP34.1 (A), U2.14 (IO12)
/SD_DAT3: JP35.1 (A), U2.16 (IO13)
/SD_DET_A: J3.10 (DET_A), TP13.1
/SD_DET_B: J3.9 (DET_B), TP14.1
/SW: L1.1, U5.7 (SW)
/SW_RESET: C3.1, JP1.1 (A), R3.2, SW1.2
/VBUS: D3.1 (A1), J1.1 (VBUS), JP13.1 (A), Q2.1 (G), R17.1
/VSPI_CLK: JP5.1 (A), U2.30 (IO18)
/VSPI_MISO: JP11.1 (A), U2.31 (IO19)
/VSPI_MOSI: JP12.1 (A), U2.37 (IO23)
/V_30S: C9.1, JP14.1 (A), JP25.1 (A), R14.1, U4.9 (VCC), U4.10 (VCC)
GND: C1.2, C2.2, C3.2, C4.2, C5.2, C6.2, C8.2, C9.2, C10.2, C12.2, C13.2, D1.2 (A2), D2.2 (A2), D3.2 (A2), H1.1, H2.1, H3.1, H4.1, J1.5 (GND), J1.6 (Shield), J2.2, J3.6 (VSS), J3.11 (SHIELD), Q2.3 (S), R5.2, R10.2, R11.2, R12.2, R15.2, R17.2, SW1.1, U1.6 (GND), U1.16 (GND), U2.1 (GND), U2.15 (GND), U2.38 (GND), U2.39 (GND), U3.1 (GND), U3.2 (GND), U3.3 (GND), U3.4 (GND), U3.5 (GND), U3.10 (GND), U3.11 (GND), U3.12 (GND), U3.20 (GND), U3.22 (GND), U4.1 (GND), U4.2 (GND), U4.3 (GND), U4.4 (GND), U4.5 (GND), U4.11 (GND), U4.12 (GND), U4.20 (GND), U4.22 (GND), U5.1 (PGND), U5.4 (AGND), U5.8 (PG), U5.9 (PAD)
unnamed: C7.2, Q1.1 (G), Q3.1 (G), R6.2, R7.1
unnamed: D4.1 (K), R11.1
unnamed: D5.1 (K), R12.1
unnamed: D6.1 (K), R15.1
unnamed: J3.1 (DAT2), JP34.2 (B)
unnamed: J3.2 (DAT3/CD), JP35.2 (B)
unnamed: J3.3 (CMD), JP36.2 (B)
unnamed: J3.5 (CLK), JP37.2 (B)
unnamed: J3.7 (DAT0), JP38.2 (B)
unnamed: J3.8 (DAT1), JP39.2 (B)
unnamed: JP2.1 (A), U1.20 (TXD)
unnamed: JP3.1 (A), U1.4 (RXD)
unnamed: JP4.1 (A), U1.2 (~RTS)
unnamed: JP6.1 (A), U1.1 (~DTR)
unnamed: JP10.1 (A), U2.24 (IO2)
unnamed: JP15.2 (B), U3.6 (RXEN)
unnamed: JP16.2 (B), U3.7 (TXEN)
unnamed: JP17.2 (B), U3.17 (MOSI)
unnamed: JP18.2 (B), U3.18 (SCK)
unnamed: JP19.2 (B), U3.19 (NSS)
unnamed: JP20.2 (B), U4.6 (RXEN)
unnamed: JP21.2 (B), U4.7 (TXEN)
unnamed: JP22.2 (B), U4.17 (MOSI)
unnamed: JP23.2 (B), U4.18 (SCK)
unnamed: JP24.2 (B), U4.19 (NSS)
unnamed: JP26.1 (A), U3.13 (DIO1)
unnamed: JP27.1 (A), U3.8 (DIO2)
unnamed: JP28.1 (A), U3.14 (BUSY)
unnamed: JP29.1 (A), U3.16 (MISO)
unnamed: JP30.1 (A), U4.13 (DIO1)
unnamed: JP31.1 (A), U4.8 (DIO2)
unnamed: JP32.1 (A), U4.14 (BUSY)
unnamed: JP33.1 (A), U4.16 (MISO)
unnamed: Q2.2 (D), R7.2
unnamed: R1.2, U1.11 (USBDP)
unnamed: R2.1, U1.12 (USBDM)
unnamed: R5.1, TP4.1, U1.19 (CBUS3)
unnamed: R9.2, R10.1, U2.6 (IO34)
unnamed: R13.2, U3.15 (NRST)
unnamed: R14.2, U4.15 (NRST)
unnamed: R16.2, U5.5 (FB)
unnamed: TP1.1, U1.18 (CBUS0)
unnamed: TP2.1, U1.17 (CBUS1)
unnamed: TP3.1, U1.10 (CBUS2)
unnamed: TP5.1, U2.4 (SENSOR_VP)
unnamed: TP6.1, U2.5 (SENSOR_VN)
unnamed: TP7.1, U2.10 (IO25)
unnamed: TP8.1, U2.8 (IO32)

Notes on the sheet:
90 Ohm Diff Impedance
NOTE: ESP32-WROOM-32D REQUIRED CURRENT >500mA Vin 3.0-3.6V
BATTERY INPUT 0-17V
BATTERY POWERS WHEN USB NOT CONNECTED
TODO: -DOUBLE CHECK RX/TX dir -set BATT div to match battery - DOUBLE CHECK SPI CS
Possible Connection to save GPIO
NOTE: E22-900M22S MAX CURRENT 119mA Vin 1.8-3.7V
NOTE: E22-900M30S MAX CURRENT 650mA Vin 2.5- 5.5V Requires Voltage >5V for max output power
Input: 3-17V Output: 3.3V Current: 1A

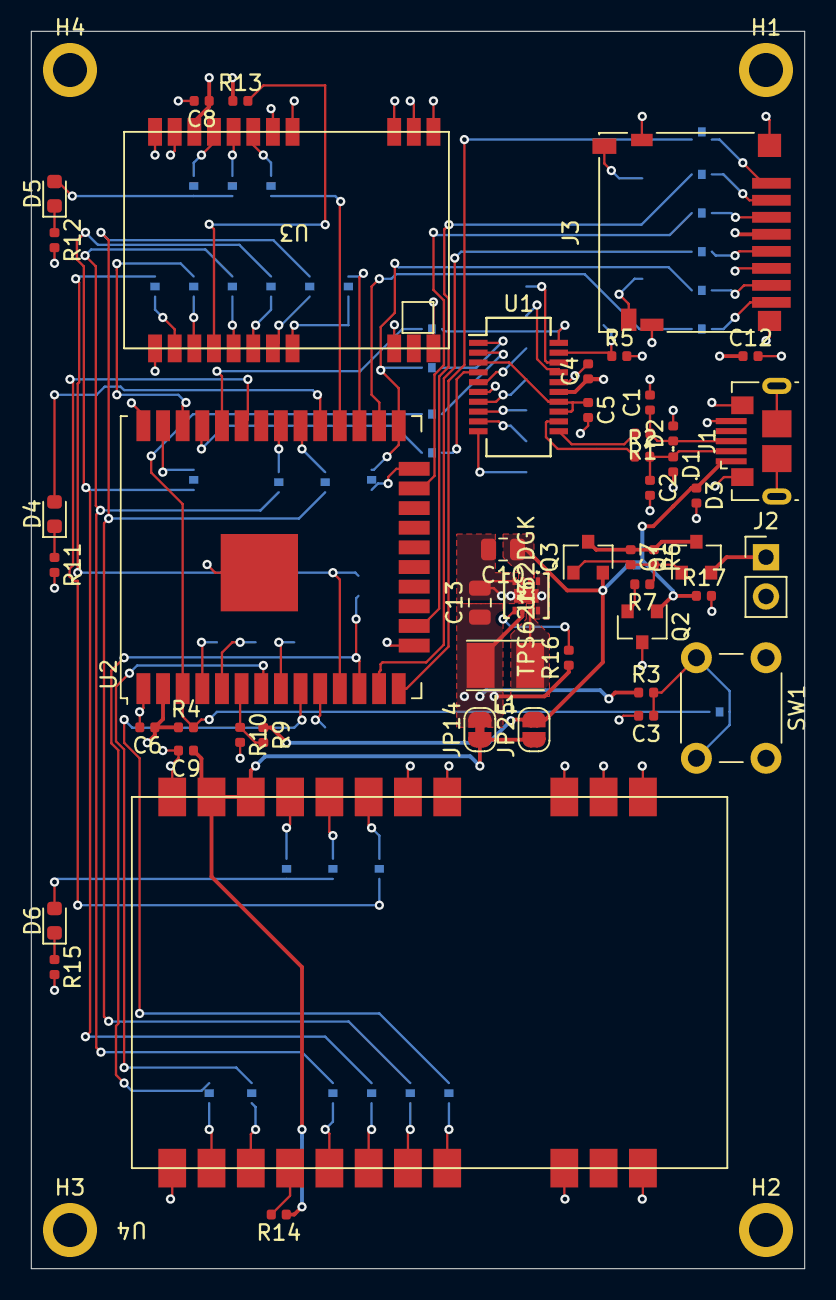
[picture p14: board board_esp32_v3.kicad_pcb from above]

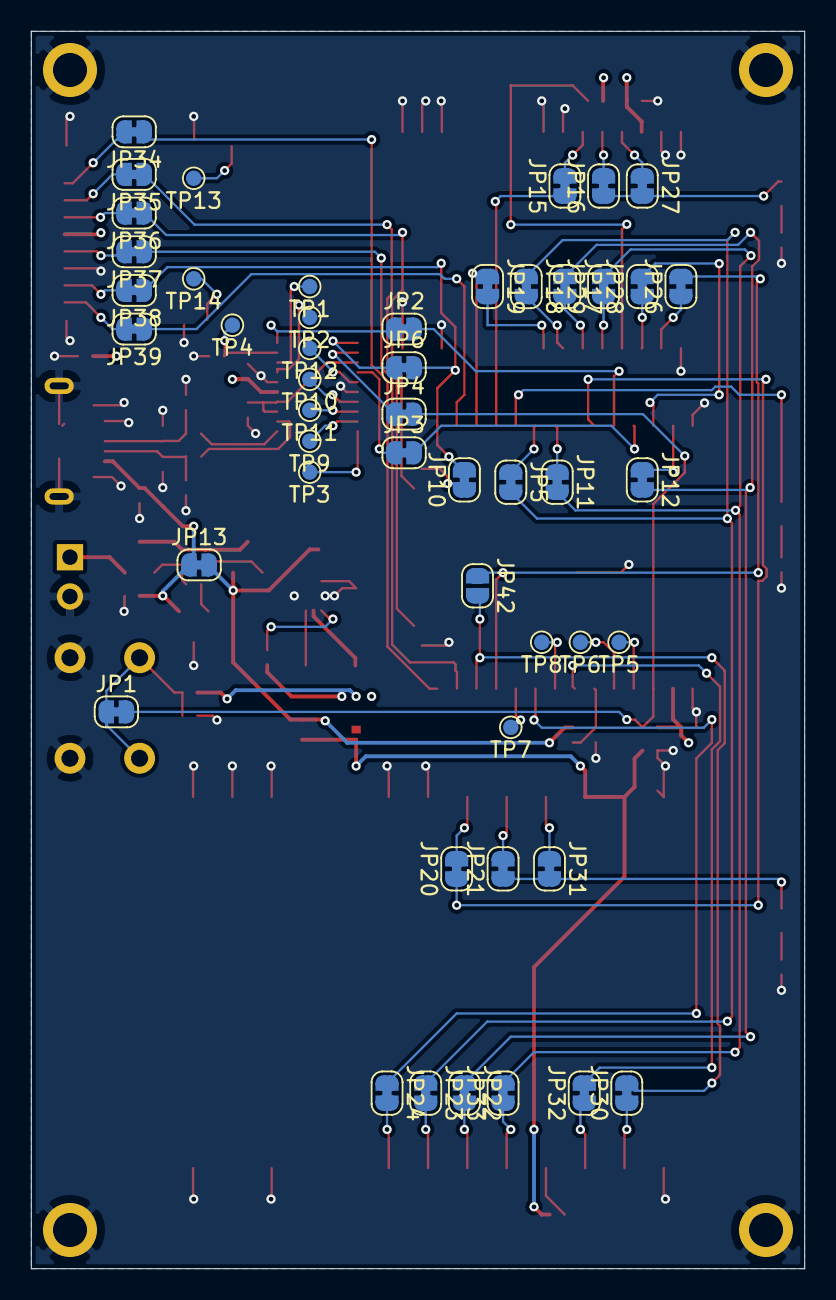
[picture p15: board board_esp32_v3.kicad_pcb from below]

Board: 4 copper layers, 50.0 x 80.0 mm, 102 parts (49 on the bottom side), 92 nets.

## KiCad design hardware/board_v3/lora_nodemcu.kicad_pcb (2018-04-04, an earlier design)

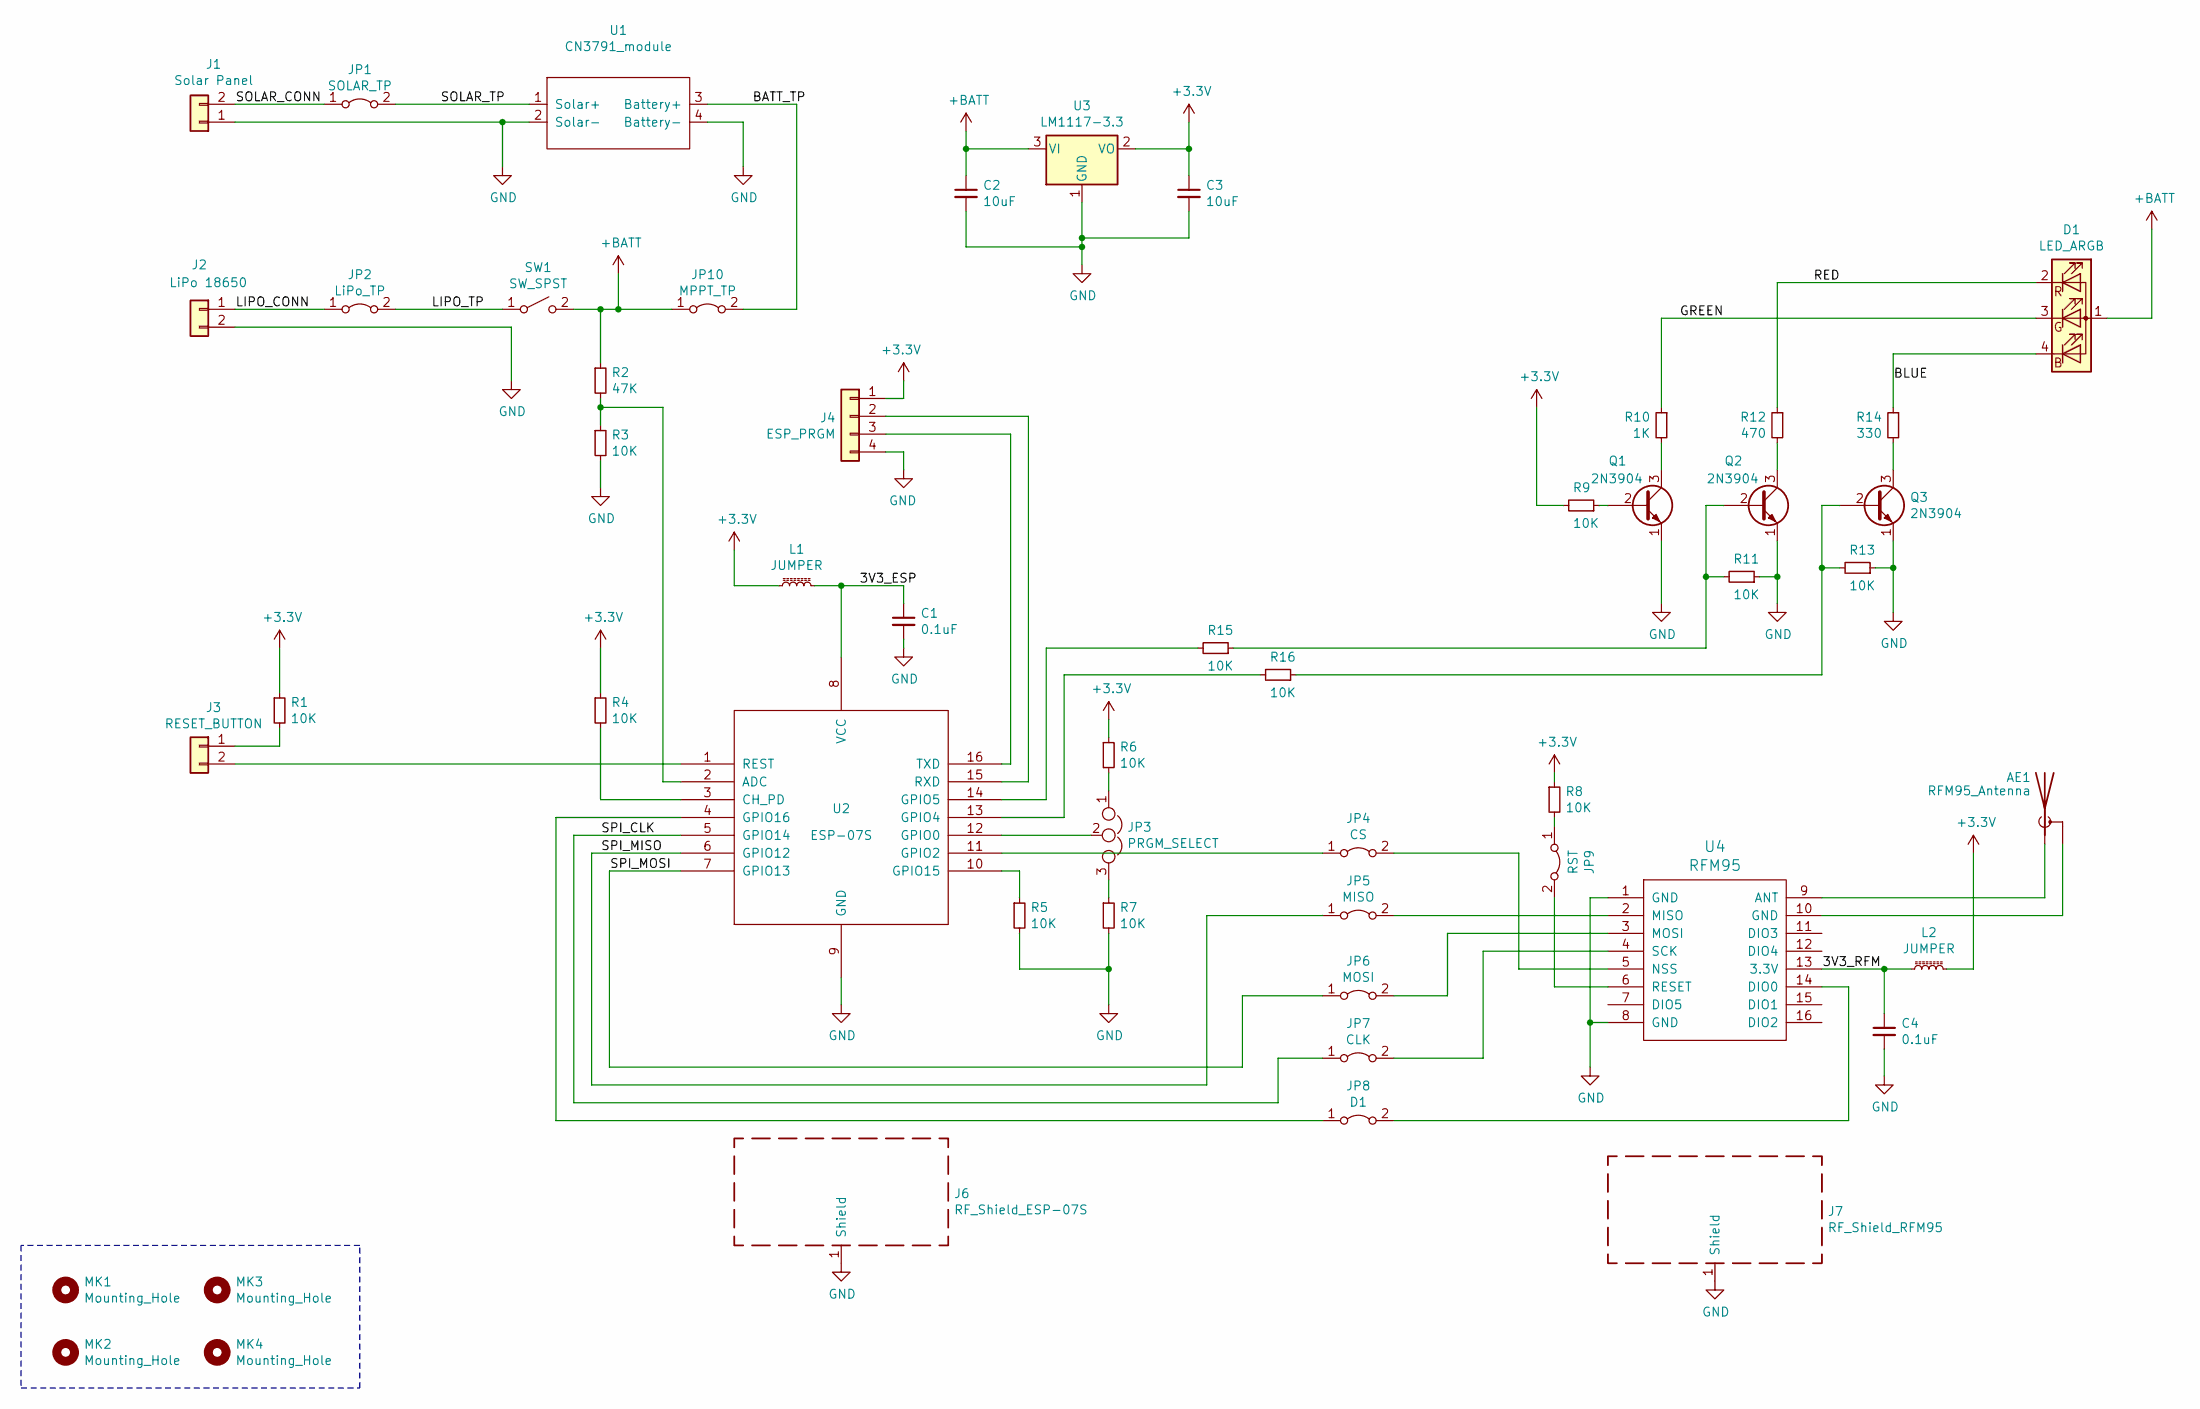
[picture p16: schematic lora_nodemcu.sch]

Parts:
AE1: RFM95_Antenna; U.FL_Hirose_U.FL-R-SMT-1_Vertical
C1, C4: 0.1uF; C_0805_2012Metric_Pad1.15x1.50mm_HandSolder
C2, C3: 10uF; C_0805_2012Metric_Pad1.15x1.50mm_HandSolder
D1: LED_ARGB; LED_D5.0mm-4
J1: Solar Panel; solar_panel_conn
J2: LiPo 18650; BatteryHolder_MPD_BH-18650-PC2
J3: RESET_BUTTON; PhoenixContact_MCV_1,5_2-G-5.08_1x02_P5.08mm_Vertical
J4: ESP_PRGM; PinHeader_1x04_P2.54mm_Vertical
J6: RF_Shield_ESP-07S; Wuerth_36103305_30x30mm
J7: RF_Shield_RFM95; Wuerth_36103305_30x30mm
JP1: SOLAR_TP; SolderJumper-2_P1.3mm_Bridged_Pad1.0x1.5mm
JP2: LiPo_TP; SolderJumper-2_P1.3mm_Bridged_Pad1.0x1.5mm
JP3: PRGM_SELECT; PinHeader_1x03_P2.54mm_Vertical
JP4: CS; SolderJumper-2_P1.3mm_Bridged_Pad1.0x1.5mm
JP5: MISO; SolderJumper-2_P1.3mm_Bridged_Pad1.0x1.5mm
JP6: MOSI; SolderJumper-2_P1.3mm_Bridged_Pad1.0x1.5mm
JP7: CLK; SolderJumper-2_P1.3mm_Bridged_Pad1.0x1.5mm
JP8: D1; SolderJumper-2_P1.3mm_Bridged_Pad1.0x1.5mm
JP9: RST; SolderJumper-2_P1.3mm_Bridged_Pad1.0x1.5mm
JP10: MPPT_TP; SolderJumper-2_P1.3mm_Bridged_Pad1.0x1.5mm
L1, L2: JUMPER; L_0805_2012Metric_Pad1.15x1.50mm_HandSolder
MK1, MK2, MK3, MK4: Mounting_Hole; MountingHole_3.2mm_M3
Q1, Q2, Q3: 2N3904; SOT-23_Handsoldering
R1, R3, R4, R5, R6, R7, R8, R9, R11, R13, R15, R16: 10K; R_0805_2012Metric_Pad1.15x1.50mm_HandSolder
R2: 47K; R_0805_2012Metric_Pad1.15x1.50mm_HandSolder
R10: 1K; R_0805_2012Metric_Pad1.15x1.50mm_HandSolder
R12: 470; R_0805_2012Metric_Pad1.15x1.50mm_HandSolder
R14: 330; R_0805_2012Metric_Pad1.15x1.50mm_HandSolder
SW1: SW_SPST; PhoenixContact_MCV_1,5_2-G-5.08_1x02_P5.08mm_Vertical
U1: CN3791_module
U2: ESP-07S
U3: LM1117-3.3; SOT-223-3_TabPin2
U4: RFM95

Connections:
+3V3: C3.1, J4.1, L1.1, L2.2, R1.1, R4.1, R6.1, R8.1, R9.2, U3.2 (VO)
+BATT: C2.1, D1.1 (A), JP10.1 (A), R2.1, SW1.2 (B), U3.3 (VI)
/3V3_ESP: C1.1, L1.2, U2.8 (VCC)
/3V3_RFM: C4.1, L2.1, U4.13 (3.3V)
/BATT_TP: JP10.2 (B), U1.3 (Battery+)
/BLUE: D1.4 (BK), R14.1
/GREEN: D1.3 (GK), R10.1
/LIPO_CONN: J2.1, JP2.1 (A)
/LIPO_TP: JP2.2 (B), SW1.1 (A)
/RED: D1.2 (RK), R12.1
/SOLAR_CONN: J1.2, JP1.1 (A)
/SOLAR_TP: JP1.2 (B), U1.1 (Solar+)
/SPI_CLK: JP7.1 (A), U2.5 (GPIO14)
/SPI_MISO: JP5.1 (A), U2.6 (GPIO12)
/SPI_MOSI: JP6.1 (A), U2.7 (GPIO13)
GND: C1.2, C2.2, C3.2, C4.2, J1.1, J2.2, J4.4, J6.1, J7.1, Q1.1 (E), Q2.1 (E), Q3.1 (E), R3.2, R5.2, R7.2, R11.1, R13.1, U1.2 (Solar-), U1.4 (Battery-), U2.9 (GND), U3.1 (GND), U4.1 (GND), U4.8 (GND)
unnamed: AE1.1 (A), U4.9 (ANT)
unnamed: AE1.2 (Shield), U4.10 (GND)
unnamed: J3.1, R1.2
unnamed: J3.2, U2.1 (REST)
unnamed: J4.2, U2.15 (RXD)
unnamed: J4.3, U2.16 (TXD)
unnamed: JP3.1, R6.2
unnamed: JP3.2, U2.12 (GPIO0)
unnamed: JP3.3, R7.1
unnamed: JP4.1 (A), U2.11 (GPIO2)
unnamed: JP4.2 (B), U4.5 (NSS)
unnamed: JP5.2 (B), U4.2 (MISO)
unnamed: JP6.2 (B), U4.3 (MOSI)
unnamed: JP7.2 (B), U4.4 (SCK)
unnamed: JP8.1 (A), U2.4 (GPIO16)
unnamed: JP8.2 (B), U4.14 (DIO0)
unnamed: JP9.1 (A), R8.2
unnamed: JP9.2 (B), U4.6 (RESET)
unnamed: Q1.2 (B), R9.1
unnamed: Q1.3 (C), R10.2
unnamed: Q2.2 (B), R11.2, R15.1
unnamed: Q2.3 (C), R12.2
unnamed: Q3.2 (B), R13.2, R16.1
unnamed: Q3.3 (C), R14.2
unnamed: R2.2, R3.1, U2.2 (ADC)
unnamed: R4.2, U2.3 (CH_PD)
unnamed: R5.1, U2.10 (GPIO15)
unnamed: R15.2, U2.14 (GPIO5)
unnamed: R16.2, U2.13 (GPIO4)

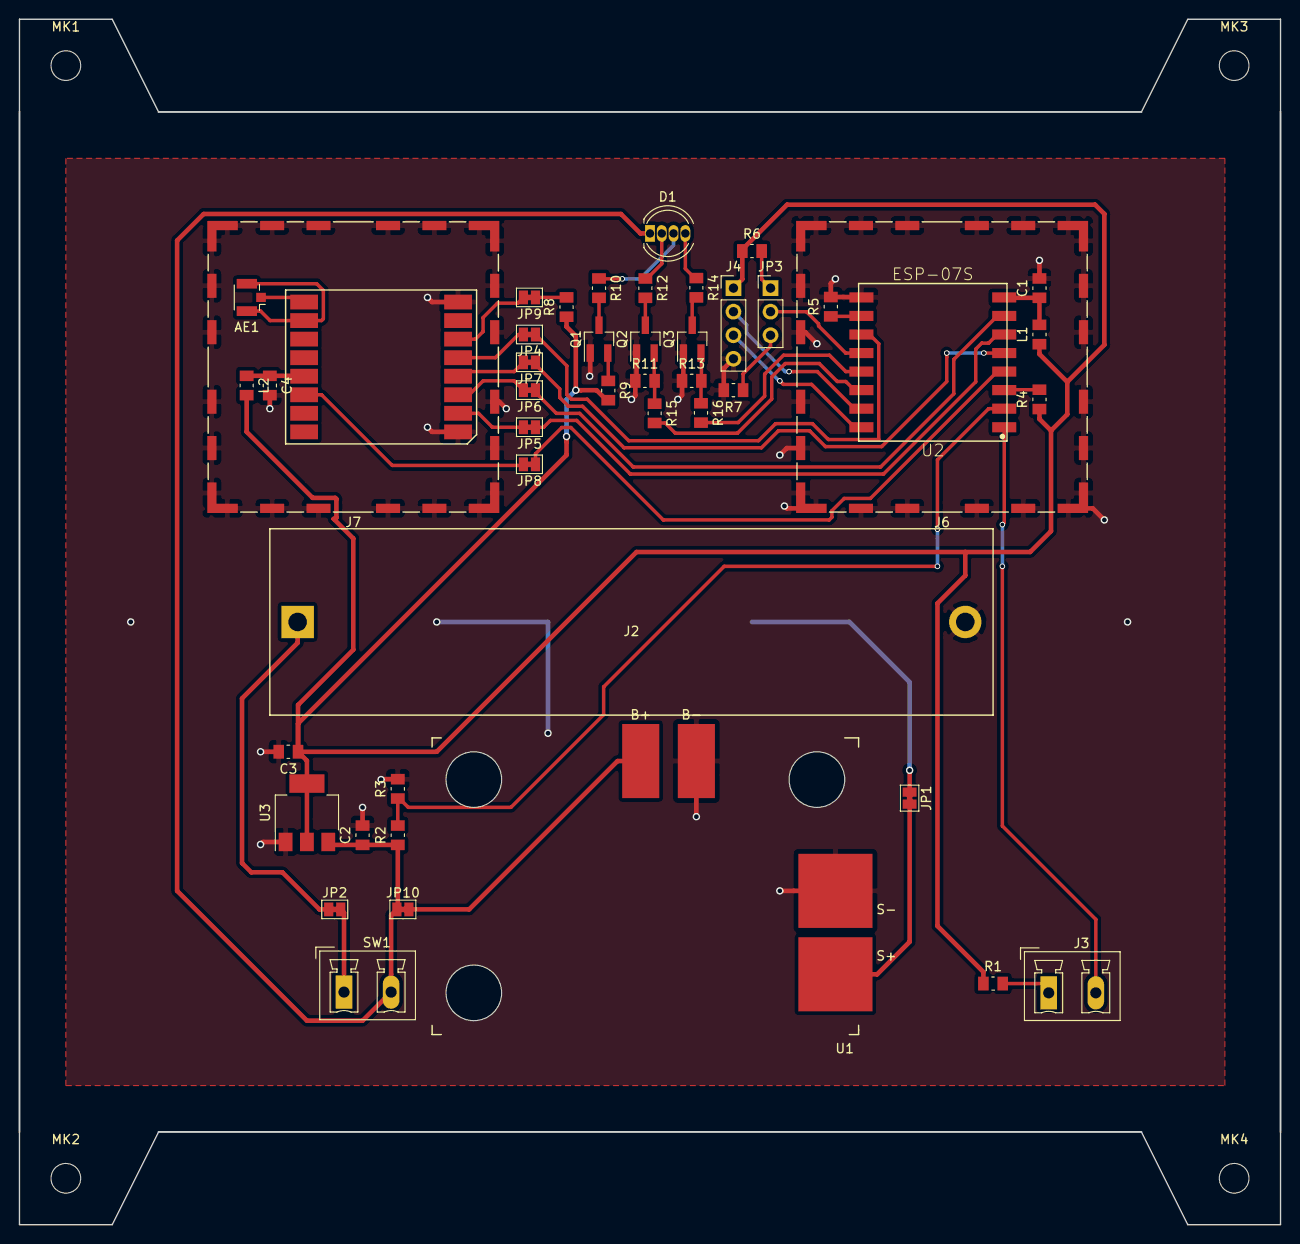
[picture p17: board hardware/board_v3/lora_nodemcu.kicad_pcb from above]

Board: 2 copper layers, 136.0 x 130.0 mm, 52 parts (1 on the bottom side), 45 nets.

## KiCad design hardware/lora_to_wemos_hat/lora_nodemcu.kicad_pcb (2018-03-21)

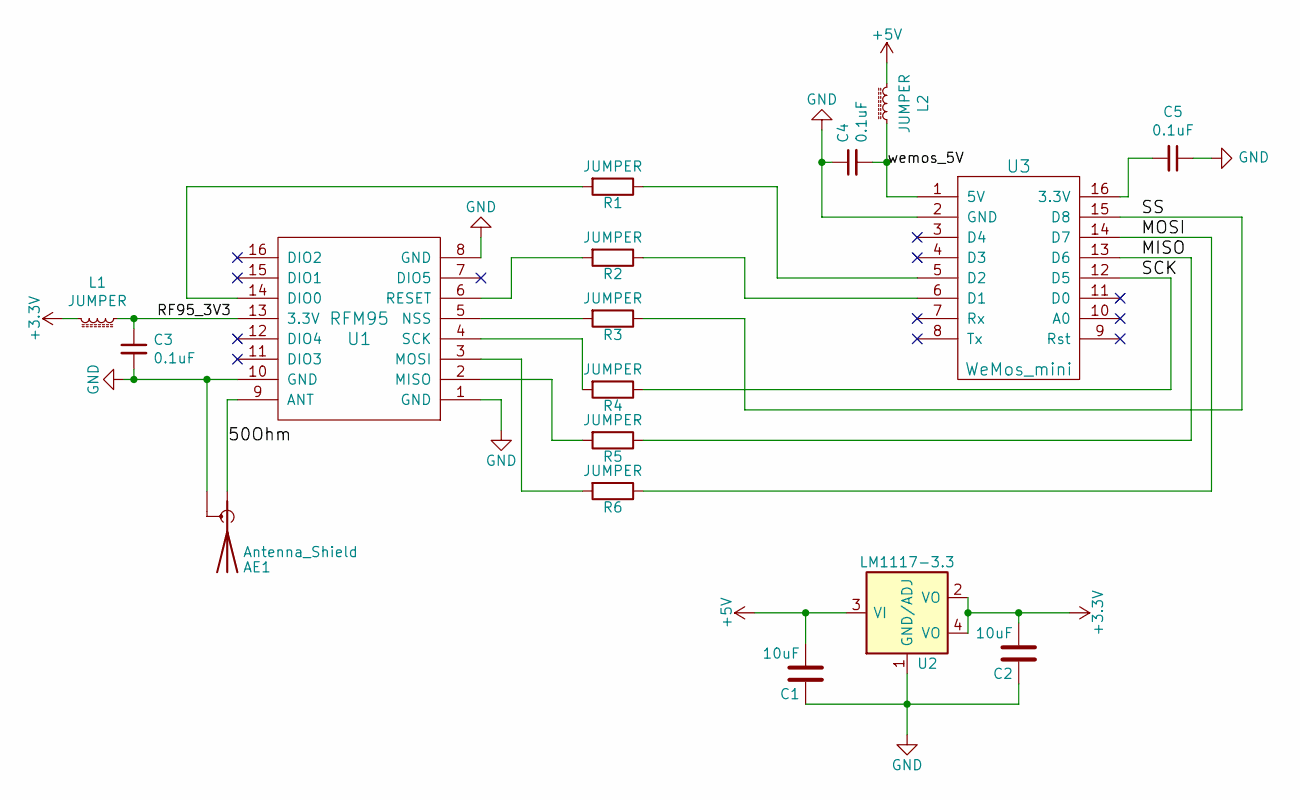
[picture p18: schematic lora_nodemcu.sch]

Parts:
AE1: Antenna_Shield; Molex_SMA_Jack_Edge_Mount
C1, C2: 10uF; C_0805_HandSoldering
C3, C4, C5: 0.1uF; C_0805_HandSoldering
L1, L2: JUMPER; SolderJumper-2_P1.3mm_Bridged_Pad1.0x1.5mm
R1, R2, R3, R4, R5, R6: JUMPER; SolderJumper-2_P1.3mm_Bridged_Pad1.0x1.5mm
U1: RFM95
U2: LM1117-3.3; SOT-223
U3: WeMos_mini; D1_mini_board

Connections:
+3V3: C2.2, L1.2, U2.2 (VO), U2.4 (VO)
+5V: C1.2, L2.2, U2.3 (VI)
/50Ohm: AE1.1 (A), U1.9 (ANT)
/MISO: R5.1, U3.13 (D6)
/MOSI: R6.1, U3.14 (D7)
/RF95_3V3: C3.1, L1.1, U1.13 (3.3V)
/SCK: R4.1, U3.12 (D5)
/SS: R3.1, U3.15 (D8)
/wemos_5V: C4.2, L2.1, U3.1 (5V)
GND: AE1.2 (Shield), C1.1, C2.1, C3.2, C4.1, C5.1, U1.1 (GND), U1.8 (GND), U1.10 (GND), U2.1 (GND/ADJ), U3.2 (GND)
unnamed: C5.2, U3.16 (3.3V)
unnamed: R1.1, U3.5 (D2)
unnamed: R1.2, U1.14 (DIO0)
unnamed: R2.1, U3.6 (D1)
unnamed: R2.2, U1.6 (RESET)
unnamed: R3.2, U1.5 (NSS)
unnamed: R4.2, U1.4 (SCK)
unnamed: R5.2, U1.2 (MISO)
unnamed: R6.2, U1.3 (MOSI)

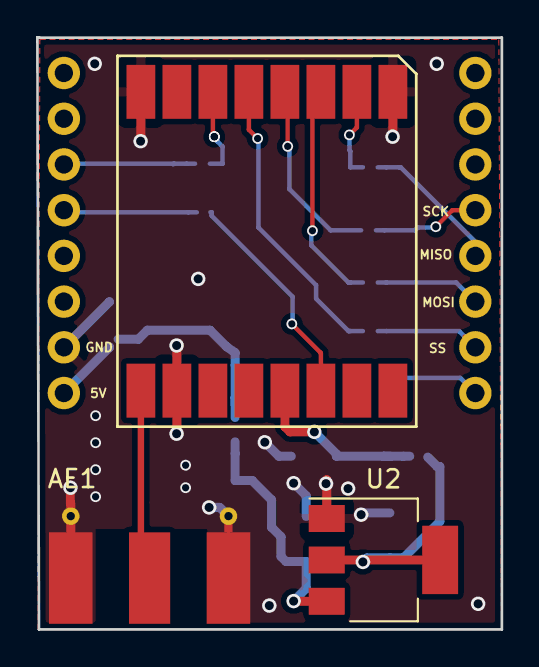
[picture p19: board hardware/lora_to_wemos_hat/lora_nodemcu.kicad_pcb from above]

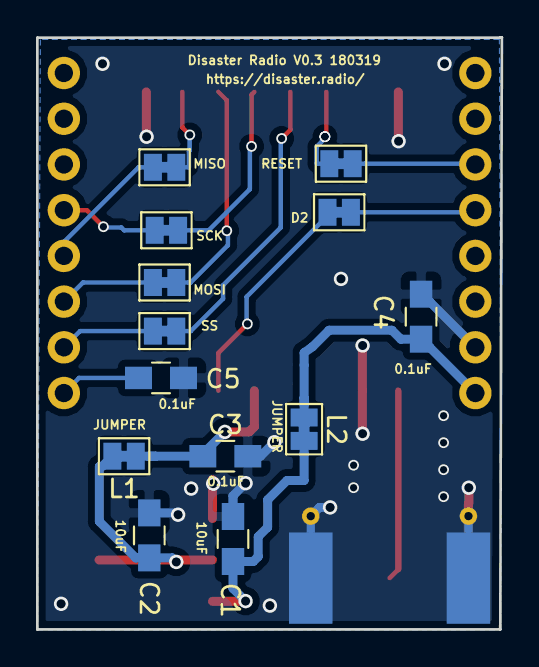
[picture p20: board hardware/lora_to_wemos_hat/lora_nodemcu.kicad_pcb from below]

Board: 4 copper layers, 25.8 x 32.9 mm, 17 parts (13 on the bottom side), 19 nets.

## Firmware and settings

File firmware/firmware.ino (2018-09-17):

#define FS_NO_GLOBALS

#include <ESP8266WiFi.h>
#include <FS.h>
#include <Hash.h>
#include <ESPAsyncTCP.h>
#include <ESPAsyncWebServer.h>
#include <ESP8266mDNS.h>
#include <SPIFFSEditor.h>
#include <SPI.h>
#include <LoRa.h>
#include <SD.h>
#include "AsyncSDServer.ino"

#define HEADERSIZE 4 
#define BUFFERSIZE 252
#define SHA1_LEN 40 

byte mac[6];
char macaddr[14];
char ssid[32] = "disaster.radio ";
const char * hostName = "disaster-node";

IPAddress local_IP(192, 162, 4, 1);
IPAddress gateway(0, 0, 0, 0);
IPAddress netmask(255, 255, 255, 0);
const char * url = "chat.disaster.radio";

AsyncWebServer server(80);
AsyncWebSocket ws("/ws");
AsyncEventSource events("/events");

int loraInitialized = 0; // has the LoRa radio been initialized?
int sdInitialized = 0; // has the LoRa radio been initialized?

int retransmitEnabled = 0;
int pollingEnabled = 0;
int hashingEnabled = 1;
int asyncTx = 1;

int beaconModeEnabled = 0;
int beaconInterval = 30000;

// for portable node (wemos d1 mini) use these settings:
const int loraChipSelect = 15; // LoRa radio chip select, GPIO15 = D8 on WeMos D1 mini
const int resetPin = 5;       // LoRa radio reset, GPIO0 = D3 
const int irqPin = 4;        // interrupt pin for receive callback?, GPIO2 = D4

// for solar-powered module use these settings:
/*
const int csPin = 2;          // LoRa radio chip select, GPIO2
const int resetPin = 5;       // LoRa radio reset (hooked to LED, unused)
const int irqPin = 16;        // interrupt pin for receive callback?, GPIO16
*/

const int SDChipSelect = 2;

//TODO: switch to volatile byte for interrupt

byte localAddress;     // assigned to last byte of mac address in setup
byte destination = 0xFF;      // destination to send to default broadcast

bool echo_on = false;

char hashTable[256][40];
int hashEntry = 0;

char incomingBuffer[8][256];
int incomingBufferLength[8];
int bufferEntry = 0;
int bufferInterval = 5000;

/*
  FORWARD-DEFINED FUNCTIONS
*/

void SPIenable(int opt){
    switch (opt){
        case 0: // select SD
            Serial.printf("enabling SD card");
            Serial.printf("\r\n");
            digitalWrite(loraChipSelect, HIGH);
            digitalWrite(SDChipSelect, LOW); 
            break;
        case 1: // select LORA 
            Serial.printf("enabling LoRa radio");
            Serial.printf("\r\n");
            digitalWrite(loraChipSelect, LOW);
            digitalWrite(SDChipSelect, HIGH); // select SD card first, to initialize
            break;
    }
}

bool isHashNew(char incoming[SHA1_LEN]){
    bool hashNew = true;
    for( int i = 0 ; i <= hashEntry ; i++){
        if(strcmp(incoming, hashTable[i]) == 0){
            hashNew = false; 
        }
    }
    if( hashNew ){
        Serial.printf("New message received");
        Serial.printf("\r\n");
        for( int i = 0 ; i < SHA1_LEN ; i++){
            hashTable[hashEntry][i] = incoming[i];
        }
        hashEntry++;
    }
    return hashNew;
}

void sendMessage(char* outgoing, int outgoingLength) {

    
    if(!loraInitialized){
        return;
    }

    if(hashingEnabled){
        // do not send message if already transmitted once
        char hashOutgoing[SHA1_LEN];
        String hash = sha1(outgoing, outgoingLength);
        hash.toCharArray(hashOutgoing, SHA1_LEN);

        if(!isHashNew(hashOutgoing)){
            return;
        }
    }

    Serial.printf("Sending: ");
    
    LoRa.beginPacket();
    for( int i = 0 ; i < outgoingLength ; i++){
        LoRa.write(outgoing[i]);
        Serial.printf("%c", outgoing[i]);
    }
    Serial.printf("\r\n");
    LoRa.endPacket(asyncTx);
    LoRa.receive();
}

void printToWS(char message[252], int messageLength){

    char msg[256] = "99c|";  
    int length = messageLength + HEADERSIZE;
    for (int i = 0 ; i < messageLength ; i++){
        msg[i+HEADERSIZE] = message[i]; 
    }
    ws.binaryAll(msg, length);
}

void storeMessage(char* message, int messageLength) {
    //store full message in log file
    File log = SD.open("/log.txt", FILE_WRITE);
    if(!log){
        Serial.printf("file open failed");
        Serial.printf("\r\n");
    }
    for(int i = 0 ; i <= messageLength ; i++){
        log.printf("%c", message[i]);
    }
    log.printf("\n");
    log.close();
}

String dumpLog() {
    String dump = "";
    File log = SD.open("/log.txt", FILE_READ);
    if(!log){
        Serial.printf("file open failed");
        Serial.printf("\r\n");
    }  
    Serial.print("reading log file: \r\n");
    while (log.available()){
        //TODO replace string with char array
        String s = log.readStringUntil('\n');
        dump += s;
        dump += "\r\n";
    }
    return dump;
}

void clearLog() {
    File log = SD.open("/log.txt", FILE_WRITE);
    log.close();
}

void printCharArray(char *buf, int len){
    for(int i = 0 ; i < len ; i++){
        Serial.printf("%c", buf[i]);
    }
    Serial.printf("\r\n");
}

void addToBuffer(char message[256], int length){
    if(bufferEntry > 7){
        bufferEntry = 0;
    }
    Serial.printf("adding message to buffer");
    Serial.printf("\r\n");
    incomingBufferLength[bufferEntry] = length;
    for( int i = 0 ; i < length ; i++){
        incomingBuffer[bufferEntry][i] = message[i];    
    }
    bufferEntry++;
}

void handleMessage(char message[256], int length){

    ws.binaryAll(message, length);
    if(retransmitEnabled){
        addToBuffer(message, length);
    }
}

void handleHopCounter(char buffer[256], int length){

    int hops = buffer[4]-'0'; //convert char to int by subtracting ASCII value of zero
    // this will only work for <10 hops
    char origin[14];
    for( int i = 0 ; i < 14 ; i++){
        origin[i] = buffer[6+i];
    }
    hops++;

    char message[256];
    char retransmit[256];

    sprintf(message, "%d hop from %s", hops, origin);
    sprintf(retransmit, "FFh|%d,%s", hops, origin);

    printToWS(message, 29);

    if(hashingEnabled){
        // do not send message if already transmitted once
        buffer[4] = '*'; //convert char to int by subtracting ASCII value of zero
        char bufferHash[SHA1_LEN];
        String hash = sha1(buffer, length);
        hash.toCharArray(bufferHash, SHA1_LEN);

        if(!isHashNew(bufferHash)){
            return;
        }
    }
    
    if(retransmitEnabled){
        addToBuffer(retransmit, length);
    }
}


long lastCheckTime = millis();
void checkBuffer(){
    if (millis() - lastCheckTime > bufferInterval) {
        if (retransmitEnabled){
            Serial.printf("checking buffer");
            Serial.printf("\r\n");
            if (bufferEntry > 0){
                Serial.printf("removing from buffer and retransmiting");
                Serial.printf("\r\n");
                int retransmitLength = incomingBufferLength[bufferEntry-1];
                char retransmit[retransmitLength];
                for( int i = 0 ; i < retransmitLength ; i++){
                    retransmit[i] = incomingBuffer[bufferEntry-1][i];
                    Serial.printf("%c", retransmit[i]);
                    incomingBuffer[bufferEntry-1][i] = 0;
                }
                Serial.printf("\r\n");
                bufferEntry--;
                sendMessage(retransmit, retransmitLength);
            }
        }
        lastCheckTime = millis();
    }
}

long lastBeaconTime = millis();
void transmitBeacon(){
    if (millis() - lastBeaconTime > beaconInterval) {
        int test_length = 6;
        char test_message[256] = "FFh|0,";   // send a message
        for(int i = 0 ; i < 14 ; i++){
            test_message[test_length] = macaddr[i];
            test_length++;
        }
        Serial.printf("Sending: %s", test_message);
        Serial.printf("\r\n");
        sendMessage(test_message, test_length);

        lastBeaconTime = millis();
    }
}

/*
  CALLBACK FUNCTIONS
*/
void onReceive(int packetSize) {

    if (packetSize == 0) return;          // if there's no packet, return

    char incoming[BUFFERSIZE];                 // payload of packet

    int incomingLength = 0;
    while (LoRa.available()) { 
        incoming[incomingLength] = (char)LoRa.read(); 
        incomingLength++;
    }

    char type = incoming[2];
    Serial.printf("message type: %c", type);
    Serial.printf("\r\n");

    Serial.printf("PACKET|");
    printCharArray(incoming, incomingLength);
    Serial.printf("\r\n");

    storeMessage(incoming, incomingLength);

    switch(type){
        case 'c':
            Serial.printf("received chat message");
            Serial.printf("\r\n");
            handleMessage(incoming, incomingLength);
            break;
        case 'm':
            Serial.printf("received map message");
            Serial.printf("\r\n");
            handleMessage(incoming, incomingLength);
            break;
        case 'h':
            Serial.printf("received hop message");
            Serial.printf("\r\n");
            handleHopCounter(incoming, incomingLength);
            break;
        default:
            Serial.printf("Error: Unknown message type");
            Serial.printf("\r\n");
    }
}

void onWsEvent(AsyncWebSocket * server, AsyncWebSocketClient * client, AwsEventType type, void * arg, uint8_t *data, size_t len){
    if(type == WS_EVT_CONNECT){
        Serial.printf("ws[%s][%u] connect\r\n", server->url(), client->id());
        printToWS("Welcome to DISASTER RADIO", 26);
        if(echo_on){
            printToWS("echo enabled, to turn off, enter '$' after logging in", 54);
        }
        if(!sdInitialized){
            printToWS("WARNING: SD card not found, functionality may be limited", 57);
        }
        if(!loraInitialized){
            printToWS("WARNING: LoRa radio not found, functionality may be limited", 60);
        }
        client->ping();
    } else if(type == WS_EVT_DISCONNECT){
        Serial.printf("ws[%s][%u] disconnect: %u\r\n", server->url(), client->id());
    } else if(type == WS_EVT_ERROR){
        Serial.printf("ws[%s][%u] error(%u): %s\r\n", server->url(), client->id(), *((uint16_t*)arg), (char*)data);
    } else if(type == WS_EVT_PONG){
        Serial.printf("ws[%s][%u] pong[%u]: %s\r\n", server->url(), client->id(), len, (len)?(char*)data:"");
    } else if(type == WS_EVT_DATA){

        AwsFrameInfo * info = (AwsFrameInfo*)arg;
        char msg_id[4];
        char usr_id[32];
        char msg[256];
        int msg_length;
        int usr_id_length = 0;
        int usr_id_stop = 0;

        if(info->final && info->index == 0 && info->len == len){
            //the whole message is in a single frame and we got all of it's data

            Serial.printf("ws[%s][%u] %s-message[%llu]: \r\n", server->url(), client->id(), (info->opcode == WS_TEXT)?"text":"binary", info->len);
            //cast data to char array
            for(size_t i=0; i < info->len; i++) {
                //TODO check if info length is bigger than allocated memory
                msg[i] = (char) data[i];
                msg_length = i; 
                    
                if(msg[i] == '$'){
                    echo_on = !echo_on;
                }

                // check for stop char of usr_id
                if(msg[i] == '>'){
                    usr_id_stop = i;  
                }
            }
            msg_length++;
            msg[msg_length] = '\0';

            //parse message id 
            memcpy( msg_id, msg, 2 );
            msg_id[2] = '!';
            msg_id[3] = '\0';   

            //parse username
            for( int i = 5 ; i < usr_id_stop ; i++){
                usr_id[i-5] = msg[i];
            }
            usr_id_length = usr_id_stop - 5;

            //print message info to serial
            Serial.printf("Message Length: %d\r\n", msg_length);
            Serial.printf("Message ID: %02d%02d %c\r\n", msg_id[0], msg_id[1], msg_id[2]);
            Serial.printf("Message:");
            for( int i = 0 ; i <= msg_length ; i++){
                Serial.printf("%c", msg[i]);
            }
            Serial.printf("\r\n");

            //TODO delay ack based on estimated transmit time
            //send ack to websocket
            ws.binary(client->id(), msg_id, 3);

            //transmit message over LoRa
            sendMessage(msg, msg_length);

            //echoing message to ws
            if(echo_on){
                /*
                char echo[256]; 
                char prepend[7] = "<echo>";
                int prepend_length= 6;
                memcpy(echo, msg, 4);
                for( int i = 0 ; i < prepend_length ; i++){
                    echo[4+i] = prepend[i];
                }
                for( int i = 0 ; i < msg_length-usr_id_stop ; i++){
                    echo[4+prepend_length+i] = msg[i+usr_id_stop+1];
                }
                int echo_length = prepend_length - usr_id_length + msg_length - 1;
                */
                ws.binaryAll(msg, msg_length);
            }
        } 
        else {
            //TODO message is comprised of multiple frames or the frame is split into multiple packets

        }
    }
}

/*
  SETUP FUNCTIONS
*/
void wifiSetup(){
    WiFi.macAddress(mac);
    sprintf(macaddr, "%02x%02x%02x%02x%02x%02x", mac[5], mac[4], mac[3], mac[2], mac[1], mac [0]);
    strcat(ssid, macaddr);
    WiFi.hostname(hostName);
    WiFi.mode(WIFI_AP);
    //WiFi.softAPConfig(local_IP, gateway, netmask);
    WiFi.softAP(ssid);
}

void mdnsSetup(){
    if(!MDNS.begin("disaster")){
        Serial.printf("Error setting up mDNS\r\n");
        while(1) {
            delay(1000);
        }
    }
    Serial.printf("mDNS responder started\r\n");

    MDNS.addService("http", "tcp", 80);
}

void sdCardSetup(){
    Serial.print("\r\nWaiting for SD card to initialise...");
    if (SD.begin(SDChipSelect, 32000000)) { // CS is D8 in this example
        Serial.print("SD Card initialized");
        Serial.print("\r\n");
        sdInitialized = 1;
        File entry;
        File dir = SD.open("/");
        dir.rewindDirectory();
        Serial.print("ROOT DIRECTORY:");
        Serial.print("\r\n");
        while(true){
            entry = dir.openNextFile();
            if (!entry) break;
            Serial.printf("%s, type: %s, size: %ld", entry.name(), (entry.isDirectory())?"dir":"file", entry.size());
            entry.close();
            Serial.print("\r\n");
        }
        dir.close();
    } else{
        Serial.print("SD Card Not Found!");
        Serial.print("\r\n");
    }
}

void spiffsSetup(){
    if (SPIFFS.begin()) {
        Serial.print("ok\r\n");
        if (SPIFFS.exists("/index.htm")) {
            Serial.printf("The file exists!\r\n");
            fs::File f = SPIFFS.open("/index.htm", "r");
            if (!f) {
                Serial.printf("Some thing went wrong trying to open the file...\r\n");
            }
            else {
                int s = f.size();
                Serial.printf("Size=%d\r\n", s);
                String data = f.readString();
                Serial.printf("%s\r\n", data.c_str());
                f.close();
            }
        }
        else {
            Serial.printf("No such file found.\r\n");
        }
    }
}


void webServerSetup(){


    ws.onEvent(onWsEvent);
    server.addHandler(&ws);

    events.onConnect([](AsyncEventSourceClient *client){
        client->send("hello!",NULL,millis(),1000);
    });

    server.addHandler(&events);

    if(sdInitialized){
        server.addHandler(new AsyncStaticSDWebHandler("/", SD, "/", "max-age=604800"));
    }else{
        server.serveStatic("/", SPIFFS, "/").setDefaultFile("index.htm");
    }
    
    server.onNotFound([](AsyncWebServerRequest *request){
        Serial.printf("NOT_FOUND: ");
        if(request->method() == HTTP_GET)
        Serial.printf("GET");
        else if(request->method() == HTTP_POST)
        Serial.printf("POST");
        else if(request->method() == HTTP_DELETE)
        Serial.printf("DELETE");
        else if(request->method() == HTTP_PUT)
        Serial.printf("PUT");
        else if(request->method() == HTTP_PATCH)
        Serial.printf("PATCH");
        else if(request->method() == HTTP_HEAD)
        Serial.printf("HEAD");
        else if(request->method() == HTTP_OPTIONS)
        Serial.printf("OPTIONS");
        else
        Serial.printf("UNKNOWN");
        Serial.printf(" http://%s%s\r\n", request->host().c_str(), request->url().c_str());

        if(request->contentLength()){
            Serial.printf("_CONTENT_TYPE: %s\r\n", request->contentType().c_str());
            Serial.printf("_CONTENT_LENGTH: %u\r\n", request->contentLength());
        }

        int headers = request->headers();
        int i;
        for(i=0;i<headers;i++){
            AsyncWebHeader* h = request->getHeader(i);
            Serial.printf("_HEADER[%s]: %s\r\n", h->name().c_str(), h->value().c_str());
        }

        int params = request->params();
        for(i=0;i<params;i++){
            AsyncWebParameter* p = request->getParam(i);
            if(p->isFile()){
                Serial.printf("_FILE[%s]: %s, size: %u\r\n", p->name().c_str(), p->value().c_str(), p->size());
            } else if(p->isPost()){
                Serial.printf("_POST[%s]: %s\r\n", p->name().c_str(), p->value().c_str());
            } else {
                Serial.printf("_GET[%s]: %s\r\n", p->name().c_str(), p->value().c_str());
            }
        }

        request->send(404);
    });

    server.onRequestBody([](AsyncWebServerRequest *request, uint8_t *data, size_t len, size_t index, size_t total){
        if(!index)
        Serial.printf("BodyStart: %u\r\n", total);
        Serial.printf("%s", (const char*)data);
        if(index + len == total)
        Serial.printf("BodyEnd: %u\r\n", total);
    });

    server.begin();

}


void loraSetup(){
    localAddress = mac[0];

    // override the default CS, reset, and IRQ pins (optional)
    LoRa.setPins(loraChipSelect, resetPin, irqPin); // set CS, reset, IRQ pin

    if (!LoRa.begin(915E6)) {             // initialize ratio at 915 MHz
        Serial.printf("LoRa init failed. Check your connections.\r\n");
        return;
    }

    LoRa.setSPIFrequency(100E3);
    LoRa.setSpreadingFactor(9);           // ranges from 6-12,default 7 see API docs
    LoRa.onReceive(onReceive);
    LoRa.receive();

    loraInitialized = 1;

    Serial.printf("LoRa init succeeded.\r\n");
    Serial.printf("local address: %02x\r\n", localAddress);
    Serial.printf("%s\r\n", macaddr);
}

/*
  START MAIN
*/
void setup(){
    Serial.begin(115200);
    Serial.setDebugOutput(true);

    pinMode(loraChipSelect, OUTPUT);
    pinMode(SDChipSelect, OUTPUT);
    pinMode(irqPin, INPUT);


    wifiSetup();
    mdnsSetup();

    SPIenable(0); //SD
    sdCardSetup();

    if(!sdInitialized){
        spiffsSetup();
    }    

    webServerSetup();

    loraSetup();

}

int interval = 10000 + random(5000);    // 5-15 seconds
long lastSendTime = 0; // time of last packet send

void loop(){

    int packetSize;

    if(LoRa.beginPacket() == 0){
        // do stuff while LoRa packet is being sent
        //Serial.print("transmitting a packet...\r\n");
        //delay(100);
        return;
    }else{
        // do stuff when LoRa packet is NOT being sent
        checkBuffer(); 

        if (beaconModeEnabled){
            transmitBeacon();
        }

        if (pollingEnabled){
            
            if (millis() - lastSendTime > interval) {

                int packetSize = LoRa.parsePacket();
                Serial.printf("checking for data: %d\r\n", packetSize); 
                if(packetSize) {
                    onReceive(packetSize);
                }
                lastSendTime = millis();

            }
        }
    }
}

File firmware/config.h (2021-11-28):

#ifndef CONFIG_H
#define CONFIG_H

// secrets in a separate file so we don't accidentally commit credentials
#if __has_include("secrets.h")
#include "secrets.h"
#endif

#define CLOCK_SPEED 240

#ifdef TTGO_LORA_V1
#define LORA_SCK 5
#define LORA_MISO 19
#define LORA_MOSI 27
#define LORA_CS 18
#define LORA_RST 14
#define LORA_IRQ 26
#define OLED_SDA 4
#define OLED_SCL 15
#define OLED_RST 16
#define OLED_WIDTH 128
#define OLED_HEIGHT 64
#endif

#ifdef TTGO_LORA_V2
#define SD_SCK 14
#define SD_MISO 2
#define SD_MOSI 15
#define OLED_SDA 21
#define OLED_SCL 22
#define OLED_RST NOT_A_PIN
#define OLED_WIDTH 128
#define OLED_HEIGHT 64
#endif

#ifdef TTGO_TBEAM
// #define LORA_SCK 14
// #define LORA_MISO 2
// #define LORA_MOSI 15
// #define LORA_CS 18
// #define LORA_RST 23
// #define LORA_IRQ 26
// #define SD_SCK 14
// #define SD_MISO 2
// #define SD_MOSI 15
#define OLED_SDA 21
#define OLED_SCL 22
#define OLED_RST NOT_A_PIN
#define OLED_WIDTH 128
#define OLED_HEIGHT 64

// https://github.com/cyberman54/ESP32-Paxcounter/blob/825520a20f1a1b7a9ac5e725484c2704bcb8117b/src/hal/ttgobeam.h
#define GPS_SERIAL 9600, SERIAL_8N1, GPIO_NUM_12, GPIO_NUM_15

#endif

#ifdef HELTEC
#define LORA_IRQ 26
#define LORA_IO1 35
#define LORA_IO2 34
#define LORA_SCK 5
#define LORA_MISO 19
#define LORA_MOSI 27
#define LORA_RST 14
#define LORA_CS 18
#define OLED_SDA 4
#define OLED_SCL 15
#define OLED_RST 16
#define OLED_WIDTH 128
#define OLED_HEIGHT 64
#endif

#ifdef SPARKFUN
#define LORA_IRQ 26
#define LORA_IO1 33
#define LORA_IO2 32
#define LORA_SCK 14 SCK
#define LORA_MISO 12
#define LORA_MOSI 13
#define LORA_RST NOT_A_PIN
#define LORA_CS 16
//#define OLED_SDA 21
#define OLED_SCL 22
#define OLED_RST NOT_A_PIN
#define OLED_WIDTH 128
#define OLED_HEIGHT 128
#endif

#ifdef LOPY4
// all necessary pins are defined in the arduino-esp32 variants
// https://github.com/espressif/arduino-esp32/blob/master/variants/lopy4/pins_arduino.h
// any additional board specifc settings should be added here
#define LORA_IRQ 23
#define LORA_CS 18
// to add second LoRa module connect it to these pins and specific DUAL_LORA as a build flag
#define LORA2_IRQ 26
#define LORA2_RST NOT_A_PIN
#define LORA2_CS 25
#endif

#ifdef ESP32_V3

#define LORA_IRQ 22
#define LORA_CS 16
#define LORA_IO1 26
#define LORA_IO2 NOT_A_PIN
#define LORA_RST NOT_A_PIN
#define LORA_SCK 18
#define LORA_MOSI 23
#define LORA_MISO 19
#define LORA_RXEN 17

//comment all LORA2 lines and -DDUAL_LORA build flag to disable second module

#define LORA2_CS 33
#define LORA2_IRQ 35
#define LORA2_RST NOT_A_PIN
#define LORA2_IO1 27
#define LORA2_IO2 NOT_A_PIN
#define LORA2_RXEN 21
#endif

#endif

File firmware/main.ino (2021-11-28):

#include <Arduino.h>

// required for LoRa and/or AsyncSDServer libraries?
#include <FS.h>
#include <SPI.h>

#include <WiFi.h>
#include <AsyncTCP.h>
#include <ESPAsyncWebServer.h>
#include <ESPmDNS.h>
#include <AsyncSDServer.h>
#include <SD.h>
#include <SPIFFS.h>
#ifdef HAS_OLED
#include <SSD1306Wire.h>
#endif
#include "config.h"

#ifdef ARDUINO_LORA
#include <Layer1_LoRa.h>
#endif

#ifdef RL_SX1276
#include <Layer1_SX1276.h>
#endif
#ifdef RL_SX1262
#include <Layer1_SX126x.h>
#endif

#include <LoRaLayer2.h>

// server
#include "server/DisasterRadio.h"
// client
#include "client/OLEDClient.h"
#include "client/HistoryRecord.h"
#include "client/LoRaClient.h"
#include "client/StreamClient.h"
#include "client/TCPClient.h"
#include "client/WebSocketClient.h"
#include "client/GPSClient.h"
#include "client/BleUartClient.h"

// middleware
#include "middleware/Console.h"
#include "middleware/HistoryReplay.h"
// history
#include "history/HistorySD.h"
#include "history/HistoryMemory.h"

#include "DisasterHistory.h"
#include "DisasterMiddleware.h"

#define MDNS_NAME_PREFIX "disaster"
#define HOST_NAME "disaster.radio"
#define WIFI_AP_SSID_PREFIX "disaster.radio "

#define INDEX_FILE "index.htm"

#ifdef HAS_OLED
SSD1306Wire display(0x3c, OLED_SDA, OLED_SCL);
#endif

SPIClass sd_card(HSPI);

SPIClass SPI_1(SPI);
SPIClass SPI_2(SPI);

AsyncServer tcp_server(23);
AsyncWebServer http_server(80);
AsyncWebSocket ws_server("/ws");

BleUartClient ble_client;

#ifdef ARDUINO_LORA
Layer1Class *Layer1 = new Layer1Class();
#endif

#ifdef RL_SX1276
SX1276 lora = new Module(LORA_CS, LORA_IRQ, LORA_RST, RADIOLIB_NC);
  #ifdef DUAL_LORA
  SX1276 lora2 = new Module(LORA2_CS, LORA2_IRQ, LORA2_RST, RADIOLIB_NC);
  #endif
#endif

#ifdef RL_SX1262
SX1262 lora = new Module(LORA_CS, LORA_IRQ, LORA_RST, RADIOLIB_NC);
  #ifdef DUAL_LORA
  SX1262 lora2 = new Module(LORA2_CS, LORA2_IRQ, LORA2_RST, RADIOLIB_NC);
  #endif
#endif

LL2Class *LL2;

#include "settings/settings.h"

DisasterRadio *radio = new DisasterRadio();
DisasterHistory *history = NULL;

int internal_clients = 0;
int clients = 0;
int routes = 0;

#define WIFI_POLL_DELAY 500
#define WIFI_POLL_TRIES 20

char nodeAddress[ADDR_LENGTH*2 + 1] = {'\0'};
char ssid[100] = {'\0'};
IPAddress ip;

bool sdInitialized = false;
bool spiffsInitialized = false;
bool displayInitialized = false;
bool loraInitialized = false;

void setupWiFi()
{
  Serial.println("* Initializing WiFi...");

  // get the WiFi MAC address
  uint8_t mac[6];
  WiFi.macAddress(mac);

  // format WiFi MAC address to string
  sprintf(nodeAddress, "%02x%02x%02x%02x", mac[2], mac[3], mac[4], mac[5]);

#ifdef WIFI_SSID
  Serial.printf(" --> Connecting to WiFi \"%s\"\n", WIFI_SSID);
  for (int i = 0; i < WIFI_POLL_TRIES && WiFi.status() != WL_CONNECTED; i++)
  {
    WiFi.begin(WIFI_SSID, WIFI_PASSWORD);
    delay(WIFI_POLL_DELAY);
  }
  if (WiFi.status() == WL_CONNECTED)
  {
    ip = WiFi.localIP();
    snprintf(ssid, sizeof(ssid), "%s", WIFI_SSID);

    Serial.print(" --> WiFi connected, IP address: ");
    Serial.println(ip);
  }
  else
  {
    Serial.println(" --> Unable to connect to WiFi");
  }
#endif

  if (WiFi.status() != WL_CONNECTED)
  {
    // format full SSID with MAC address suffix
    snprintf(ssid, sizeof(ssid), "%s%s", WIFI_AP_SSID_PREFIX, nodeAddress);

    // start the AP
    WiFi.mode(WIFI_AP);
    WiFi.setHostname(HOST_NAME);
    WiFi.softAP(ssid);

    ip = WiFi.localIP();
    Serial.printf(" --> Started WiFi AP \"%s\", IP address: ", ssid);
    Serial.println(ip);
  }
}

void checkWiFi() {
#ifdef WIFI_SSID
  if (WiFi.status() != WL_CONNECTED) {
    WiFi.begin(WIFI_SSID, WIFI_PASSWORD);
  }
#endif
}

void setupMDNS()
{
  Serial.println("* Initializing mDNS responder...");
  if (MDNS.begin(MDNS_NAME_PREFIX))
  {
    Serial.println(" --> Advertising http://" MDNS_NAME_PREFIX ".local");
  }
  else
  {
    Serial.println(" --> mDNS responder failed");
  }
}

void setupSD()
{
#ifdef SD_SCK
  Serial.println("* Initializing SD card...");
  sd_card.begin(SD_SCK, SD_MISO, SD_MOSI, -1);
  if (SD.begin(13, sd_card))
  {
    sdInitialized = true;
  }
  else
  {
    Serial.println(" --> SD card not found");
  }
#endif
}

void setupSPIFFS()
{
  Serial.println("* Initializing SPIFFS...");
  if (SPIFFS.begin())
  {
    spiffsInitialized = true;
  }
  else
  {
    Serial.println(" --> SPIFFS initializtion failed");
  }
}

bool checkFileIsReadable(FS &fs, const char *path)
{
  if (fs.exists(path))
  {
    return !!fs.open(path, "r");
  }
  return false;
}

void setupHTTPSever()
{
  Serial.println("* Initializing HTTP server...");

  if (sdInitialized && checkFileIsReadable(SD, "/" INDEX_FILE))
  {
    Serial.println(" --> Serving web application from SD card");
    http_server.addHandler(new AsyncStaticSDWebHandler("/", SD, "/", "max-age=604800"));
  }
  else if (spiffsInitialized && checkFileIsReadable(SPIFFS, "/" INDEX_FILE))
  {
    Serial.println(" --> Serving web application from SPIFFS");
    http_server.serveStatic("/", SPIFFS, "/").setDefaultFile(INDEX_FILE);
  }
  else
  {
    Serial.println(" --> No web application found! Did you add it to the SD card or SPIFFs?");
  }

  http_server.onNotFound([](AsyncWebServerRequest *request) {
    request->send(404);
  });

  http_server.onRequestBody([](AsyncWebServerRequest *request, uint8_t *data, size_t len, size_t index, size_t total) {
  });

  http_server.begin();

  MDNS.addService("http", "tcp", 80);
}

void setupHistory()
{
  Serial.println("* Initializing history...");

  if (sdInitialized)
  {
    HistorySD *history_sd_client = new HistorySD(&sd_card);
    if (history_sd_client->init())
    {
      Serial.println(" --> Storing history on SD card");
      history = history_sd_client;
    }
  }
  if (!history)
  {
    Serial.println(" --> Storing (limited) history in memory");
    history = new HistoryMemory();
  }

  radio->connect(new HistoryRecord(history));
}

struct Datagram buildDatagram(uint8_t destination[ADDR_LENGTH], uint8_t type, uint8_t* data, size_t len){
    struct Datagram datagram;
    memcpy(datagram.destination, destination, ADDR_LENGTH);
    datagram.type = 'c';
    memcpy(datagram.message, data, len);
    return datagram;
}
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

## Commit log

2017-09-06 fixed function declaration order
    [firmware.ino]
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2017-09-12 replace println with printf
    [firmware.ino]
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2017-09-28 starting on board layout
    [lora_nodemcu.kicad_pcb, lora_nodemcu.sch]
2017-10-04 Using Wemo esp8266 instead of NodeMCU
    [lora_nodemcu.sch]
2017-10-10 Finalized schematic, first run at board layout.
    [lora_nodemcu.kicad_pcb, lora_nodemcu.sch]
2017-10-10 update readme to note use of Wemo D1 mini instead of NodeMCU board.
2017-10-11 Relayed out board.
    [lora_nodemcu.kicad_pcb, lora_nodemcu.sch]
2017-10-14 Added cut-out and missing ground connector.
    [lora_nodemcu.kicad_pcb]
2017-10-17 fixed traces, added 3.3v power management
    [lora_nodemcu.kicad_pcb, lora_nodemcu.sch]
2017-10-18 backup save for prosperity
    [lora_nodemcu.kicad_pcb]
2017-10-18 Finalized PCB
    [lora_nodemcu.kicad_pcb]
2017-10-18 Added Gerber Files
    [lora_nodemcu-B.Cu.gbl, lora_nodemcu-B.Mask.gbs, lora_nodemcu-B.SilkS.gbo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]
2017-11-15 added enclosure 3d file and renamed kicad dir to hardware
    [disaster_radio_enclosure.stl]
2017-11-15 Missing caps need to be added to voltage regulator. Making a save to repo before pushing to Sudomesh repo.
    [lora_nodemcu.kicad_pcb, lora_nodemcu.sch]
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2017-11-15 Adding in all files that previously didn't get merged.
    [lora_nodemcu-B.Cu.gbl, lora_nodemcu-B.Mask.gbs, lora_nodemcu-B.SilkS.gbo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]
2017-11-21 missing D1_mini footprint
2017-11-21 missing wemos mini footprint
2017-11-28 Saving changes to circuit board prior to reworking yet again.
    [lora_nodemcu.kicad_pcb, lora_nodemcu.sch]
2017-12-06 Added new caps and connection points.
    [lora_nodemcu.kicad_pcb, lora_nodemcu.sch]
2017-12-06 updated fill plane
    [lora_nodemcu.kicad_pcb]
2017-12-20 new capacitors and a different antenna connector.
    [lora_nodemcu.kicad_pcb]
2018-01-09 fixed non connect on schematic and moved decoupling caps closer
    [lora_nodemcu.kicad_pcb, lora_nodemcu.sch]
2018-01-09 added ground vias
    [lora_nodemcu.kicad_pcb]
2018-01-09 removed vias inside of pads
    [lora_nodemcu.kicad_pcb]
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2018-01-10 really really removed Vias and moved a few traces
    [lora_nodemcu.kicad_pcb]
2018-01-10 added ground plane keepout bellow SMA connector
    [lora_nodemcu.kicad_pcb]
2018-01-10 modified top silkscreen
    [lora_nodemcu.kicad_pcb]
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2018-01-10 updated bottom silkscreen and added fp-lib-table
    [lora_nodemcu.kicad_pcb]
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2018-01-24 short range chat working with no garbling, fixes #6
    [firmware.ino]
2018-01-30 updated gerber files
    [lora_nodemcu-B.Cu.gbl, lora_nodemcu-B.Mask.gbs, lora_nodemcu-B.SilkS.gbo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]
2018-01-31 changed antenna to solid gound pour
    [lora_nodemcu.kicad_pcb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]
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2018-03-06 Encreased copper clearance to fix solder mask issues
    [lora_nodemcu.kicad_pcb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]
2018-03-08 cleaned up footprint values and added BOM
    [lora_nodemcu.kicad_pcb, lora_nodemcu_bom.csv]
2018-03-08 Updated Gerber Files with larger copper clearence
    [lora_nodemcu-B.Cu.gbl, lora_nodemcu-B.Mask.gbs, lora_nodemcu-B.SilkS.gbo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]
2018-03-17 Changes erroneous 0k to JUMPERS
    [lora_nodemcu.sch, lora_nodemcu_bom.csv]
2018-03-17 connects two lines on schematic that I missed in last commit
    [lora_nodemcu.kicad_pcb, lora_nodemcu.sch]
2018-03-17 Adds board version 3
    [lora_nodemcu.kicad_pcb, lora_nodemcu.sch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]
2018-03-20 changes jumper resistors to bridged solder points
    [lora_nodemcu-B.Cu.gbl, lora_nodemcu-B.Mask.gbs, lora_nodemcu-B.SilkS.gbo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]
2018-03-20 forgot to include save of kicad pcb
    [lora_nodemcu.kicad_pcb]
2018-03-21 added info on ordered boards
    [lora_nodemcu-B.Cu.gbl, lora_nodemcu-B.Mask.gbs, lora_nodemcu-B.SilkS.gbo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]
2018-04-04 completes layout of board with most 3d shapes
    [lora_nodemcu.kicad_pcb, lora_nodemcu.sch]
2018-06-05 added latest enclosure
    [d.r-a.stl, d.r-b.stl, disaster_radio_enclosure.stl]
2018-06-05 re-added old enclosure
    [disaster_radio_enclosure.stl]
2018-06-20 solar module flashing fixed, makefile update to latest version and readme updated with new instructions for flashing
    [firmware.ino]
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2018-08-14 fixed buffer bug, adding hop counter
    [firmware.ino]
2018-08-17 remove slash before index.htm, fixes bug with SPIFFs fallback
    [firmware.ino]
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2018-09-17 makes tx non-blocking related to https://github.com/sudomesh/disaster-radio-simulator/issues/2
    [firmware.ino]
2018-10-20 generalize routing library and sync with bug fixes from simulator
    [firmware.ino]
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2018-11-14 add start of disaster radio board v4
    [lora_nodemcu.kicad_pcb, lora_nodemcu.sch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]
2019-07-29 Compiles but make doesn't currently complete, error 'xtensa-esp32-elf-ar: stdlib_noniso.c.o: File format not recognized'
    [firmware.ino]
2019-07-29 Correct board we are using
2019-11-06 renamed irqPin to DIOPin, corrected pin assignment for DIO, bumped arduino-LoRa to 6.1.0 to allow asynTX
    [firmware.ino]
2019-11-06 adding incoming packet buffer to solve crashing during onReceive callback, bumping to latest arduino-esp32 and ESPAyncWebServer
    [firmware.ino]
2019-11-12 adds new ESP32 board
    [ESP32-DevKitC-V4-(ESP32-SOLO-1)-BOMList(V1.2)-20180621A.xlsx, ESP32-DevKitC-V4-(ESP32-WROOM-32)-BOMList(V1.1)-20180607A.xlsx, ESP32-DevKitC-V4-(ESP32-WROOM-32D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]
2019-11-13 removes MPPT IC and adds battery load switch
    [board_esp32.sch]
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2019-11-20 updates pin routing on ESP32
    [board_esp32.sch]
2019-12-11 adds all footprints and starts work on routing out board ESP32
    [board_esp32.kicad_pcb, board_esp32.sch]
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2019-12-17 adds changelog and pcb components are organised
    [board_esp32.kicad_pcb, board_esp32.sch]
2019-12-18 finishes placement and starts routing
    [board_esp32.kicad_pcb, board_esp32.sch]
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2020-01-14 finishes up layout of board_esp32
    [board_esp32.kicad_pcb, board_esp32.sch]
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2020-01-22 add a few more vias and generates GERBERs for board_esp32
    [board_esp32.kicad_pcb, board_esp32.sch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]
2020-01-27 updating README, revert to original SSID prefix, remove debugging from Console.cpp
    [main.ino]
2020-01-29 adding build environments and pin definitions for heltec-v2 board, fixes 40
    [config.h]
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2020-02-03 updates board_esp32 to fix manufacture issue with annular ring size
    [board_esp32.kicad_pcb, board_esp32.sch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]
2020-02-07 Add BLE client, add custom partition table to hold larger app, add Sparkfun 1ch ESP32 gateway to platformio.ini, adapt main.ino to enable BLE usage instead of web sockets
    [custompart.csv]
2020-02-21 modify platform.ini to default, add missing USE_BLE condition
    [main.ino]
2020-02-24 Fix main.ino Welcome Message, BLE client, OLED client and Console.
    [BleUartClient.cpp, OLEDClient.cpp, main.ino]
2020-02-26 Some more fixes in main.ino, BleUartClient, LoRaClient, TCPClient and WebSocketClient. Rewrite of all History functions. Added settings to save username and interface selection (WiFi or BLE) permanen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
    [BleUartClient.cpp, HistoryMemory.cpp]
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2020-02-26 adds interactive bom to board_esp32
    [board_esp32.kicad_pcb]
2020-04-08 remove remaining Serial prints from Console, add utils library, related to #65
2020-05-06 adds version two of the esp32 board, work in progress
    [E22-900M22S v2.step, ESP32-DevKitC-V4-(ESP32-SOLO-1)-BOMList(V1.2)-20180621A.xlsx, ESP32-DevKitC-V4-(ESP32-WROOM-32)-BOMList(V1.1)-20180607A.xlsx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]
2020-05-14 add support for LoPy4, fixes #42
    [OLEDClient.cpp, config.h, main.ino]
2020-05-19 testing possible restructure
    [custompart.csv]
2020-08-16 fix print out of local address to console, uses datagram now
2020-08-18 add get config command to print current configuration of Layer1 and LL2
2020-08-19 Update package-lock.json
    CVE-2019-10744
    critical severity
    Vulnerable versions: < 4.6.2
    Patched version: 4.6.2
    Affected versions of lodash are vulnerable to Prototype Pollution.
    The function defaultsDeep could be tricked into adding or modifying properties of Object.prototype using a constructor payload.
    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
2020-08-21 adds dutyCycle setting from console, fixes #52, refactors console command functions and usage printouts
    [config.h, settings.cpp]
2020-08-26 print info when gps reading fails, related to #87
    [main.ino]
2020-08-26 Finish implementing fixes and pin changes for board_esp32_v2.
    [board_esp32_v2.kicad_pcb, board_esp32_v2.sch]
2020-09-05 remove DATAGRAM_MESSAGE constant and use MESSAGE_LENGTH from LL2 instead, fully fixes #88
    [main.ino]
2020-09-13 fix error in using RadioLib with TGGO
    [main.ino]
2020-09-17 adds board_esp32_v3
    [E22-900M22S v2.step, ESP32-WROOM-32U--3DModel-STEP-56544.STEP, board_esp32_v2.sch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]
2020-10-07 Improve Wifi
    This commit makes connecting to an existing WiFi more robust
    and adds the missing `secrets.h` file for WiFi configuration.
    [main.ino]
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2021-08-07 Initial changes to specify pins for dual SX1276 modules and board def for platformio
2021-08-08 Removed redundant defines, changed platformio.ini to use esp32dev target w/ correct ram size for esp32-wroom-32u
    [config.h]
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2021-11-24 Uncommenting Arduino-LoRa lines, ifndefs added in Layer2 to fix preprocessor problems
    [main.ino]

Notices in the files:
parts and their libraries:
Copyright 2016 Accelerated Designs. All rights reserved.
